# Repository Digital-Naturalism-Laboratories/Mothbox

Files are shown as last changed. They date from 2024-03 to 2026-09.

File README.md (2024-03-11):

# Mothbox
Developing an open source,low cost automated system for Moth-Lighting photography 





look at the wiki for up to date information on assembly and usage
https://github.com/Digital-Naturalism-Laboratories/Mothbox/wiki

It's a compact, low cost device you can get running with simple modifications of off-the-shelf parts! And no soldering really needed!


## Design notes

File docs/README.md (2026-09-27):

# Updates: 
The project has grown so much that we are in the process of re-organizing the github. 
Other parts of the repo will be split out into separate repositories such as:
* Post-Processing [Mothbot Process](https://github.com/Digital-Naturalism-Laboratories/Mothbot_Process) and [Classify](https://github.com/Digital-Naturalism-Laboratories/mothbot-classify)
* [Firmware (Rpi Scripts)](https://github.com/Digital-Naturalism-Laboratories/Mothbox_Firmware)
* [Hardware](https://github.com/Digital-Naturalism-Laboratories/Mothbox_Hardware)
* [Electronics Development (PCB)](https://github.com/Digital-Naturalism-Laboratories/Mothbox_Electronics)
* [Data Visualization](https://github.com/Digital-Naturalism-Laboratories/Mothbox_DataVisualization)

This main github repo will continue to host the
* Documentation / Website
* History of the project up to February 2026

To make it easier to access specific files or scripts.

# Mothbox Pro and DIY
The Mothbox is a low-cost, [high-performance insect monitor](https://digital-naturalism-laboratories.github.io/Mothbox/docs/about/specs/). It features a power efficient and lightweight design meant to help field biologists deploy it in the depths of the jungles, and its low-cost nature means you can build one to study the biodiversity at your home!

All the physical designs, electronics schematics, Pi Scripts, and insect-IDing Artificial Intelligence are **provided free and open source**, so you can build, share and improve on these designs yourself!

See the project website for all the details:
[https://digital-naturalism-laboratories.github.io/Mothbox/](https://digital-naturalism-laboratories.github.io/Mothbox/)

See the [full specifications of what it can do here.](https://digital-naturalism-laboratories.github.io/Mothbox/docs/about/specs/)

PXL_20240720_054408351 MP-EDIT



## What it Does

The Mothbox stays in an ultra low-power state until your schedule tells it which nights to wake up. Then it triggers an insect lure (usually a bright UV light) and then takes ultra-high resolution photos of the visitors it attracts. 
PXL_20240607_025924783 NIGHT-EDIT

Next we created some open-source AI scripts that process these insects for you. First, a trained YOLO v8 detects where all the insects are in the images and crops them out. 




Then we use BioCLIP via the [pybioclip](https://github.com/Imageomics/pybioclip) package, with a [FiftyOne](https://github.com/voxel51/fiftyone) user interface, to help you automatically group and ID the insects to different taxonomic levels!


# Build it Yourself!
PXL_20240810_155421647 MP

This Mothbox documentation will provide you with documentation for how to source, build, program, and use your mothbox!

[Get started building your mothbox!](https://digital-naturalism-laboratories.github.io/Mothbox/docs/building)

After following these guides, you should be able to make your own set of mothboxes to conduct your own biodiversity studies!




## Why Study Insects for Conservation?
Insect populations can be used as an ultra high resolution sensor for changes in environments.

### Insects (Especially Moths and Beetles) are Hyperdiverse
Of all life on earth (including bacteria) there are about 2 million species scientists have described and [half of the species are insects!](https://ourworldindata.org/how-many-species-are-there#:~:text=In%20the%20chart%2C%20we%20see,reptiles%2C%20and%20over%206%2C000%20mammals.) What's more, if you look at **just Moths** there are about 144,000 species, meaning **about 1 in every 14 species in the world is a moth!** For reference there are only about 11,000 bird species, and only 6500 species of mammals (and half are bats and rodents). 

Using creatures with a super diverse gene pool allows us to make sophisticated insights into the health of different areas. Combining the activity of thousands of species of insects with other data like climate, acoustic, or soil analysis, can provide deep analysis into how environments can be repaired.

### Offer Highly Localized Insights
Because they tend to have short lives and often limited ranges, insects can provide super localized data. 

For comparison, think about something like a Jaguar, which is a rare find and scientifically valuable to see on a wildlife camera, but they have large ranges and long lives. The presence of a Jaguar does not necessarily tell us much about the health of the environment where it was spotted. It could simply be travelling across disturbed farmland to escape from a destroyed habitat elsewhere. 

Having an insect sensor (like a Mothbox), however, that could compare the activity of thousands of different species of insects can highlight differences in environmental health in areas just a couple kilometers apart.

### They are Easy to Attract
Humans have long ago discovered that many nocturnal insects like Moths seem to be attracted to lights. We now know this is because [bright lights disorient their natural steering mechanism](https://www.nature.com/articles/s41467-024-44785-3). Scientists have used bright artificial lights for over a century now to take censuses of insect populations. The problem with this type of "Mothlighting" is that it can be incredibly time consuming (a scientist has to hang out all night and note which insects are visiting). Instead we have an automated device that does all this work for you!

# Mothbeam
We are also building an open-source, portable low cost light for mothlighting, the Mothbeam! Some early documentation for [making your own Mothbeam is here.](https://digital-naturalism-laboratories.github.io/Mothbox/docs/building/mothbox_diy/attractor/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)


PXL_20240718_190826331 MP

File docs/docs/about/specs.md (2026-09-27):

---
layout: default
title: Specifications
parent: About the Mothbox
has_children: false
nav_order: 1
---

The exact specifications of the mothbox may change depending on factors like which microcontroller or power source you choose.

## Physical Size
* Weight: 2500 grams
* Size: 11"L x 7"W x 4"H (box)
* Target Sizes
  * Standard: 29cm x 20.5cm
  * Dual: 41cm x 29cm
  * Quad XL: 54cm x 41cm

## Cost

* Approximate cost: $375

## Power

* Battery: Talentcell PB120B1 - 12V Lithium ion, Rechargeable 142.08Wh 38400mAh
* [Additional Power Inputs](https://digital-naturalism-laboratories.github.io/Mothbox/docs/building/external_parts/powersources/):
  * Solar (up to 18V 60 watts),
  * Extra Batteries
    * can [daisy chain up to 3 Talentcell PB120B1 batteries](https://digital-naturalism-laboratories.github.io/Mothbox/docs/building/external_parts/powersources/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)
    * or connect other DC batteries (like a car battery)
  * continuous DC power (can plug into a wall if near a power grid)
* Sleep time: 6 months
* Runtime: 18 hours continuous (1 minute photography intervals with 2 internal mothbeams at standard power setting)
  * About 85% of the power goes to the UV attractor connected. Lower power UV lights can last longer, higher power lights will reduce its runtime
  * Our standard schedule has 5 hours of runtime per night, which means a normal Mothbox can run for 4 nights before recharging.

## Imagery
* Camera: Arducam 64mp Owlsight OV64A40
* Image resolution: 9152×6944 (Pi5)  9000x6000 (Pi4)
* Lens Adapter size: 55mm
* Pixels per mm: 15 (based on standard-sized target distance)

## Weatherproofing
* Fully harsh weather resistant. Has been left outside for >1 month in the rainforest.
* Probably not submergable (don't use mothbox underwater, yet)

## Microcontroller  
* Microcontroller: Raspberry Pi5 (2GB or 4GB)

## License
* MIT License
* CERN OHL-W

The Mothbox is an open source hardware and software tool for science. All the aspects of the Mothbox are freely licensed so that you can make it yourself, remix, customize, and build upon. The only things you cannot do are stop others from using this, claiming these designs or ideas as your own, or holding us liable for any aspect of this device. It is a build and use at your own risk tool.

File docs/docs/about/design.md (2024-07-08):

---
layout: default
title: Design Concepts
parent: About the Mothbox
has_children: false
nav_order: 6
---
The Mothbox is a tool for studying insect biodiversity, but the way in which is was created aimed to incorporate several key design concepts.

# Replicable
## Open Source
First and foremost, this is an open-source science project! Like **EVERY** scientific tool, all the information in the hardware and software should be freely available. This is extremely important as the scientific process is broken if the tools used to conduct research are not open and accessible. All the software, hardware designs, and documentation is provided free to use and at your own risk without warantee. 

The Open source nature of this is also important to science since it allows other researchers to remix and redesign this project to fit the purposes of other projects. For instance, another researcher is already remixing a mothbox to take high resolution scans of 96-well plates growing various fungi.

## Off-the-shelf parts

## Low Cost

# Simple Flat Design

The mothbox is designed so that all parts can be cut from flat planar material. It is more difficult to design a complex 3D electronic device using only 2 dimensional pieces, but there are several reasons for choosing this approach.

## Cross-Compatibility with multiple manufacturing techniques
Objects that are designed flat can be used in a wide variety of manufacturing techniques. Objects that are designed to be 3D printed generally can only be reproduced by 3D printers.
Instead these devices can be Laser cut, water-jet cut, CNC milled, 3D printed, cast, or even printed onto paper, traced, and manually cut out of something like 3mm plywood. Fully 3D objects intended to be 3D printed can be dif

## Speed of manufacturing
Flat parts can also be rapidly quickly. An entire mothbox can be laser cut in under 20 minutes, whereas a 3D printed version could take several hours. This is especially important to us as the designers since we are rapidly changing around the design to hone its abilities as a field instrument.

#Iterative Contextual Testing

# Field Repairable

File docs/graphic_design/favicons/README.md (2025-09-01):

# croppedlogonotext_4000px_Transparent_Square_Colored - Favicon Package

This package contains all the favicon files and configuration needed for complete browser and platform support.

## 📁 Files Included

### Standard Favicons
- `favicon.ico` - Traditional favicon (16x16, 32x32, 48x48)
- `favicon-16x16.png` - Small favicon for browsers
- `favicon-32x32.png` - Standard favicon for browsers

### Apple Touch Icons
- `apple-touch-icon-180x180.png` - iPhone 6 Plus, iPhone 6s Plus, iPhone 7 Plus, iPhone 8 Plus, iPhone X, iPhone XS, iPhone XS Max, iPhone 11 Pro Max
- `apple-touch-icon-152x152.png` - iPad, iPad mini
- `apple-touch-icon-120x120.png` - iPhone 6, iPhone 6s, iPhone 7, iPhone 8, iPhone SE
- `apple-touch-icon-76x76.png` - iPad (iOS 7+)
- `apple-touch-icon-60x60.png` - iPhone (iOS 7+)

### Android & PWA Icons
- `android-chrome-192x192.png` - Android homescreen icon
- `android-chrome-512x512.png` - Android splash screen icon
- `site.webmanifest` - PWA manifest file

### Microsoft Tiles
- `mstile-150x150.png` - Windows 8+ tiles
- `browserconfig.xml` - Microsoft browser configuration

### Additional Files
- `favicon-meta-tags.html` - Complete HTML meta tags
- `README.md` - This file

## 🚀 Installation

1. **Upload all files** to your website's root directory
2. **Copy the HTML meta tags** from `favicon-meta-tags.html` into your website's `<head>` section
3. **Test your favicons** using online favicon checkers

## 💡 Usage Tips

- Place all files in your website's root directory (e.g., `https://yoursite.com/favicon.ico`)
- The HTML meta tags should be placed in the `<head>` section of every page
- Test on different devices and browsers to ensure proper display
- Consider using a CDN for better performance

## 🔧 Advanced Configuration

### PWA (Progressive Web App)
Your `site.webmanifest` file enables PWA features:
- Add to homescreen functionality
- Splash screen customization
- App-like experience on mobile

### Microsoft Integration
The `browserconfig.xml` file configures:
- Windows 8+ tile colors
- Tile icon selection
- Browser-specific settings

## 🌟 Features

- ✅ Complete browser support (Chrome, Firefox, Safari, Edge, IE)
- ✅ All device support (Desktop, Mobile, Tablet)
- ✅ Platform integration (iOS, Android, Windows)
- ✅ PWA ready with manifest.json
- ✅ Optimized file sizes

## 📱 Supported Platforms

- **Web Browsers**: Chrome, Firefox, Safari, Edge, Opera
- **Mobile**: iOS Safari, Android Chrome, Samsung Internet
- **Desktop**: Windows, macOS, Linux
- **Tablets**: iPad, Android tablets
- **PWA**: Progressive Web App support

## 🛠️ Generated with

This favicon package was generated using [Favicon AI](https://favicon-ai.com) - the free favicon generator with AI-powered optimization.

---

Need help? Visit [Favicon AI](https://favicon-ai.com) for more favicon tools and resources.

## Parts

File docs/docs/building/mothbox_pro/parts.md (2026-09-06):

---
layout: default
title: Parts
parent: Mothbox Pro
#has_children: true
nav_order: 0
---
# Parts

To build a Mothbox Pro, you will need these parts (prices are estimates and fluctuate):
- [Download 3D Printed parts](https://github.com/Digital-Naturalism-Laboratories/Mothbox_Hardware/tree/main/Mothbox_Pro/)
- [Download Laser cut parts](https://github.com/Digital-Naturalism-Laboratories/Mothbox_Hardware/tree/main/Mothbox_Pro/Laser%20Cutting)

MB pro all parts 20260209_160744

## Electronics
This newest version of the Mothbox has easy to assemble electronics! You only need



* [Mothbox Mainboard](https://digital-naturalism-laboratories.github.io/Mothbox/docs/building/mothbox_pro/manufacture/) - a Printed Circuit Board (PCB) with most electronics already connected up for you! - $50
* [Mothbeam Boards](https://digital-naturalism-laboratories.github.io/Mothbox/docs/building/mothbox_pro/manufacture/) - Little, super bright, metal LEDs that plug in to your Mainboard (up to 3) - $5 each
* [Raspberry Pi 5 4GB](https://www.sparkfun.com/raspberry-pi-5-4gb.html) (or higher) - $75  (Our latest firmware LOOKS like it works with a [Pi 5 2GB](https://www.sparkfun.com/raspberry-pi-5-2gb.html), but we have not thoroughly tested)
* [SD Card](https://www.amazon.com/dp/B0CQX2B25W?ref=ppx_yo2ov_dt_b_fed_asin_title) - 32GB or bigger, Class A1 or faster (A2 is nice) - $15
* [USB Storage](https://www.amazon.com/dp/B0BN3Q1M96?ref=ppx_yo2ov_dt_b_fed_asin_title) - 32 GB or bigger
* [Pi 5 RTC Battery](https://www.sparkfun.com/raspberry-pi-rtc-battery.html) - $8
* [Talentcell PB120B1](https://www.walmart.com/ip/Millertech-PB120B1-12V-Lithium-ion-Talentcell-Battery-Pack/5119418367) - You can actually use any battery between 9-36 V to power the mothbox (it's more efficient around 12V), but for these tutorials we will use the main battery we use for all our devices, this one by Talentcell - $80
* [9-36V to 12V voltage Regulator](https://www.amazon.com/dp/B0B6VK8BPN?ref=ppx_yo2ov_dt_b_fed_asin_title) - $15
* [Arducam 64 MP Owlsight camera](https://www.amazon.com/dp/B0CQJPKFVF?ref=ppx_yo2ov_dt_b_fed_asin_title) - $55 (Don't get the "Hawkeye" older version of this camera if you can avoid it!)
* [Barrel Jack Sockets and Plugs](https://www.amazon.com/dp/B0D9B7WR23?ref=ppx_yo2ov_dt_b_fed_asin_title) (x2) - $2
* [Lever Nut](https://www.amazon.com/dp/B0CBP7WWML?ref_=ppx_hzsearch_conn_dt_b_fed_asin_title_1&th=1) - 2 wire connector - $0.40
* (Optional, but VERY USEFUL) [Epaper Display (Waveshare 2.13in E-ink hat)](https://www.amazon.com/dp/B0D22JJ18B?ref=ppx_yo2ov_dt_b_fed_asin_title) - $15



## Attractors

* [Mothbeams](https://github.com/Digital-Naturalism-Laboratories/Mothbox_Electronics/tree/main/Mothbeam_PCBs/AndyMothbeam_forMBv5.0.1) can plug right in to the PCB
* External - You can also connect any 12V attractor you want via the "External attractor" port

## Zip Ties
  * [7 really thin ones](https://www.amazon.com/dp/B07W98YW6J?ref=ppx_yo2ov_dt_b_fed_asin_title)
  * 8 typical width
  * 2 really big

## 3D printed parts
[Download 3D Printed parts](https://github.com/Digital-Naturalism-Laboratories/Mothbox_Hardware/tree/main/Mothbox_Pro/)
We used [PETG-Carbon Fiber](https://www.amazon.com/dp/B0FC6H71B1?ref=ppx_yo2ov_dt_b_fed_asin_title) (regular [PETG](https://www.amazon.com/dp/B0FC6H7FBL?ref=ppx_yo2ov_dt_b_fed_asin_title) will also be fine) and [TPU Filaments](https://www.amazon.com/dp/B0B6FMVJ2H?ref=ppx_yo2ov_dt_b_fed_asin_title&th=1)


  
  * Inner Chassis
  * Outer Shell
  * Camera Glare Blocker
  * Front Lid
  * Back Lid

For really wet places
  * TPU Gasket - Front
  * TPU Gasket - Back

## Laser Cut Parts
[Download Laser cut parts](https://github.com/Digital-Naturalism-Laboratories/Mothbox_Hardware/tree/main/Mothbox_Pro/Laser%20Cutting)

  * Front Acrylic Window
  * Arms
  * Target
  * (Includes alternative files for if you want to laser cut your front and bask gaskets with [laser cutting rubber](https://www.amazon.com/dp/B08Q7CTSJL?ref_=ppx_hzsearch_conn_dt_b_fed_asin_title_12) instead of printing in TPU)

## Connectors
To hold the lid on and the legs on you have 3 options:
* Re-usable zip ties
* Rubbery Silicone Ties
* 3D printable TPU ties

## Screws
* #6 x 3/8" screws (or 6g x 9mm)

# Tools
Here's some tools you need:

* Screwdriver
* Wire Strippers
* Hot Glue Gun

Bonus tools could also be useful:
* Flat Snips (Scissors could maybe work too)

**Total Estimate: $350**

# Bonus Parts
You can also add:
* [Cheap Epaper display](https://www.waveshare.com/2.13inch-e-Paper-HAT.htm) - ($15USD) to know what your Mothbox is up to!
* External temperature sensor - Connects to a port on the PCB
* Cheap GPS - gives super accurate timestamps and can automatically locate your mothbox - plugs in to ports on PCB - [5 pin](https://www.amazon.com/dp/B0B31NRSD2?ref_=ppx_hzsearch_conn_dt_b_fed_asin_title_1) or [4 pin](https://www.amazon.com/dp/B0CWL774NR?ref_=ppx_hzsearch_conn_dt_b_fed_asin_title_1)

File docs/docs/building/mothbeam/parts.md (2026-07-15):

---
layout: default
title: Parts
parent: Mothbeam (Insect Attractor)
#has_children: true
nav_order: 1
---

# Parts

For this tutorial, we will show you how to make a very simple mid-range housing we call the "Basic Circular Housing"



# Parts for Basic Circular Housing
* [PCBs](https://github.com/Digital-Naturalism-Laboratories/Mothbox_Electronics/tree/main/Mothbeam_PCBs/AndyMothbeam_forMBv5.0.3) (ideally 2 or 4)
* 18awg solid core wire (red and black)
* 20x20 aluminum profile (15cm long)
* Circular Plexiglass tube, 6.5cm diameter (make sure transparent to UV) (10cm long)
* Laser cut acrylic [Top and Bottom lid](https://github.com/Digital-Naturalism-Laboratories/Mothbox/tree/main/Hardware/Mothbeam_Housing/Mothbeam_CircularHousing)
* Cable Ties (Basic nylon high heat resistant) (Preferably very thin)
* (optional) Silicone heat transmitting pads
* (optional) DC barrel jack (socket and plug)
* (optional) Electronic Snap connectors

# Tools Needed
* Hot Glue Gun (Or epoxy)
* Wire Strippers
* Saw (if needing to cut housing tube or metal)



# Core Component Overview
A mothbeam is easy to put together and has 3 main parts:

* PCB
  * The electronic LED board that shines really bright (generally UV or Visible Options)
  * generally made on alumnimum backing to help shed heat. (Copper could work too, but it's expensive!) 
* Heatsink
  * usually a piece of metal to help dissipate the heat to give the LEDs a longer life
* Housing
  * Something to protect the electronics from travel or the elements

## PCB

The PCB's are a [certified open source hardware design originally by Moritz](https://certification.oshwa.org/de000156.html). We have [remixed them to easily connect to our Mothbox PCB](https://github.com/Digital-Naturalism-Laboratories/Mothbox_Electronics/tree/main/Mothbeam_PCBs/AndyMothbeam_forMBv5.0.3).

To get one, you can:
* order a Mothbeam directly from Moritz in Germany emailing him (moritz@lablab.eu)
* use the [open source files](https://github.com/Digital-Naturalism-Laboratories/Mothbox_Electronics/tree/main/Mothbeam_PCBs/AndyMothbeam_forMBv5.0.3) to create your own PCBs yourself (or via something like JLCPCB) (remember they need to be aluminum PCBs)
* [order them from something like circuithub](https://circuithub.com/projects/Moritz/Mothbeam/revisions/57895/parts) (the most expensive way)

## Heatsink
The heatsink just needs to be something big and metal we can connect the PCB to.

## Housing
The flexibility of this low cost device means you can put together different types of housings however you need.

You can go super low-cost and just put it in a recycled sports-drink bottle



or you can [laser cut a fancier flat-pack design](https://github.com/Digital-Naturalism-Laboratories/Mothbox_Hardware/tree/main/Mothbeam_Case/Mothbeam_Flatcontainer)



you can even use the basic concepts in this tutorial and make a "Mega Mothbeam" by just using more PCBs and longer heatsink.



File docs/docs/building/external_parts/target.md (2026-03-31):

---
layout: default
title: Create Target
parent: External Parts
#has_children: true
nav_order: 4
---

There's many ways point your Mothbox at something! Here are the [laser cutting design files for your target!](https://github.com/Digital-Naturalism-Laboratories/Mothbox_Hardware/tree/main/Targets)

The Mothbox's default software will automatically calibrate its focus and exposure to whatever kind of target is positioned in front of it. The main thing is that it should probably be 
* white
* flat
* easy for insects to perch on

PXL_20240808_232453558 MP

We have found that acrylic felt works quite well for insects to walk around on, to stay clean and not mold, and as a bright, light-diffusing backdrop.

# Target Options
We have four main options for your target. We have done most of our testing with the Standard Target, so the other options are still a bit more experimental.

The [Standard Target](https://digital-naturalism-laboratories.github.io/Mothbox/docs/building/external_parts/target/#standard-target) is the most compact surface for the Mothbox. It also can be lit up quite easily from lights inside the mothbox.

The [Minimalist Target] was inspired by the Lepisense crew who have been using just a peice of rough-surfaced acrylic. You can just purchase "textured" acrylic sheets in some places, but if that's not available, we have used a rough-grit sander to just roughen one side of a piece of acrylic. Follow the same instructions as the "Standard sheet" but don't worry about the felt part. Just sand it to rough it up after.

The [Dual Target](https://digital-naturalism-laboratories.github.io/Mothbox/docs/building/external_parts/target/#dual-target) doesn't require any additional materials other than cutting an extra target shape. It can also fold in half so it doesn't take up much more room than the Standard Target! So you can pretty much double your target area with minimal changes.

The [Quad Target](https://digital-naturalism-laboratories.github.io/Mothbox/docs/building/external_parts/target/#quad-target) is 4X bigger than the standard target. Because of its size, it is not as easy to travel with. This large target also needs to be positioned further away from the Mothbox, which means the amount of pixels per insect will be reduced. It can work great for areas where you are looking for larger and abundant moths.

The ["Just Point it at Something"](https://digital-naturalism-laboratories.github.io/Mothbox/docs/building/external_parts/target/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) option works if you have some other surface you are using as a moth target. You can use the arms to measure a distance if you want, but you can just point the Mothbox at a wall or sheet. 

# Standard Target
Building the targets is straightforward. You just glue the target material to the target. Using a spray adhesive tends to work well.



1. Spray one side of your target material with glue.
2. Make sure the protective plastic is peeled off the acrylic target
3. Lay the target material on top of the side of the target with the inverted logo. You will be covering up the logo.
4. Lay some clean, heavy, flat things on top of the target (to help make it extra flat)
5. Let dry for a couple hours




# Dual Target
The process is similar to the Standard Target, but you need to cut out two target surfaces. Put their smooth, long edges together.
PXL_20240808_200847224 MP

Spray the double-wide target material felt with the adhesive spray.

Carefully align it with the two target backings.
PXL_20240808_201107616 MP

Place something clean, flat, and heavy on top of them.

PXL_20240808_201146040 MP

Now the Double Wide target material functions as a sort of hinge you can use to close the target and protect it when in transit. You probably need to tape the back when deployed to keep it rigidly open. This probably could use a design tweak.

## Prepare Arms for Dual Target

The dual target can fit at the end of the arms in their standard configuration, but they will fill up the camera image entirely. If you want to have a safe margin around the edges of the dual target, you can adjust the arms one notch outward, which moves them about 7 cm outward.

# Quad Target
PXL_20240808_233028726 MP

The quad target design is the size of 4 of the standard targets. If you are desperate, you could literally just set 3 standard targets next to each other in a square and tape them all together.
But the stability might be weird.

Instead, we included a design to cut out a single large target. We used coroplast (corrugated plastic polypropylene). It's lightweight, sturdy, an cuts easily. You can also make it foldable by making a slit up one side of the corrugation,but you will need to figure out a way to make it sturdy. Some tape will work.

Cut out your large target.
PXL_20240808_161011251 MP

Cut out its felt material.

PXL_20240808_162242291 MP

Spray the felt material with spray adhesive.

PXL_20240808_200351402 MP

PXL_20240808_200439729 MP

Lay a clean, flat, heavy thing on top.

PXL_20240808_200658541 MP

PXL_20240808_200753893 MP

Let dry for a couple hours.

## Prepare Arms for Quad Target
Stagger your arms with some extra bolts.

PXL_20240808_190821702 MP

With the extra large target, it might make sense to use the [External Attractor](https://github.com/Digital-Naturalism-Laboratories/Mothbox/blob/main/docs/docs/building/attractor.md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) option since it is a bit further from the Mothbox.

PXL_20240808_234505819 MP

# Just Point it at Something
Depending on your setup, you might not actually need a dedicated target! We have used the Mothbox by just pointing it at a **white wall** with a bright light that insects were attracted to. Many people want to just point their mothbox at a sheet that they have hung up for traditional Mothlighting. This can totally work, BUT some things to keep in mind:
* The mothbox will autocalibrate its focus and exposure, but it only does this about every 6 minutes. Thus if it is pointing at a surface that sways or moves back and forth (possibly like a sheet in a light breeze), many of these images will not be in focus.
* The Mothbox is trying to image a full surface, which is different than when you try to take pics individually of specific insects on a moth sheet. Its visual field should be of a surface that is **as flat as possible,** or else parts of the image may be occluded by wrinkles.
* The lighting near the edges of a surface may not be as well illuminated as those near the middle.

PXL_20240905_120604101 MP

# Cleaning Target
Moths can be a bit grosser than you might think. They can poop a LOT. Look at this target I came back to one night. It got real gross.


## Bleach

You can use a 20% solution of bleach to scrub out most stains. Try not to rub too hard or the felt can get too fluffy, but in general it's quite easy to clean.
PXL_20240828_212120926 MP

## Have Backups Ready

Felt is cheap and lightweight, and you should probably have extra target material cut and on hand in case your current target accidentally gets messy.

We even upcycled our old felt together with old acrylic by just melting them all together with acetone.
PXL_20240822_162510025 MP

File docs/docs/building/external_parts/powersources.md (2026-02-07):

---
layout: default
title: Solar and Extra Batteries
parent: External Parts
#has_children: true
nav_order: 9
---

The Mothbox has an internal battery that can sample for about 4 nights on its own (22 hours of runtime). BUT maybe you want a SUPER POWERED Mothbox that can last even longer?!

Well, it's very easy to add solar panels or extra batteries to the Mothbox!

# Add a Solar Panel

This is pretty easy to do! Simply plug a DC barrel jack cable from your panel to the charging port.
PXL_20240810_225301762 MP

That's it!

PXL_20240810_225422782 MP

We talked to the Talentcell people who make the batteries. They said lots of solar panels will work, especially 18V panels up to 60Watts.**

{: .important }
> Panels should be max 18V and 60 watts

# Add Extra Batteries

This is also quite an easy addition. You can just plug a DC barrel jack cable from the output of one Talentcell battery to the input port of another! Easy as that! You just need to make sure that both batteries are fully charged.

{: .important }
> All batteries need to be fully charged if you connect them.

## Build a waterproof battery pack
You can make an extra power case to connect to your Mothbox in the field very easily. You just need an additional waterproof case.
You can drill a port exactly the same as when you create the input port for your Mothbox.
PXL_20240805_151231476 MP

Add a DC barrel socket to it. Connect a barrel jack plug with a lever nut. 
PXL_20240805_152446615 MP

Plug it into the OUT port of an extra Talentcell battery.
PXL_20240805_152622741 MP

Seal up the box and plug it into the input port of your fully charged Mothbox.
PXL_20240805_152712736 MP

## Double Battery Pack?
You bet! Again just make sure all the batteries are charged up fully.
Use a DC cable jack splitter (one usually comes with your Talentcell battery!)

PXL_20240805_152841330 MP

Plug it into BOTH OUTPUTs of the batteries in your pack.



And you are ready to have a Mothbox that can run for 66 hours! Or 12 nights!
PXL_20240805_153000284 MP

# Differentiating between 12V and 24V batteries

The easiest way to tell the difference is by looking at the back of the battery and see what voltage is listed under the input. The 24V one will say 29.4V and the 12V will say 12.6V.

12vMBbattexample 

*Example of a 12V battery*

24VMBbattexample

*Example of a 24V battery*

Another easy trick is that you'll notice the 12V batteries don't list the voltage on their sides, whereas the 24V one does. The 24V battery also has a little "groove" that sticks out further than the 12V one

Screenshot 2025-02-27 at 1 16 54 pm

Screenshot 2025-02-27 at 1 17 04 pm

A reminder that all 12V batteries are charged by a *black* charger, and all 24V batteries are charged by a *white* charger!

# More information on daisy chaining batteries

Do not charge batteries that are in parallel! It's ok to keep two batteries daisy chained together in parallel when charging *another* battery (i.e, the one in your Mothbox), but directly charging (i.e, from a wall plug) batteries in parallel can damage them. Make sure that when you are daisy chaining two or more batteries, the batteries all begin at the same charge level.

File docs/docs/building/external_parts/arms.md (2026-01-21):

---
layout: default
title: Arms
parent: External Parts
#has_children: true
nav_order: 3
---

# Arms 
Simply laser cut the dxf files out of clear acrylic (this helps give more surface area to your target). If needed you could use an opaque material.

{: .note }
> Each arm of the mothbox is made from 2 arms. This is for strength as well as redundancy. If one arm breaks in the field, you already have a backup!

# Peel the Plastic
Pull the protective plastic off the arms.


# Attaching Arms

## Off-the-shelf Case
Use 1/4in bolts to connect the arms to the box

## 3D Printed Case
With the 3D printed case you have multiple options for connecting the arms!

You can use 1/4 in bolts like before.


You can use re-usable cable ties.


Or, my favorite, is to use rubbery re-usuable ties.




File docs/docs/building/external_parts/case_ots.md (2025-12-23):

---
layout: default
title: Case (Off-the-Shelf)
parent: External Parts
#has_children: true
nav_order: 1
---

If your 3D printing capactity is limited, you can modify an off-the-shelf case that will protect your electronics
This is the Plano 1460-00 box. Others have also modified waterproof junction boxes with clear lids in a similar way.

The Mothbox has 2 main *external parts* that connect to the case
* Lens Connector
* Arms

# Modify the Box

## Drilling Arm Holes
You should start with 4 laser cut arms. 

{: .note }
> Each arm of the mothbox is made from 2 arms. This is for strength as well as redundancy. If one arm breaks in the field, you already have a backup!

Lay an arm against the outside of the large plastic flanges.


Use a marker to mark exactly where the holes are.
Using a 1/4in drill bit (6.5mm), cut two holes for the arm.

{: .note }
> I actually use a drill bit that is slightly larger than 1/4in, like 5/16in because my measuring and aligning abilities aren't always that great, and this gives you a little wiggle room.

Slide two 1/4in bolts through the holes and secure the arms.


Now you should be able to attach the target to the arms easily!


## Drill Front Lens Hole
These boxes are manufactured with a little dot directly in the center of the back of the box. 
You can use this as a reference point to drill a small pilot hole. When drilling this side of the box for the lens, make sure to always use a light pressure, as you don't want to press too hard and crack the box. 


After you have drilled the pilot hole, you can get out your 53 mm hole cutter bit. Align this bit with the pilot hole and drill out your hole.



Sometimes the edge of this hole can be a little rough and have extra plastic sticking up that can get in the way. You can use a deburring tool, or a razor, and go along the edge of this cut to clean it up.




## Epoxy the lens adapter into place

Mix together some 2-part epoxy on a piece of cardboard with a popsicle stick. 




Put a little bit of epoxy onto the rim of the hole you just cut. Add the lens adapter. Use a thin stick to slide around the edge and make sure the epoxy seeps into the seam between the lens connector and box. Look for air bubbles coming from the seam.


Then you can use a larger popsicle stick to smooth out the border of the epoxy and have a nice, thick seam connecting them.


Use a towel to clean up any epoxy that may have spilled on the inside of the lens adapter.


Once it is in place, and the epoxy is smooth and thick, let it sit aside for several hours to cure.





After the epoxy has dried, sometimes you may notice some white smudges inside your mothbox. It's not a big problem. These are from the fumes of some glues attaching to oils left from your fingers. This is actually how people do fingerprinting sometimes! You can just wipe it off with a clean, damp cloth.



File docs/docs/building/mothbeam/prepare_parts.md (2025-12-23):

---
layout: default
title: Prepare Parts
parent: Mothbeam (Insect Attractor)
#has_children: true
nav_order: 3
---



# Prepare Heatsink

You will either need to find a 15cm length of aluminum, or cut a piece yourself.


If you need to cut it, wear safety goggles and use a hacksaw or jigsaw with metal blade.





After it has been cut, make sure to let it cool, the fresh part can be quite hot!

Debur any metal bits on the edge. Remove any protective plastic.


# Prepare Acrylic Tube

You need a 10cm acrylic tube with a 6.5cm diameter (none of these measurements need to be too exact).


Generally you will find acrylic tubes in longer lengths you need to cut.

Use a plastic blade on a saw and cut off your tube.



# Laser cut end caps
You can use the designs to laser cut end caps for your acrylic tube. If you are using a different metal rod, you can always change the cutout to the profile of whatever rod you use!



If you want to be really fancy, after you etch the text, you can spray paint your acrylic (if it still has the protective plastic on it).




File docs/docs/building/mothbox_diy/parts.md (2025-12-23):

---
layout: default
title: Parts List
parent: Mothbox DIY
#has_children: true
nav_order: 1
---

The Mothbox uses a Raspberry Pi 5 (or Pi4 and Pijuice), a Talentcell Battery, and a 3 channel relay as its core.
The entire materials cost is **about $375** per mothbox. (This depends on the options you choose and the prices where you live). Note that many other similar tools for insect monitoring can cost between $7-$15K!

Below we try to include an up-to-date list for building an arbitrary number of Mothboxes.

Here's a [link to a list of most of the parts collected for you.](https://www.amazon.com/hz/wishlist/ls/3J2HLUOYNFFZG?ref_=wl_share)

# Electronics

## Core Electronics ($233)

### Raspberry Pi and Scheduling Devices
* [Raspberry Pi 5 (4GB and up)](https://www.sparkfun.com/products/23550) ($60)
  * you also need an SD card for the Pi. You should find one with speeds rated "A2" or higher. 64gb and up is nice.
* **plus** a [rechargeable RTC battery](https://www.sparkfun.com/products/23590) ($5)
* [USB A to C power cables (SHORT)](https://www.amazon.com/gp/product/B0C4NJYPTX/ref=ppx_yo_dt_b_search_asin_title?ie=UTF8&th=1)

OR
* [Raspberry Pi 4 (4GB and up)](https://www.sparkfun.com/products/15447) ($55)
* **plus** a [Pijuice](https://www.sparkfun.com/products/14803) ($100)
   * [Info Software](https://github.com/PiSupply/PiJuice)

### Camera

* [Arducam 64MP Autofocus Camera (Updated "Owlsight" "Native Libcamera" version)](https://www.amazon.com/Arducam-Raspberry-Resolution-Support-Libcamera/dp/B0CQJPKFVF?ref_=ast_sto_dp) ($60)
  * Make sure to get the above version called "Owlsight" (It's much easier to work with than the older "Hawkeye" version of Arducam's camera)  

### Power
* Battery : [Talentcell 12V Lithium ion Battery PB120B1](https://www.amazon.com/gp/aw/d/B07H8F5HYJ?psc=1&ref=ppx_pop_mob_b_asin_title) ($80) - This is the easier battery to work with, all 12V in and out.
* OR [Talentcell PB240b1](https://www.amazon.com/gp/product/B07SWBS55F/ref=ppx_yo_dt_b_asin_title_o00_s00?ie=UTF8&psc=1)  The PB120B1 started going out of stock sometimes, but this updated model should do fine (and has more battery capacity!). The downside is it can be a little trickier to wire up, because it has a 12V and 24V output, so you need to be careful!

* Relay Expansion Pi Hat (Waveshare 3x relay) ($18)
    * [Buy](https://www.amazon.com/RPi-Relay-Board-Raspberry-3-CH/dp/B085QJFWBC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)
    * [Info](https://www.waveshare.com/wiki/RPi_Relay_Board)
    * Remember you can also wire individual relays, but not solid state relays (they can't switch low DC voltage).
* 12V regulator / Step-Up Voltage Booster
   * [Buy](https://www.amazon.com/Stabilizer-DROK-Waterproof-Transformer-Television/dp/B081RG8XP5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)
   * This extends your battery life by keeping power to the 12V lights even if your battery voltage starts dipping low.
* [5.5 x 2.1 DC barrel jack cables](https://www.amazon.com/gp/aw/d/B0BZYGRYSQ?psc=1&ref=ppx_pop_mob_b_asin_image)
    * 2x socket ports (You actually only need 1 socket if you are keeping your UV light internal)
    * 2x plug ports
* (Optional) Power sensor for monitoring battery levels
   *[Buy](https://www.amazon.com/gp/product/B07S8QYDF8/ref=ppx_yo_dt_b_search_asin_title?ie=UTF8&psc=1)    

### Display (Optional) (18$)
* The latest versions of the Mothbox firmware support inexpensive e-ink displays! This is not needed for operation, but can be very useful for debugging or organizing mothboxes!
* [Waveshare 2.13in Eink Hat](https://www.amazon.com/waveshare-2-13inch-HAT-Compatible-Resolution/dp/B071S8HT76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) 

### Lighting ($60)
* Photography Lights (2x)
  * 2x [12V 144 LED ringlight](https://www.amazon.com/Vision-Scientific-VMLIFR-09B-Adjustable-Microscope/dp/B07VR2LJJL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) ($23)
  * The 144 LED ringlights seem to be about the brightest diffuse 12V LEDs you can find for the price. They are also quite ubiquitous and a standard(ish) form factor.
  * Purchase 2 of them.
  * 2.55" (65mm) inside and 3.75" (95mm) overall outside diameters.
* UV lights
    * 12V
        * Any UV light that accepts a 12V input will work easily, such as 
               [Cheap 12V Waterproof UV flood](https://www.amazon.com/dp/B07KHVZ7TG?psc=1&ref=ppx_yo2ov_dt_b_product_details) ($13)
        *  We are also using our custom "Mothbeams," which are like powerful, open source, bespoke, low cost lepileds. It currently costs about $80 to order them from Moritz at LabLab in Berlin [moritz at lablab.eu]
          *  Or you can order them from [Circuithub](https://circuithub.com/projects/Moritz/Mothbeam/revisions/57895/parts), but there they cost about $200-$400.  
    * 5V (Not Officially Integrated)
        * To reduce costs and additional parts, we do not design around an extra 5V output, though you can install one yourself pretty easily.
        * You can hack the system to use UV lights that take a 5V input pretty easily with just an inexpensive [high power 12V to 5V adapter](https://www.amazon.com/gp/product/B076ZLHLD3/ref=ppx_yo_dt_b_search_asin_title?ie=UTF8&psc=1).
        * These light bars are the absolute cheapest ones we can find that attract moths ($5) (395nm) [https://www.amazon.com/Black-Light-Bar-Glow-Party/dp/B09BCND2J9/](https://www.amazon.com/Black-Light-Bar-Glow-Party/dp/B09BCND2J9/).
        * Lepileds can also be connected.

* DIY Heatsink (For internal UV Lights)
  * Perforated Metal
    * [1-1.5mm Aluminum works well](https://www.amazon.com/dp/B0CN4RMFYQ/ref=dp_iou_view_item?ie=UTF8&th=1)
  * Metal Shears are handy
    * [Example 'Avaiation' Shears](https://www.amazon.com/Hurricane-02-024-Aviation-Straight-Vanadium/dp/B07GDDF5JB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)
  * [Thermal Silicone Strips](https://www.amazon.com/gp/product/B094PWW9TM/ref=ppx_yo_dt_b_search_asin_title?ie=UTF8&th=1)
  
# The Box ($25)

* [Plano 1460-00](https://www.amazon.com/gp/product/B003FYMVXM/ref=ppx_yo_dt_b_search_asin_title?ie=UTF8&th=1) ($25)
   * To be as compact as possible, we designed around the Plano 1460-00 case. It's cheap, waterproof, CLEAR, [quite available internationally](https://www.amazon.co.uk/Plano-Waterproof-Polycarbonate-Storage-Yellow/dp/B003FYMVXM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), and as compact as possible.
   * (sometimes called plano 3600) 11"L x 7"W x 4"H </span>

## Chassis, Arms, and Target Materials
* Plastic for laser cutting (the design is currently set for 3mm acrylic)
   * One 50x60cm piece of acrylic can fit all the parts, but you could cut from many scraps too.
* [White Felt Acrylic sheets](https://www.amazon.com/9x12-Acrylic-Material-Fabric-Supplies-Halloween-Costumes-6PC/dp/B0848X2RFN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)
   * minimum 205x305mm (8x12in)

## Camera Lens Gear ($20)
_We are turning the box into a kind of 55mm lens camera so accessories that work for a 55mm lens should work_

* UV Lens Protector and Mount 
    * Lens rings [https://www.amazon.com/dp/B005IMNI4K?psc=1&ref=ppx_yo2ov_dt_b_product_details](https://www.amazon.com/dp/B005IMNI4K?psc=1&ref=ppx_yo2ov_dt_b_product_details) ($3)
    * UV filter [Amazon.com : Tiffen 55UVP 55mm UV Protection Filter : Camera Lens Sky And Uv Filters : Electronics](https://www.amazon.com/dp/B00004ZCJH?psc=1&ref=ppx_yo2ov_dt_b_product_details) ($8)
   * Lens Hood - not strictly necessary, but helps keep extra rain off lens when deployed.
     * [buy (includes lens cap)](https://www.amazon.com/gp/product/B082HRGFP7/ref=ppx_yo_dt_b_search_asin_title?ie=UTF8&th=1) ($9)

## Field Additions
* Strap (Optional-To attach to tree)
  * [e.g.] (https://www.amazon.com/gp/product/B08BYHZGC4/ref=ppx_yo_dt_b_search_asin_title?ie=UTF8&psc=1)
* Lock (optional - to attach to tree if theft is a concern)
  * [e.g.](https://www.amazon.com/gp/product/B000XTPNZK/ref=ppx_yo_dt_b_search_asin_title?ie=UTF8&psc=1) 

# Data
* Micro SD Card (Recommended 64 GB and higher)
  * e.g. [128gb Microsd cards](https://www.amazon.com/gp/product/B0BYJH4ZJL/ref=ppx_yo_dt_b_search_asin_title?ie=UTF8&psc=1)
* USB storage (reccomended 64GB and higher)
    * e.g. [usb thumb drive](https://www.amazon.com/gp/aw/d/B09LLWTMXQ?psc=1&ref=ppx_pop_mob_b_asin_title)
* [Short USB extension](https://www.amazon.com/gp/aw/d/B00CJG2ZYM?psc=1&ref=ppx_pop_mob_b_asin_title) (can make taking usb drive in and out easier)

# Tools for Construction
Here's a list of the tools you need to actually create a Mothbox. If you are building **multiple** mothboxes, you likely only need one of these tools no matter how many you make.

## Hand Tools
* Small Screwdriver Set with Interchangeable Heads
  * [Ifixit has a great one](https://www.amazon.com/iFixit-Minnow-Driver-Kit-Smartphones/dp/B08NWJH6TD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)
* Wire Strippers
* Flush Cutters
  * Great for trimming zip ties
  * [e.g.](https://www.amazon.com/Creativity-Cutter-Diagonal-Cutting-Nippers/dp/B087BL2KGM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)

## Cutting Tools
* 53mm hole saw bit [https://www.amazon.com/dp/B07R5RZNQK?psc=1&ref=ppx_yo2ov_dt_b_product_d53etails](https://www.amazon.com/dp/B07R5RZNQK?psc=1&ref=ppx_yo2ov_dt_b_product_details)
* Drill Bits for Plastic
  * Most of the holes drilled are 3/8 in (just over 1/4in) in size, but using something like a [tapered drill bit](https://www.amazon.com/Driak-16-30-5-Titanium-Umbrella-Chamfering/dp/B07RX7GRHG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) can be the easiest, as it goes through plastic well and allows you to adjust the sizes of your holes very finely.    

## Connecting Tools
* Zip ties
  * Extra thin, long zip ties work well!
* 1/4 in bolts and nuts
    * bolts
    * hex nuts
* M2 M2.5 and M3 Screws, Nuts, and Electronics Spacers
   * e.g [Nylon standoffs and nuts for Raspberry Pi](https://www.amazon.com/HVAZI-240pcs-Standoffs-Assortment-Male-Female/dp/B07JYSFMRY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)
   * [Set of m2 m2.5 m3 bolts and nuts](https://www.amazon.com/HVAZI-240pcs-Standoffs-Assortment-Male-Female/dp/B07JYSFMRY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)

* Glues
  * [Clear plastic epoxy works great](https://www.amazon.com/Gorilla-Epoxy-Minute-ounce-Syringe/dp/B001Z3C3AG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)
  * You can use hot glue if you cannot find epoxy.

## Electronics Tools
* Spools of Solid-Core Wire
  * [22 Gauge Solid Core works well](https://www.amazon.com/gp/product/B07JNB712X/ref=ppx_yo_dt_b_search_asin_title?ie=UTF8&th=1)
  * Spool of Red
  * Spool of Black
* Lever Nut Connectors 
   * [https://www.amazon.com/LEVER-NUTS-Compact-Splicing-Connector-Assortment/dp/B0957T1S9C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](https://www.amazon.com/LEVER-NUTS-Compact-Splicing-Connector-Assortment/dp/B0957T1S9C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)
   * [(or cheaper knock offs should work fine with low voltage like this)](https://www.amazon.com/Connectors-Delgada-Conductor-Connector-Electrical/dp/B09TS9YKV1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)

* [Dielectric grease (optional for additional waterproofing)](https://www.amazon.com/Mission-Automotive-Dielectric-Silicone-Waterproof/dp/B016E5E59G/)

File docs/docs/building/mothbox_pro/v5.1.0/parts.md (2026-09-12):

---
layout: default
title: Parts
parent: v5.1.0
grand_parent: Mothbox Pro
#has_children: true
nav_order: 0
---

{: .warning }
> # ⚠️ 5.1.0 documentation coming soon!
> These pages are copied from the **v5.0.3** instructions and have not yet been updated for the v5.1.0 hardware. Some parts and steps may differ. For a complete, tested guide, use the [v5.0.3 instructions](https://digital-naturalism-laboratories.github.io/Mothbox/docs/building/mothbox_pro/v5.0.3).

# Parts

To build a Mothbox Pro, you will need these parts (prices are estimates and fluctuate):
- [Download 3D Printed parts](https://github.com/Digital-Naturalism-Laboratories/Mothbox_Hardware/tree/main/Mothbox_Pro/)
- [Download Laser cut parts](https://github.com/Digital-Naturalism-Laboratories/Mothbox_Hardware/tree/main/Mothbox_Pro/Laser%20Cutting)

MB pro all parts 20260209_160744

## Electronics
This newest version of the Mothbox has easy to assemble electronics! You only need



* [Mothbox Mainboard](https://digital-naturalism-laboratories.github.io/Mothbox/docs/building/mothbox_pro/v5.1.0/manufacture/) - a Printed Circuit Board (PCB) with most electronics already connected up for you! - $50
* [Mothbeam Boards](https://digital-naturalism-laboratories.github.io/Mothbox/docs/building/mothbox_pro/v5.1.0/manufacture/) - Little, super bright, metal LEDs that plug in to your Mainboard (up to 3) - $5 each
* [Raspberry Pi 5 4GB](https://www.sparkfun.com/raspberry-pi-5-4gb.html) (or higher) - $75  (Our latest firmware LOOKS like it works with a [Pi 5 2GB](https://www.sparkfun.com/raspberry-pi-5-2gb.html), but we have not thoroughly tested)
* [SD Card](https://www.amazon.com/dp/B0CQX2B25W?ref=ppx_yo2ov_dt_b_fed_asin_title) - 32GB or bigger, Class A1 or faster (A2 is nice) - $15
* [USB Storage](https://www.amazon.com/dp/B0BN3Q1M96?ref=ppx_yo2ov_dt_b_fed_asin_title) - 32 GB or bigger
* [Pi 5 RTC Battery](https://www.sparkfun.com/raspberry-pi-rtc-battery.html) - $8
* [Talentcell PB120B1](https://www.walmart.com/ip/Millertech-PB120B1-12V-Lithium-ion-Talentcell-Battery-Pack/5119418367) - You can actually use any battery between 9-36 V to power the mothbox (it's more efficient around 12V), but for these tutorials we will use the main battery we use for all our devices, this one by Talentcell - $80
* [9-36V to 12V voltage Regulator](https://www.amazon.com/dp/B0B6VK8BPN?ref=ppx_yo2ov_dt_b_fed_asin_title) - $15
* [Arducam 64 MP Owlsight camera](https://www.amazon.com/dp/B0CQJPKFVF?ref=ppx_yo2ov_dt_b_fed_asin_title) - $55 (Don't get the "Hawkeye" older version of this camera if you can avoid it!)
* [Barrel Jack Sockets and Plugs](https://www.amazon.com/dp/B0D9B7WR23?ref=ppx_yo2ov_dt_b_fed_asin_title) (x2) - $2
* [Lever Nut](https://www.amazon.com/dp/B0CBP7WWML?ref_=ppx_hzsearch_conn_dt_b_fed_asin_title_1&th=1) - 2 wire connector - $0.40
* (Optional, but VERY USEFUL) [Epaper Display (Waveshare 2.13in E-ink hat)](https://www.amazon.com/dp/B0D22JJ18B?ref=ppx_yo2ov_dt_b_fed_asin_title) - $15



## Attractors

* [Mothbeams](https://github.com/Digital-Naturalism-Laboratories/Mothbox_Electronics/tree/main/Mothbeam_PCBs/AndyMothbeam_forMBv5.0.1) can plug right in to the PCB
* External - You can also connect any 12V attractor you want via the "External attractor" port

## Zip Ties
  * [7 really thin ones](https://www.amazon.com/dp/B07W98YW6J?ref=ppx_yo2ov_dt_b_fed_asin_title)
  * 8 typical width
  * 2 really big

## 3D printed parts
[Download 3D Printed parts](https://github.com/Digital-Naturalism-Laboratories/Mothbox_Hardware/tree/main/Mothbox_Pro/)
We used [PETG-Carbon Fiber](https://www.amazon.com/dp/B0FC6H71B1?ref=ppx_yo2ov_dt_b_fed_asin_title) (regular [PETG](https://www.amazon.com/dp/B0FC6H7FBL?ref=ppx_yo2ov_dt_b_fed_asin_title) will also be fine) and [TPU Filaments](https://www.amazon.com/dp/B0B6FMVJ2H?ref=ppx_yo2ov_dt_b_fed_asin_title&th=1)


  
  * Inner Chassis
  * Outer Shell
  * Camera Glare Blocker
  * Front Lid
  * Back Lid

For really wet places
  * TPU Gasket - Front
  * TPU Gasket - Back

## Laser Cut Parts
[Download Laser cut parts](https://github.com/Digital-Naturalism-Laboratories/Mothbox_Hardware/tree/main/Mothbox_Pro/Laser%20Cutting)

  * Front Acrylic Window
  * Arms
  * Target
  * (Includes alternative files for if you want to laser cut your front and bask gaskets with [laser cutting rubber](https://www.amazon.com/dp/B08Q7CTSJL?ref_=ppx_hzsearch_conn_dt_b_fed_asin_title_12) instead of printing in TPU)

## Connectors
To hold the lid on and the legs on you have 3 options:
* Re-usable zip ties
* Rubbery Silicone Ties
* 3D printable TPU ties

## Screws
* #6 x 3/8" screws (or 6g x 9mm)

# Tools
Here's some tools you need:

* Screwdriver
* Wire Strippers
* Hot Glue Gun

Bonus tools could also be useful:
* Flat Snips (Scissors could maybe work too)

**Total Estimate: $350**

# Bonus Parts
You can also add:
* [Cheap Epaper display](https://www.waveshare.com/2.13inch-e-Paper-HAT.htm) - ($15USD) to know what your Mothbox is up to!
* External temperature sensor - Connects to a port on the PCB
* Cheap GPS - gives super accurate timestamps and can automatically locate your mothbox - plugs in to ports on PCB - [5 pin](https://www.amazon.com/dp/B0B31NRSD2?ref_=ppx_hzsearch_conn_dt_b_fed_asin_title_1) or [4 pin](https://www.amazon.com/dp/B0CWL774NR?ref_=ppx_hzsearch_conn_dt_b_fed_asin_title_1)

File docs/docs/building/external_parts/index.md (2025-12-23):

---
layout: default
title: External Parts
nav_order: 2
has_children: true
parent: Building
permalink: /docs/building/external_parts
---

# External Parts
Your Mothbox needs to be safe from the environment and travelling while keeping the internal electronics happy and taking crisp photos. This section will tell you how you can build your own external parts (or source them!)

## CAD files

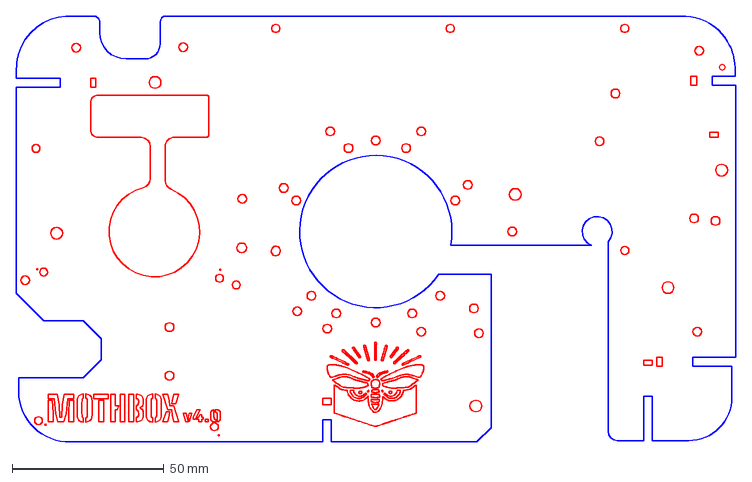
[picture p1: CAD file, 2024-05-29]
Hardware/Laser Cutting Layouts/v4/Inside Harness - MothboxMainboard.dxf
237.0 x 140.4 mm

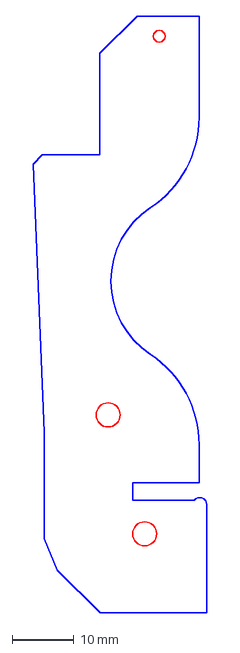
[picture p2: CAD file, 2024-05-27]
Hardware/Laser Cutting Layouts/v4/Inside Harness - VerticalClips x4.dxf
28.2 x 96.8 mm

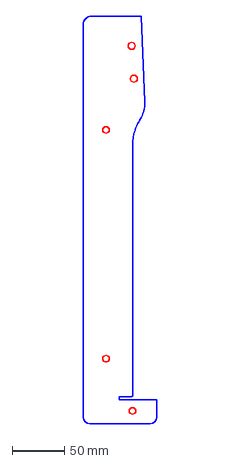
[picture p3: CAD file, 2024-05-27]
Hardware/Laser Cutting Layouts/v4/Arms - Arm Direct Attach.dxf
70.1 x 388.4 mm

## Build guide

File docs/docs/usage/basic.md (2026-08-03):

---
layout: default
title: Usage Guide (DIY)
parent: Using Mothbox
has_children: true
nav_order: 3
---

{: .warning }
> Test your tools BEFORE taking them to the field! Learn how to use, configure, and test your devices BEFORE you travel somewhere more remote! Especially for first time users, there are certain ways of customizing and setting up your device that you may not have much experience in. Test at home!

# Quick Use Checklist

**Preparation**

- [ ] Charge MOTHBOX 
  - Make sure it is plugged in with the battery on 
  - Make sure you are charging with the official charger 
  - Make sure the charger's light has turned from red to green  (this is the only real way that you know the battery is fully charged) 

- [ ] Check that you have a USB drive connected to the Raspberry pi. 
- [ ] Check you have all parts ready for deployment
  - 1 Mothbox
  - 4 Bolts and Nuts
  - Strap
  - 4 Legs
  - 1 Target

---------------------------------------
**In the Field**

- [ ] Arm the moth box, Check STANDBY Mode 
  - make sure inhibition cables are disconnected 
  - turn the battery on
  - if the moth box is correctly in "STANDBY" mode, The attractor lights will blink twice quickly.  And the screen will display "STANDBY" when it refreshes about 10 seconds later

- [ ] Close Mothbox 

- [ ] Attach legs to bottom 

- [ ] Hang mothbox with strap

- [ ] Remove lens cap

- [ ] Visual Inspection
  - lens area in front of camera for dirt 
  - Inspect area in front of target that no leaves will block target view

- [ ] Finally, connect target to arms

- [ ] Log all metadata on field sheet 

---------------------------------------
**Data collection**

- [ ] Collect mothbox from the field 

- [ ] Unplug USB drive from raspberry pi

- [ ] Copy contents of USB to computer and backup data in at least 2 spots

- [ ] Clear data from USB 

- [ ] Connect usb back to mothbox

- [ ] Charge mothbox for next deployment 

# Charge the Battery before 1st use!
{: .warning }
>When you purchase the batteries, they are often not fully charged! This can be a problem because several people have connected their pi's to a barely charged battery and the low-power causes them to "brown out" and have eeprom errors (where you then have to use the raspberry pi imager to reset the bootloader to get your pi working!)

Save yourself a headache, and charge your battery before you connect it the first time!

# Metadata Sheet
Your data isn't useful unless you know where it came from! Always log your metadata with a field sheet.

You can [fill out a form online](https://docs.google.com/forms/d/e/1FAIpQLSdtyvTUa9q-wIMjUjjW5S2-CFNQKzcaZLGq95XJG2XJVAWLLg/viewform?usp=header) or print a [sheet to take to the field](https://drive.google.com/file/d/1Qup4S7lnafGi4H0VY2vz-h7c9UYbge10/view?usp=drive_link).

You can even use a [pre-filled form for use in Panama](https://docs.google.com/forms/d/e/1FAIpQLSdtyvTUa9q-wIMjUjjW5S2-CFNQKzcaZLGq95XJG2XJVAWLLg/viewform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)

# Inventory of Mothboxes
If you are running a project with many Mothboxes (more than about 4), you probably want to start keeping an inventory. Field equipment can get lost, forgotten, or busted up, so it's handy to know what you have available if a new opportunity strikes!
Here's an [example of how we organize our inventory of mothboxes](https://docs.google.com/spreadsheets/d/1W60RJSNnirpbALVyalLmYodYBUhqQkD_vb8ZOFOarns/edit?usp=sharing). (If you have suggestions for better organizational schema, please let us know!)

## Mothbox Name
The Mothboxes all have a unique, persistant name (based on the Pi's serial number). The names are in the format of (descriptiveword+animal) and are made from the thousand most common descriptive words and animals in both English and Spanish.

This is why you will have names like "CoolJirafa" or "PrizeCrab."
The name should be written on a sticker on the Mothbox. Like "FondoGorila."
PXL_20240909_045245636 MP
Updated mothboxes will also show the name prominently on the epaper display!

# Portable Field Guide

The steps below show you what to do to make sure your Mothbox will run in the field. This is also available as a small print-out that fits inside the Mothbox. We print and laminate them and include them with each Mothbox to make sure everyone knows how to use it. This field guide is available in English and Spanish (and hopefully even more languages soon!).

* [English Field Guide (Printable)](https://github.com/Digital-Naturalism-Laboratories/Mothbox/tree/main/docs/Quick%20Reference%20Guide)
* [Guia de Campo en Español (para imprimir)](https://github.com/Digital-Naturalism-Laboratories/Mothbox/tree/main/docs/Quick%20Reference%20Guide)

Mothbox_Quick_ReferenceGuide_v3BigText_ESP



# Preparation
Before you go to the field, here's a checklist to make sure it is ready for deployment!

- [ ] The battery should always be ON. The switch to the battery should ALWAYS BE IN THE ON POSITION. Open the Mothbox make sure the battery switch is ON (if it's not already on). 



- [ ] Charge your Mothbox. This usually takes several hours. Plug it in. Only use the Mothbox charger to charge. You may have other chargers that look similar for other devices, but they are not interchangeable and will not charge the Mothbox correctly. 


Mothbox_Quick_ReferenceGuide_v3BigText_English

If the plug's indicator is red, the Mothbox is charging. When charger light turns green, the Mothbox is fully charged!


Mothbox_Quick_ReferenceGuide_v3BigText_ESP

- [ ] USB Storage. Make sure there is external storage with free space plugged in to the Pi's USB to record your photos.


      
- [ ]  Arm Mothbox. The Mothbox has two jumper wires that keep it from turning itself on until it is deployed. Arm your Mothbox by disconnecting the wires from each other, putting them in the "armed" position.

PXL_20240909_044023484 MP

- [ ] Check Lights. The RED STANDYBY LEDs should always be on. The Mothbox is set to run automatically according to a schedule, so it probably won't be running when you are setting it up. However, you can visually check that things are ok, because there should be a RED LED light on the Pi (the Pi's off light), and the battery's GREEN lights should always be on. Older models with a Pijuice may also have a BLUE light on as well in standby mode.



- [ ] Add Silica. Add packet of silica drying gel inside box.



PXL_20240902_191451479 MP

- [ ] Close Box. Make sure box is fully closed with all three clips and no wires are caught in the door.

PXL_20240901_112119774 NIGHT

- [X] Item Checklist. Make sure to have all these parts with you **BEFORE you go into the field.**
  - [ ] Mothbox
  - [ ] USB Storage
  - [ ] 4 Arms
  - [ ] 4 Bolts
  - [ ] 4 Nuts
  - [ ] Target
  - [ ] Strap
  - [ ] Security chain and lock (if deploying in places where theft may be an issue)

# Deploy

- [ ] Attach arms to bottom of case with 1/4" screws and nuts. Place target on the end of arms. Ideally, the screws go from the middle of the box out toward the outside edge of the box so that they don't block anything.

PXL_20240902_193651155 MP

- [ ] Hang Mothbox. Using the handle, strap Mothbox to a tree or tripod. Make sure there are no obstacles (like leaves or tall grasses) that may blow between the box and the target and obstruct photos. In general, the Mothbox should be at least 0.5 meters above the ground.

PXL_20240902_191549638 MP

Adding a little wrap of the strap around the handle (The Margaret Technique) adds stability to the Mothbox.

PXL_20240902_155747765 MP

- [ ] Inspect Lens. Check lens for dirt and clean with a lens wipe if necessary. **Make sure lens cap is off.**
  


- [ ] Connect Target. Attaching the target should be one of the last things you do, because you want to protect it from getting dirty. If you have it connected earlier, it could easily bump into wet or dirty plants and get muddy.

PXL_20240902_194008047 MP

PXL_20240902_191925903 MP

- [ ] Log Data. Write down all the metadata about this deployment on your [field sheet](https://docs.google.com/forms/d/e/1FAIpQLSeVtBKB8oCWIPIFcEjxCgvnIAEBkRQts0hqxMX58y2VXKmb4A/viewform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).



{: .warning }
> warning: Don't look directly at UV light. UV light is very bright but invisible to your eye. Eye pain or headaches can occur with long exposure. Use eye protection if working with Mothbox for extended periods while it's on.

{: .note }
> Default schedule: Mothbox will take photos from 19:00-20:00, 22:00-23:00, 1:00-2:00, and 4:00-5:00. If you want it to take photos at different times, change the settings.

# Collect
- [ ] Collect the Mothbox. Make note of any damage, such as water inside case, dirt on target, or physical injury.
- [ ] Disarm the Mothbox with disarming wires (jump wires).
- [ ] Disconnect external storage from the USB port and check out all your cool photos!
- [ ] Backup and organize all the photos from the external storage, and then clean this storage device, deleting all the old folders so it is ready for the next deployment.
- [ ] Charge for the next deployment.

# Manually Turning the Mothbox On and Off
The Mothbox has an internal schedule that lets it stay in a low-power state until it is ready to turn itself on. Sometimes you may wish to **manually trigger** the Mothbox to start running a photo session. Or you may wish to manually turn off a mothbox that has started running.

## Turn It On
You can turn the Mothbox ON by just pressing the "On" button located next to the LED on the Raspberry Pi. Just tap it once, and it will start up.



## Turn It Off
You can turn the Mothbox OFF by pressing **and holding** the "On" button for 10 seconds. Just press the button and hold it until the mothbox has shut off.



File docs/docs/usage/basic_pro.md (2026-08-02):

---
layout: default
title: Usage Guide (Pro) 
parent: Using Mothbox
has_children: true
nav_order: 2
---

{: .warning }
> Test your tools BEFORE taking them to the field! Learn how to use, configure, and test your devices BEFORE you travel somewhere more remote! Especially for first time users, there are certain ways of customizing and setting up your device that you may not have much experience in. Test at home!

# Quick Use Checklist
-----------------------------------------------------
**Preparation**

- [ ] Charge MOTHBOX 
  - Make sure it is plugged in
  - Make sure **battery switch is ON** 
  - Charge only with **the official charger** 
  - When light on charger has turned from red to **green**, the battery is fully charged. (this is the only real way that you know the battery is fully charged) 
- [ ] Check that you have a USB drive plugged in to the Raspberry Pi.
- [X] Item Checklist. Make sure to have all these parts with you **BEFORE you go into the field.**
  - [ ] Mothbox
  - [ ] Target
  - [ ] 4 Arms
  - [ ] 4 leg connectors (Zips or Bolts+Nuts)
  - [ ] Strap
  - [ ] Security chain and lock (if deploying in places where theft may be an issue)

---------------------------------------
**In the Field**

- [ ] Activate Mothbox / Check STANDBY Mode 
  - Make sure **"ACTIVE"** switch is **ON**
  - turn the battery on
  - If the Mothbox is ready for deploment, the attractor lights will blink twice rapidly, and the display will show "STANDBY" mode.
  - In STANDBY mode, the Mothbox will activate itself during its next scheduled session (no further action is required by you to turn itself on).

- [ ] Close Mothbox 

- [ ] Attach legs to bottom 

- [ ] Hang Mothbox with strap

- [ ] Remove Front Lid

- [ ] Visual Inspection
  - Check area in front of camera for dirt 
  - Inspect area in front of target so that no leaves will block camera's view of target

- [ ] Finally, connect target to arms

- [ ] Log all **metadata** on [field sheet](https://digital-naturalism-laboratories.github.io/Mothbox/docs/usage/basic_pro/#metadata-sheet) 

---------------------------------------
**Data collection**

- [ ] Collect Mothbox from the field 

- [ ] Unplug USB drive from Raspberry Pi

- [ ] Copy contents of USB to computer and backup data in at least 2 spots

- [ ] Clear data from USB 

- [ ] Connect USB back to Mothbox

- [ ] Charge Mothbox for next deployment 

------------------------------------------------------------------------

# Detailed Instructions

## Charge the Battery before 1st use!

{: .warning }
> warning:  When you purchase the batteries, they are often not fully charged! This can be a problem because several people have connected their pi's to a barely charged battery and the low-power causes them to "brown out" and have eeprom errors (where you then have to use the raspberry pi imager to reset the bootloader to get your pi working!)

Save yourself a headache, and charge your battery before you connect it the first time!

## Preparation
Here's what you need to do to make sure your Mothbox is ready for deployment!

- Make sure the **battery is ON**. The switch to the battery should ALWAYS BE IN THE ON POSITION. Open the Mothbox make sure the battery switch is ON (if it's not already on). 



- Charge your Mothbox. This usually takes several hours. Plug it in. Only use the Mothbox charger to charge. You may have other chargers that look similar for other devices, but they are not interchangeable and will not charge the Mothbox correctly. 



If the plug's indicator is red, the Mothbox is charging. When charger light turns green, the Mothbox is fully charged!



- [ ]  (Optional) De-Activate Mothbox. Sometimes if you are charging the devices overnight (or during times they are scheduled to take photos), it can be useful to disable the Mothbox from running. There is a switch labeled "Active" which can keep the Mothbox in an OFF mode if it is switched off. You can switch this to the OFF position while it is charging.



- [ ] USB Storage. Make sure there is external storage with free space plugged in to the Pi's USB to record your photos.



- [X] Item Checklist. Make sure to have all these parts with you **BEFORE you go into the field.**
  - [ ] Mothbox
  - [ ] Target
  - [ ] 4 Arms
  - [ ] 4 leg connectors (Zips or Bolts+Nuts)
  - [ ] Strap
  - [ ] Security chain and lock (if deploying in places where theft may be an issue)



- [ ] Pack Mothbox for travel to the field. 
  - [ ] (Optional) If you are travelling far, you can turn the battery switch OFF.


  - [ ] Connect Lids. Attach the front and back lids to protect it during travel.




## Video Deployment Tutorial

<iframe width="560" height="315" src="https://www.youtube.com/embed/4CIvh947Z08?si=dJNL0WZCyLDUA3Sx" title="YouTube video player" frameborder="0" allow="accelerometer; autoplay; clipboard-write; encrypted-media; gyroscope; picture-in-picture; web-share" referrerpolicy="strict-origin-when-cross-origin" allowfullscreen></iframe>

## Deployment in the Field



- [ ] Check device is ready to Activate.
  - [ ]  Make sure the "Active" switch is in the ON position.



  - [ ]  You can turn the battery power off and then on again, and the mothbox should boot up
  - If the Mothbox is ready for deploment, the attractor lights will blink twice rapidly, and the display will show "STANDBY" mode.

 

  - In STANDBY mode, the Mothbox will activate itself during its next scheduled session (no further action is required by you to turn itself on).

- [ ] Close Box. Make sure box is fully closed at all four corners.



- [ ] Attach arms. You can connect arms to the bottom of the case using several options
  - [ ] 1/4" bolts and nuts
  - [ ] re-usable zip ties
  - [ ] or Rubber ties
  


- [ ] Hang Mothbox. Using the handle, strap Mothbox to a tree or tripod.



  - [ ] Make sure there are no obstacles (like leaves or tall grasses) that may blow between the box and the target and obstruct photos.


  
  - [ ] In general, the Mothbox should be at least 0.5 meters above the ground.

- [ ] Remove Front Lid.



- [ ] Inspect Camera area. Check lens for dirt and clean with a lens wipe if necessary.



- [ ] Connect Target. Attaching the target should be one of the last things you do, because you want to protect it from getting dirty. If you have it connected earlier, it could easily bump into wet or dirty plants and get muddy.



- [ ] Log Data. Write down all the metadata about this deployment on your [field sheet](https://docs.google.com/forms/d/e/1FAIpQLSeVtBKB8oCWIPIFcEjxCgvnIAEBkRQts0hqxMX58y2VXKmb4A/viewform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).



{: .warning }
> warning: Don't look directly at UV light. UV light is very bright but invisible to your eye. Eye pain or headaches can occur with long exposure. Use eye protection if working with Mothbox for extended periods while it's on.

{: .note }
> Default schedule: Mothbox will take photos from 19:00-20:00, 22:00-23:00, 1:00-2:00, and 4:00-5:00. If you want it to take photos at different times, change the settings.

# Collecting the Mothbox and Data
- [ ] Collect the Mothbox. Make note of any damage, such as water inside case, dirt on target, or physical injury.
- [ ] Disarm the Mothbox with disarming wires (jump wires).
- [ ] Disconnect external storage from the USB port and check out all your cool photos!
- [ ] Backup and organize all the photos from the external storage, and then clean this storage device, deleting all the old folders so it is ready for the next deployment.
- [ ] Charge for the next deployment.

## Process Data
You might want to process the data you collected from your Mothbox. Go to the next section, [Refining Data](https://digital-naturalism-laboratories.github.io/Mothbox/docs/processing) to turn all your photos into organized data.

# Additional Information

## Metadata Sheet
Your data isn't useful unless you know where it came from! Always log your metadata with a field sheet.

You can [fill out a form online](https://docs.google.com/forms/d/e/1FAIpQLSdtyvTUa9q-wIMjUjjW5S2-CFNQKzcaZLGq95XJG2XJVAWLLg/viewform?usp=header) or print a [sheet to take to the field](https://drive.google.com/file/d/1Qup4S7lnafGi4H0VY2vz-h7c9UYbge10/view?usp=drive_link).

You can even use a [pre-filled form for use in Panama](https://docs.google.com/forms/d/e/1FAIpQLSdtyvTUa9q-wIMjUjjW5S2-CFNQKzcaZLGq95XJG2XJVAWLLg/viewform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)

## Inventory of Mothboxes
If you are running a project with many Mothboxes (more than about 4), you probably want to start keeping an inventory. Field equipment can get lost, forgotten, or busted up, so it's handy to know what you have available if a new opportunity strikes!
Here's an [example of how we organize our inventory of mothboxes](https://docs.google.com/spreadsheets/d/1W60RJSNnirpbALVyalLmYodYBUhqQkD_vb8ZOFOarns/edit?usp=sharing). (If you have suggestions for better organizational schema, please let us know!)

## Manually Turning the Mothbox On and Off
There are a couple different power states that the Mothbox can be in:

- Battery Off: When the battery is off, everything is off
- Battery On / Raspberry Pi Off: When the raspberry pi has a RED light on it, it means it is in low-power mode and not on
- Battery on / Raspberry Pi On: When the pi has a GREEN light, it means it is on (and either probably in Debug mode or Active mode)

The Mothbox has an internal schedule that lets it stay in a low-power state until it is ready to turn itself on. Sometimes you may wish to **manually trigger** the Mothbox to wake up, you can do this just by clicking the little white button next to the SD card on the Raspberry Pi. Just tap it once, and it will start up.



If you want to gently turn it back off with your finger, you can do this by pressing **and holding** the white button for 10 seconds. Just press the button and hold it until the mothbox has shut off and the light on the Raspberry pi has gone from GREEN to RED.



## Mothbox Name
The Mothboxes all have a unique, persistent name (based on the Pi's serial number). The names are in the format of (descriptiveword+animal) and are made from the thousand most common descriptive words and animals in both English and Spanish.

This is why you will have names like "DotingBruja" or "PrizeCrab." This unique name will be applied to all the photos it takes to give them a unqiue stamp.

Updated mothboxes will also show the name prominently on the epaper display!



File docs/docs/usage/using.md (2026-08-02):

---
layout: default
title: Using Mothbox
nav_order: 3
has_children: true
permalink: /docs/usage
---

# Using the Mothbox

This will contain pages detailing how to use the mothbox.

{: .warning }
> Test your tools BEFORE taking them to the field! Learn how to use, configure, and test your devices BEFORE you travel somewhere more remote! Especially for first time users, there are certain ways of customizing and setting up your device that you may not have much experience in. Please, test at home!

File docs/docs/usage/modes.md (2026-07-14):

---
layout: default
title: Modes
parent: Using Mothbox
has_children: true
nav_order: 4
---

# Mothbox Modes

There are several possible modes that a Mothbox can be in:

## MOTHBOX PRO MODES

For the **Mothbox Pro,** you can set the Modes just by flipping the Switches!


(Hourly and Daily SwitchesO - For setting the schedule in "Switches" mode

This is organized into a clear, professional markdown table format that uses appropriate headings and formatting for easy reading.

***

### Device Controls & Modes Reference

| Button ID | Primary Function | Description |
| :--- | :--- | :--- |
| **U1** | **Switch Mode Toggle** | When enabled, the scheduling system overrides the internal schedule defined in `mothbox_settings.csv` and uses the sequence determined by the physical switches. |
| **C1** | **Diagnostic / Party Mode** | Toggles a special diagnostic or "Party" mode. |
| **A1, A2, A3, EXT** | **Free Switches** | Customizable outputs. These are independent toggles in the firmware not currently connected to any fixed function and can be assigned custom actions via programming. |
| **HI** | **Hi Power Mode Placeholder** | Reserved for the upcoming "Hi Power Mode" when the Mothbox is equipped with constant power and stable data connectivity. |
| **DEBUG** | **Debug Mode Activator** | Activates an extended "Debug" state, specifically keeping the Wi-Fi connection active and disabling all normal automated routines to allow for manual troubleshooting. |

***

## Description of Modes
* Active: it is currently running a session. It turns on the attractor lights and takes photos at the designated interval. (Pro - switch "Active" is on)
* Standby: the mothbox's pi is shut down, but during the next scheduled wake session it will become active. The device will flash its lights twice before going into a low power shutdown mode. (Pro - switch "Active" is on, but the schedule says its not time to run yet)
* Off: The Mothbox will never turn on (Useful for charging or storage) (Pro - switch "Active" - Off)
* Debug: When the mothbox has power, it will wake up and not shut down until manually turned off. Automatic Cron routines will not run. Lights are default off. Wifi stays on. (Pro - switch "Active" AND "Debug" are on)

The Following Modes are only available right now for the Mothbox Pro
* Party: Like debug mode, but it runs a routine to just cycle all the lights (Pro - switch "C1" and "ACTIVE" are on)
* HI Power*: like ACTIVE but Assumption is connected not to battery, but unlimited power supply. Wifi stays on, attempts to upload photos to internet servers automatically. (Pro - switch "Hi" ) *Not implemented yet in the firmware

## MOTHBOX DIY MODES
For the **Mothbox DIY**, your options are a bit more limited, but you can set what Mode your device is in by using Jumper wires on some select pins:

Basically connect one wire to GND.

**OFF**
Then if you connect the pin labelled **P27 to the GND wire**, your mothbox will stay off!

**DEBUG**
or if you want to do some deeper hacking on your mothbox, you can set it in Debug mode by connecting **P26 to GND**

**Active and Standby**
Just don't connect any wires to GND!



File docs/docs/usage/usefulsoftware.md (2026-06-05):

---
layout: default
title: Useful Software
parent: Using Mothbox
has_children: true
nav_order: 8
---
This is a list of useful software to download for working with the Mothbox.

# Programming the Pi

* [Raspberry Pi Imager](https://www.raspberrypi.com/software/)

* [Win32 Disk Imager](https://win32diskimager.org/)

* [SD Card Formatter](https://www.sdcard.org/downloads/formatter/sd-memory-card-formatter-for-windows-download/)

# Access files on a Linux Formatted SD card (Like on your raspberry pi)

The raspberry pi's sd card has 2 partitions. 1 kinda normal partition you can read on a Mac or PC that you can adjust settings on, but there is also one extra SECRET partition that you need special software to see on a mac or PC. This is where the backup images are stored!

[For PC](https://www.paragon-software.com/home/linuxfs-windows/) (just use the free version)

[For Mac](https://github.com/fenio/anylinuxfs-gui)

# Pi Debugging Software

You may have noticed that even though the Raspberry Pi is a computer, it doesn't have a mouse or screen. But that's ok! There's special ways you can see what's going on with your Raspberry Pi by using special software called a "VNC" software.
Download this, and we will be able to look at what's going on inside your computer in a virtual way!

* [Tiger VNC ](https://sourceforge.net/projects/tigervnc/files/stable/1.15.0/)
* [RVNC Android App](https://play.google.com/store/apps/details?id=com.realvnc.viewer.android&hl=en&pli=1)
* [RVNC Apple App](https://apps.apple.com/us/app/realvnc-viewer-remote-desktop/id352019548)

# Default Keys

user: pi
pazz: luna

self-hosted wifi
SSID: mothboxwifi
pazz: lunaluna

external wifi: 
SSID: DINALAB
pazz: iloveyardpigs

# Latest Mothbox Software Images
* [Mothbox Pi Images](https://drive.google.com/drive/u/0/folders/1o3aGB1MZUrNxRoGycFVw_ofUQehrjuqF)

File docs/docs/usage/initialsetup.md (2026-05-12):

---
layout: default
title: Configure Settings
parent: Using Mothbox
has_children: true
nav_order: 0
---

You already have a mothbox built, but now you need to give it life! There is special software that lives on the computer inside your mothbox to make it run. It controls things like the timezone, photo taking schedule, and power usage. This software is called "Firmware."

This used to be a complicated task and we had an [entire webpage dedicated to explaining how to get special software to log in to your mothbox, and change the configuration](https://digital-naturalism-laboratories.github.io/Mothbox4.5/docs/usage/configure/), but now since firmware DIY_4.16.5 and Pro_5.1.0, we were able to make the process MUCH EASIER!

You will just need to 

* Flash the Firmware onto an SD Card
* Customize some files on the SD Card

# Flash Firmware

## Flash the Raspberry Pi Image onto an SD Card

### Get the Image
Download the [latest Mothbox Image](https://drive.google.com/drive/folders/1o3aGB1MZUrNxRoGycFVw_ofUQehrjuqF?usp=drive_link) to your computer. You may need an [unzipping software like 7zip](https://7-zip.org/download.html) to unzip the image after you download it.

Make sure to choose firmware from either the Pro or DIY version based on what type of mothbox you have!


### Get the Imager
Download Image Flashing Software. You can use the traditional 
* [Raspberry Pi Imager](https://www.raspberrypi.com/software/),
* or I often use [Win32DiskImager](https://win32diskimager.org/).

Get an SD card (at least 16GB). Connect it to your computer.

## Start the Imaging software. 


If you are using Raspberry Pi Imager, click "Choose OS." Then scroll all the way down to choose "Use Custom."
Click "Choose Storage" and choose the SD card you have connected.
Click "Next."

If it asks you to apply customization options, just click no. 

Now it will start flashing your SD card. This should take about 5-10 mins.

PXL_20240909_004008143 MP

Hooray! You have an SD card with the brains of a Mothbox on it! Next we will configure it!

# Flashing a Special Bootloader SD Card

{: .important-title }
> Reset Your Pi's Bootloader
>
> A common problem with a new Mothbox is that it won't start with a fresh SD card. Some Raspberry Pi's have a strange bootloader installed at the factory. You can reset it easily and fix most problems by flashing a bootloader on your SD card!

Recently when we have been ordering Raspberry Pi's about half the ones we have received from the factories seemed to have arrived without their bootloaders installed (a bootloader is special tiny software on the raspberry pi that tells the device it is in a fact a Raspberry Pi 5). This may create problems when you first use the Pi like it won't turn on with a new SD card, and instead will flash a series of repeating patterns on its LED.

The solution to this problem is simple! You just need to install the proper bootloader on your Raspberry Pi. Instead of choosing "custom img" in your Pi Imager, you just choose "Misc Utility Images > Bootloader > SD card boot" and flash that to an SD card.







Put that SD card into your Pi. Wait 20 seconds until the LED on your Pi starts flashing green quickly. Turn your pi off. Insert the Mothbox SD card, and voila, your device should run great!

{: .important-title }
> Remember to Switch to ACTIVE mode!
>
> Rememeber to switch your Mothbox to ACTIVE mode if you want to see it blink at you and check it is working properly (or else it will turn itself on, and turn off quickly)

# Configure Mothbox

Unless you are using your Mothbox in Panama, you probably need to configure a couple things before you use it! 

The main thing you want to do is make sure the timezone and time is correct!

## Put (Or Keep) the SD Card in Your Computer
The way we configure the Mothbox settings is now by modifying files on the Raspberry Pi SD Card. Put it in your computer and make sure it shows up as "bootfs".



Go into "bootfs" and then into the folder called "mothbox_custom"



You will find 3 files there that can let you customize everything!

## Mothbox Settings
Open the file **"mothbox_settings.csv"** with a text editor


This settings file is a "CSV" or "comma separated value" file, meaning that data is organized in different lines, and each line is structured like

> SETTING,VALUE,DETAILS

so the 
* first value before a comma shows what type of setting you are changing (e.g. timezone)
* second value is the value of that setting (e.g. America/Bogota)
* third value is simply a description of this setting (e.g. "put a linux timezone here")

### Change the Timezone
The first thing you will want to do is set the timezone. You need to copy and paste a timezone from the official list of Linux timezones. 



The file of all the possible timezones is included, so you can browse for what timezone works for you!
Just paste the timezone you need into the VALUE section



### Set the Time
{: .important-title }
> Using Internet Time
>
> If your mothbox is connected to the internet, and you already changed the timezone, it SHOULD automatically set the correct time for you!
> You can use a phone set up for WIFI tethering with
> SSID: DINALAB
> wifipass: iloveyardpigs

There are two ways to set the time for your mothbox:

* Manual Time: change it once in settings
* Automatic (internet) time: Connect it to the internet
 
Using automatic time from the internet is recommended and easy.

#### Set Time Manually
**If you have no access to the internet**, you can also change the time manually! It's also quite easy!



you need to change the "autoSystemTime" setting to "False," and then set the time you want for your mothbox after the "manualTime" setting.

Your mothbox will read this time, and set that as the system time. 

{: .important }
> Connecting to the Internet (Coming Soon!)
>
> You might notice in the "mothbox_settings.csv" that there are settings for a wifi SSID and password! They currently don't do anything! They are just placeholders for us implementing a way to easily connect to whatever wifi you want. Meanwhile, if the mothbox cannot find an internet it knows, it will create a [hotspot](https://www.raspberryconnect.com/projects/65-raspberrypi-hotspot-accesspoints/203-automated-switching-accesspoint-wifi-network) called "mothboxwifi" with the password:"lunaluna"

#### Set Internet time

First, **make sure your device is in DEBUG MODE.** If it is in an Active or Standby mode, it will turn off its wifi to save power! 

Create a hotspot with your phone with the following username
> SSID: DINALAB
> wifipass: iloveyardpigs

(the password is a name for our beloved agoutis outside)
The mothbox will hop on this wifi automatically when it starts up and set the time automatically for you!

### Set Custom Mothbox Name (Optional)
This is a very optional thing to do. The mothbox, by default will create a random unqiue name for your device.



If, for some reason, you really want your mothbox to have a specific name (that might run the risk of having a similar name as another one). You can just set the autoName to "False"
and then it will change your mothbox's name to whatever you include after the "name" setting.

## Change Camera Settings (Optional)
Most people will never change these settings.

By default, the cameras in the mothbox are set to:
* Automatically calibrate focus every 10 minutes
* Automatically calibrate exposure every 10 minutes
* Optimize the image for the largest resolution and fastest "shutter speed" (to reduce moving insect blur)

Maybe you want your mothbox camera to do something else? I have just the file you can mess around with!

Most people will never ever touch this file, but if you want to change stuff, **open the file called "camera_settings.csv"**



There you can change some settings about how the mothbox takes photos.
Some of the main ones folks might want to mess with are:

AutoCalibration - can make it fully manual (not really reccomended, things like focus can drop off with slight shifts)
AutoCalibrationPeriod - can change how long the camera waits before recalibrating all its settings. Default is 10 minutes, but you can make it more or less.
VerticalFlip - This is important if you are building your mothbox a little differently and need to install the camera upside down.

# Insert SD Card into Pi
When you have completed your configuration, it's time to put it in the Pi!
Find the SD card into the bottom of your Pi and push it all the way in.
PXL_20240909_000146089 MP

# Set the Configuration for a LOT of mothboxes
Maybe you have 20 or 50 mothboxes you want to configure to be the same timezone. Well that's easy to do, just follow this guide 50 times with each mothbox. (lol)

An even easier approach though is that you can CLONE the SD card of your current mothbox once you have. 

* After you have made all the changes you want, shut down the Mothbox.
* Pull out its SD card
* Follow [this guide to clone this SD card to other SD cards and put them in the other Mothboxes](https://quitmeyer.github.io/Mothboxv4.0/docs/programming/clone/)

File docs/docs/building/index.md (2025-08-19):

---
layout: default
title: Building Mothbox
nav_order: 2
has_children: true
permalink: /docs/building
---

# Assembly
This guide will show you how to construct a mothbox from scratch!

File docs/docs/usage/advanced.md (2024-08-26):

---
layout: default
title: Advanced Use
parent: Using Mothbox
nav_order: 6
---

# Changing Settings (via USB)
The Mothbox is made to be user friendly, and allow people without advanced programming skills quickly change settings like the **schedule** and **photography**  by just changing simple text files on a USB stick.

## Changing the Schedule

## Changing Photography Settings (HDR mode, Exposure Time)

# Connecting to a Mothbox remotely
The Mothbox is set up so that you can log-in and control it using any other computer. It has a script running that will let the Mothbox create its own wifi network called "Mothbox" if it doesn't detect any known wireless networks. You can connect to this network and then use VNC software to log in and view/control everything the Mothbox does!

TODO: show basic remote login instructions

## Debug Mode
TODO: show how to run DEBUG

# Troubleshooting

## One of the lights is not working
Chances are a wire has come loose somewhere. Refer to the wiring instructions, and try to undo and reconnect the wires.

# Tips for Working with Completely Fresh Raspberry Pi Images (starting from Scratch)
## Editing a Mothbox with another Raspberry Pi

Here's how to load a completely fresh version of raspberry pi OS onto a device

# Flashing the SD card
Open Raspberry Pi Imager

Choose: Raspberry Pi OS 32 Bit

choose your SD card

Then press the little settings icon and make the following settings

hostname: mothboxstation
username: pi
password: gimmemoths  (or whatever you want)

make sure to click "Enable SSH"

under CONFIGURE WIRELESS LAN
for SSID put the exact name of your wifi
and enter the password next

hit save

next hit WRITE


and the image will start loading onto your pi

# logging into your pi via wifi

load the SD card into your pi
wait about a minute for it to boot up

now go to a windows computer and hit the windows button

type
CMD  hit enter

you will see a command prompt

type:
ssh pi@mothbox.local


after just a second or two, it should find your pi
it will ask you if you want to continue, type "yes" and hit enter

and then it will ask for the password

enter the password, hit enter

## Raspi Config
now type

`sudo raspi-config`

hit enter
you will see the raspi-config menu come up


go to interface options
go to "VNC"
enable VNC


go to FINISH

# VNC "Headless" connection

Starting with raspberry pi operating systems since oct 2023, you have to use something like https://tigervnc.org/
Download https://tigervnc.org/

open the program

enter 
`mothboxstation.local` and hit connect
to continue hit yes
type your username and password
e.g. pi gimmemoths

your headless basestation for programming pis is now set!


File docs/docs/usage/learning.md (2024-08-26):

---
layout: default
title: Detailed Use
parent: Using Mothbox
nav_order: 3
---

# Basics

The Mothbox is a tool to study nocturnal insects. It is like a "camera trap" or "wildlife" camera built for seeing the diversity of insects in a specific area.

It works by turning on a bright, attractive light, and then taking photos of what insects come to visit the target. It has a programmable schedule to let it automatically do its jobs.

## Arm the Mothbox
The mothbox has two main states:
* "Standby" Mode
* "On" Mode

When the Mothbox is not in use we put it in a "Standby" mode so that it doesn't use all its battery when we don't want.

In "Standby" mode, there will be a wire that connects the pins in the top row that are 3 and 4 spaces from the right.


In "Armed" mode, the Mothbox will be ready to run its schedule. To put the Mothbox into "Armed" mode you just need to unplug at least one side of the wire.


_**Note: It is important that there is not a wire connecting those two pins before you deploy the mothbox, or it will not run!**_



`"Armed" mode - pin 4 only plug plugged in, or any other configuration than off mode`

`"Standby" mode - pins 3 and 4 plugged in`

## Physically Setup the Mothbox

If your Mothbox is Armed, you need to make sure it is correctly set up.
The main body of the mothbox should be set up already, but you might need to connect the arms and the target.

### Connect Arms
Each of the arms slides onto each side. You can then slide a bolt though to hold them in place.

### Connect Target
Next, you can slide the target onto the slots in the arms. 

### Connect UV Light
Finally connect the plugs from the UV light to the plugs coming from the Mothbox.

### Protect the Plugs from Rain

You probably want to put something around the plugs to stop rain from corroding them, especailly if the plugs are near the ground.

## Mark Data in your Deployment Sheet

The Deployment sheets are available for printing here:

[Mothbox Sheet Espanol](https://docs.google.com/document/d/1Sn3jC4s0dVqrYpLBVp6kmPejFT-jOzHI9VTb_M6Oyu4/edit)

[Mothbox Sheet - English](https://docs.google.com/document/d/1SwtdI_GMpgppiXMCZXmaISu_eI6gJFzdm-aJBgO5GPM/edit?usp=sharing)



or you can fill out the forms directly online here:
[Mothbox Sheet - Online Form](https://docs.google.com/forms/d/e/1FAIpQLSdgCwPrF7kEagmb3gvLT0CNaEj_S5SUKgE84Er7Go7YfueTxg/viewform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)

You should write down as many details as you can on your sheet right when your FIRST SET UP the Mothbox.
Then AFTER YOU COLLECT your mothbox you should add any additional notes

## Collecting Photos

### Getting the Photos out of the Mothbox
The mothbox will save its photos to the USB Disk that is plugged into it. 
To get the photos, open the mothbox. It is often helpful to first tilt the Mothbox forward so it is facing down (so the inside parts don't fall out)


then gently unplug the USB stick.


### Uploading the Photos to Our Online Space
Now we need to upload these photos to our online drive in order to process them.

We are currently keeping our Mothbox Data here:

[Mothbox Data Storage](https://drive.google.com/drive/folders/1M2GyCb7MS8cQ9kXmzxh7TNzs30UyYw63?usp=sharing)

1. Create a folder for your specific mothbox (if one doesn't already exist)


2. Open the folder and create another folder for the date of the night that the pictures were taken


3.  Copy all your photos from that night into this folder

After you have ensured that all these files are successfully uploaded, then you can erase this USB disk and put it back in the Mothbox

## Charging the Mothbox

The Mothboxes have an external power cable. You can connect these to a charger.



The batteries for the Mothboxes are a bit special. They have a light that is ON THE CHARGER that lets you know if it is charging.

* The light on the charger will turn RED when it is charging
* The light on the charger will turn GREEN when it is finished charging

The mothboxes also have set of 4 green lights on them. These lights are NOT reliable. When they have 4 green bars, the lights could be 50% charged or 100% charged. **The only way to make sure they are 100% charged is by plugging it into the charger.**

Each Mothbox battery takes about 6 hours to charge fully.

# Inspecting the Mothbox

## Inspecting a Mothbox BEFORE deploying
Deploying a Mothbox

    Disconnect from charger (if connected)
    Make sure USB stick is plugged in to blue USB ports on the Raspberry Pi
    Visually inspect the pi juice battery is in place
    Make sure the "OFF" wires are disconnected so that the Mothbox is armed.
    Close the box, and latch the lid closed
    Make sure the camera chassis is not tilted too far
    Make sure UV light switches are on and plugged in/ connected

Before the Mothbox automatically starts, It will likely be in standby mode. It will probably be flashing green and blue or showing blue from one single LED. If the LED is red, that means there is probably a problem with the pi juice battery.

Set the Mothbox up in an area in the configuration that works for you:

    Tied to a tree
    Mounted on a tripod
    Mounted on a table
    Suspended on ropes

Make sure that the Mothbox is not in a precarious situation where it might face danger from:

    High winds
    Human or animal traffic
    Potential of theft

And do your best to mitigate these dangers.

## Inpsecting a Mothbox AFTER it has run

When you recover the mothbox during the day first you can do a visual inspection:

    Is there any moisture inside
    Any physical damage
    Anything obscuring the camera lens

If the box smells burned or there's water inside, or the lens is steamed up or obstructed, note that

Then When you bring it to a place with a laptop You can do a software inspection:
Usb files

Look at USB stick files. Are there photos from the previous night? Are there photos from 7:30-8:30, 10:30-11:30, 1:30-2:30, 4:30-5:30? Are any of those intervals missing?

Copy photo files to Google drive, delete them from the stick, and put the USB stick back in the moth box
Changing mothbox settings

## Setting up for a Night 

_The sun is setting, the agouties are starting to head home, and the moths are preparing to come out…_

### Deploying a Mothbox 

* Disconnect from charger (if connected)
* Make sure USB stick is plugged in to blue USB ports on the Raspberry Pi
* Visually inspect the pi juice battery is in place
* Make sure the "OFF" wires are disconnected so that the Mothbox is armed.
* Close the box, and latch the lid closed
* Make sure the camera chassis is not tilted too far
* Make sure UV light switches are on and plugged in/ connected

Before the Mothbox automatically starts, It will likely be in standby mode. It will probably be flashing green and blue or showing blue from one single LED. If the LED is red, that means there is probably a problem with the pi juice battery.

Set the Mothbox up in an area in the configuration that works for you:

* Tied to a tree
* Mounted on a tripod
* Mounted on a table
* Suspended on ropes

Make sure that the Mothbox is not in a precarious situation where it might face danger from:

* High winds
* Human or animal traffic
* Potential of theft

And do your best to mitigate these dangers.

### Inspection while it's running 

The default schedule for the Mothbox is:

Every night, four hours: 7:30-8:30, 10:30-11:30, 1:30-2:30, 4:30-5:30

When it's running it should automatically turn itself on and will likely light up a bright UV light. About every minute it should take some photos with a flashing white ring light.

At the end of its scheduled running time, It should turn itself and it's bright UV light back off.

## Post-processing Mothbox 

### Inspecting that the deployment went well

When you recover the mothbox during the day first you can do a visual inspection:

* Is there any moisture inside
* Any physical damage
* Anything obscuring the camera lens

If the box smells burned or there's water inside, or the lens is steamed up or obstructed, note that

Then When you bring it to a place with a laptop You can do a software inspection:

#### Usb files

Look at USB stick files. Are there photos from the previous night? Are there photos from 7:30-8:30, 10:30-11:30, 1:30-2:30, 4:30-5:30? Are any of those intervals missing?

Copy photo files to Google drive, delete them from the stick, and put the USB stick back in the moth box

#### Changing mothbox settings 

can change the times it photographs with the schedule setting file on the USB stick. Edit using the notepad program.

If not making any changes, file name should read "no_schedule_settings". If making a change to the schedule, change file name to "schedule_settings"

### Preparing for future deployment

Plug battery in

Charger block red when charging

Make sure power strip is on

Takes 6 hours to charge

## Other notes:

There's a set of pins sticking out the top of the mothbox's electronics. From the right side (The side where the USB stick plugs in), If you look at the top row and count from the right side, I have marked pins three and four on this image below with red dots (note pin 3 from the right would be labeled p27 and pin 4 is labeled GND):



can change the times it photographs with the schedule setting file on the USB stick. Edit using the notepad program.

If not making any changes, file name should read "no_schedule_settings". If making a change to the schedule, change file name to "schedule_settings"

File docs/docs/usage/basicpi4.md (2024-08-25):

---
layout: default
title: (Pi4 Version) Basic Use
parent: Using Mothbox
has_children: true
nav_order: 8
---

# Turning the Mothbox on and Off
Because the Pijuice is connected, you cannot simply turn the Pi of the mothbox on and off by just removing power.  Instead, near the charging light on the pijuice, there is a small button. 


- Press it once to turn ON
- Hold it for more than 20 seconds to turn OFF

# Basics
The current basic mothbox image loads up a Raspberry pi instance. If you are logged into it (via our standard user and pass)
`User: pi`
`Pass: luna`

You can VNC into the device by going to RealVNC or TigerVNC, and being connected to the same WIFI and logging into
`mothbox.local`
or oftentimes just
`mothbox`
works

and inputting the user and password when asked

you will see a normal pi operating system desktop with a cool moth background. There is one folder on the desktop called "Mothbox" with everything you need inside it. There are scripts and picture storage and logs that get recorded when the mothbox automatically runs the scripts.


## Changing the hostname
The hostname is the name of the device you are logging into your mothbox remotely with (via ssh or vnc)

for instance it's the part called "mothbox06" when you are logging in via a command like 
```
ssh pi@mothbox06.local
```
If you are trying to work with multiple devices at the same time though, it can be useful to give them all a unique name
type
`sudo raspi-config`
then go to "System Options" -> "Hostname"
and you can change it to something else (e.g. mothbox08)

it will ask you to restart, and when it restarts it will have a new name you need to connect to it with.

## Changing the wifi connection
This is simple to do on the desktop at the upper right corner you can just click the wifi icon and log in to a new wifi


or if you are not using the desktop, and are using the command line, you can  go to

`sudo raspi-config`
then go to "System Options" -> "Wireless LAN"





# Modifying the Schedule
I created a simple way to change the schedule of the mothbox by just using a CSV file
You just open the "schedule_settings.csv" file

and you can tweak these numbers. Note that pijuice has a glitch where you cannot specify multiple days per month, you can only do multiple "weekday" entries divided by a semicolon

## UTC time offset
You can also add a UTC time offset that will automatically convert the values for you for the Pijuice. For instance panama is UTC -5, so you can put -5 as its offset and then just put the hours of the day that you want in the CSV

## Specify runtime
You can also specify a "runtime" this is how long the mothbox will run for, attracting insects and photographing them every 2 minutes (eventually we can tweak this parameter too)

This script is called by cron
`@reboot /usr/bin/python3 /home/pi/Desktop/Mothbox/Scheduler.py`

# Modifying Schedule and Wakeup Times (Old Manual Way)
Note: If you cloned and image, and you load it into the pi, it will not start auto-matically waking up because the PiJuice has not yet been initialized. For instance here is what the "Pijuice settings" look like from a freshly cloned image put into a new mothbox. See how the Wakeup alarm has not yet been enabled?


For right now one option is to go into the new RPI, go to Pimenu->Preferences-> PiJuice Settings
then go to the "Wakeup Alarm" tag

Set your wakeup alarm to the schedule you want.

For instance if you wanted the Pi to wakeup every day at UTC 18:30 you would need to set up the tag like this:


Make sure to check "Every Day" , mark the hour as 18, and mark the minute as 30.

then click SET ALARM and check WAKEUP ENABLED, and the hit "APPLY"

If there are multiple times you want to make the Mothbox Run, you can just set these times separated by a semi colon

for instance, here's an example with the mothbox set for a basic nightly agenda of turning on at 8pm, 10pm, 12am, and 3am


Note how all those times are shifted by 5 hours because of the difference in Panama and UTC time zones

# Debugging Cron
if you want to stop cron jobs from running you can disable cron via convenient scripts that start or stop the cron. just double click them and run them!



you can also use these commands
```
service cron stop
```
or re-enable via
```
service cron start
```

# Modifying Camera Settings (new CSV editor)
I created a way to simply

# Modifying Camera Settings (old manual code)
You can tweak many of the values of the photos you take like a normal manual camera.

Inside the MOTHBOX folder o the desktop, you will find a script called, "TakePhoto.py"
If you open this script in an editor, and scoll down, you will find the line that actually sets the camera controls.

`picam2.set_controls({"AnalogueGain": 2.0,"AeEnable": False,"AwbEnable": False,"AwbMode": controls.AwbModeEnum.Tungsten, "ExposureTime": 9000,"LensPosition": 7.6})`

Tweak these values to change things like exposure time, gain, and focus (lensposition)


Then you can always run these scripts by pressing the big "Run" button in Thonny to test them out!

# Linux on a Windows Box
https://sigkillit.com/2022/10/13/install-linux-on-windows-with-wsl/

# Shrink a Rpi Image
https://sigkillit.com/2022/10/13/shrink-a-raspberry-pi-or-retropie-img-on-windows-with-pishrink/

# Pins being used
the Pijuice uses GPIO 2 and GPIO 3 for the i2c, and GND and 5v. (but it passes those through)

our relay uses GPIO 
Relay_Ch1 = 26
Relay_Ch2 = 20
Relay_Ch3 = 21

for our ARM switch we will use GPIO pin 6 and GND
and Debug mode as GPIO pin 5 and GND

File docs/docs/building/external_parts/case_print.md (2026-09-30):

---
layout: default
title: Case (3D Print)
parent: External Parts
#has_children: true
nav_order: 0
---

The lastest version of the Mothbox has a [3D printable case](https://github.com/Digital-Naturalism-Laboratories/Mothbox_Hardware/tree/main/Mothbox_Pro)! We have been testing it fiercely in the wettest part of the wet season for months in jungles of Panama, and it's held up wonderfully! Nice and dry, easy to use, minimal manual labor! Plus it's cheaper than buying and hacking your own case!

bafyreigxwn7cq5ghlw5eaawb537jzpo2kwqx2pz3c4gti5zpbkwmoganmy

# Parts

* Main Filament - 850 grams
* TPU Rubber Filament - (Optional for better waterproofing, not really needed in dry places) - 100 grams
* Clear Acrylic - For the front window and arms and target (arms are ideally 3mm, and front window can be 1-3mm (we use 2mm))
* #6x3/8in screws - (not super exacting, near equivalents work too!)
* Cable Ties - Ideally reusable zip ties, or silicone straps, or our [TPU printable ties we made ourselves](https://www.printables.com/model/1530721-reusable-rubber-cable-tie)!
* DC Barrel sockets -  for the external charging port and/or external attractor port

# Printing and Filament Suggestions
## Bed size
Everything should be able to be printed on a medium size 3D printer (256mm minimum bed size)

## Nozzle
Printing: everything can be printed on standard .4mm nozzles BUT we also made it so if you want to speed up your prints you can also **print all the designs with .8mm (.4mm layer height)** nozzles!

## Filament

**Never use PLA for outdoor equipment**, especially in the tropics as it will degrade rapidly.

**PETG or PETG-HF**
Regular PETG prints nicely and is super durable in the field. Also if you have a high flow nozzle and can use the high flow version of PETG it can print extra quick!

**ASA**
We have also tested out ASA filament which is supposed to be the filament of choice for outdoor equipment. It prints super smooth, but needs higher temps and a chamber. Note that ASA shrinks a little bit, our design tolerances SHOULD accommodate this for your setup, but if things are tight, that's why!

**TPU**
For the 3D printed TPU rubber, we have been using Bambu lab 85a

{: .note-title }
> Shrink TPU
>
> For the TPU gaskets it can be useful to print them slightly smaller. I usually shrink X and Y at 99% to make them fit nice and tight (and offset the stretching that tends to happend when you pull it off the build plate).

**PETG-CF**
We have been using inexpensive PETG-Carbon Fiber filament ($~16 USD for 1kg - Eryone brand), drying it for 12 hours, and then printing. It worked totally fine, and in theory should have advanced heat-dissipation abilities and strength, but honestly regular PETG seems just as good but is cheaper and easier

# Print all the Parts
All the parts are located in the [Github Repo](https://github.com/Digital-Naturalism-Laboratories/Mothbox_Hardware/tree/main/Mothbox_Pro). Download them all and print them out. There is even a 3MF file that has all the parts laid out for you to print in a slicer like Orca Slicer.



The list of parts is as follows along with what material to make them in.

* Outer Shell - PETG or ASA
* Inner Chassis - PETG or ASA
* Glare Blocker - PETG or ASA
* Back Lid - PETG or ASA
* Front Lid - PETG or ASA
* Front Gasket - TPU (Optional seal for wet climates)
* Back Gasket - TPU (Optional seal for wet climates)
* Bottom Plugs - TPU (Optional, if you aren't using DC Barrel Sockets to fill all the holes)

These parts are usually laser cut
* Arms (These are usually laser cut for more viewability of the insects)
* Top Shield (Laser cut because cheaper and faster, but could be printed)
* Target (Laser cut because cheaper and faster, but could be printed)

This part MUST be laser cut
* Front Plexi - This needs to be optically clear for the camera to see out of. If needed you could employ the hack from the DIY - off-the-shelf enclosure and 3d print a front plate you cut a hole and glue a glass lens filter in, but in general you want just simple laser cut plexi.

# Box Versions
 in 2025-2026 we primarily used the v5.0.3 version of the hardware. This is a simple to print box with a back lid that can be connected with bolts or ties

 In mid 2026 we made a new version, 5.1.0, that has a couple changes
 * there are more, molle-like, connectors for cable ties
 * the back lid's top connects with a cleat and cable ties
 * There is an optional top shield which can be set on top and held with zip ties for more weatherproofing.
 * There is a THIRD hole for an extra port or button on the bottom



In this tutorial we will show how to assemble the different versions

# Outer Shell Assembly
## Front Acrylic
Peel off any protective plastic from your clear acrylic.


Lay your front rubber gasket on the front section. (If you are not using the rubber gasket, you can just put the acrylic straight onto the box.)



Put the acrylic on top of that. It make take a little pressure to pop in. Make sure the holes line up correctly.


Screw the front plexi to the case. Only screw until the screw is snug. Don't overtighten or you may crack the plexi.


Attach all the screws!


## Bottom Ports
There are 2 holes in the case that let you connect to the outside world. Generally they will get used for 
* a charging port
* a port to attach an external attractor

Label your ports to help you keep track! PET-G is quite easy to label with a permanent marker!


### Prepare your Sockets
Slide the little rubber lid thing onto your socket.


Press the plug into the hole. Depending on your printing tolerances it might slide in, or you might need to even screw it in a bit.



- If you are NOT going to use an external attractor, you can simply pop one of the rubber plugs into the other hole.



- If you are going to use an external attractor, you can just add another socket to this other hole.


### Connect Sockets Inside

Depending on your specific sockets you order, some are longer than others and can be screwed down.

Most types of sockets though are going to be held in place with our friend, Mr. Hot Glue.


Surround the port with a thin layer of hot glue. This should hold everything in place pretty well! You can even go over the rubber plug for extra security if you want!


## Back Lid + Gasket
(Skip this step if you are not using the gasket)


Collect the Back lid and the back gasket. Lay the gasket into the lid to make sure it lines up in the correct orientation.


With a hot glue gun, add TINY drops of glue to the corners of the gasket to help hold it in place. 

Press down firmly to make sure there's no raised areas where you added the glue.


## Front lid
There's not really anything you need to do for the front lid. Just print it out and pop it on! It's just to protect the front plexiglass when transporting!


# Finish Assembly with the Electronics
Head over to the [Mothbox Pro electronics section](https://digital-naturalism-laboratories.github.io/Mothbox/docs/building/mothbox_pro/v5.0.3/assembleincase/) to finish installing the mothbox into your new case!

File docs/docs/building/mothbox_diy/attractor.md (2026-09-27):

---
layout: default
title: Attractor
parent: Mothbox DIY
#has_children: true
nav_order: 8
---

The next step may vary from Mothbox to Mothbox. It's about choosing what type of light (or in the future maybe chemical?) based attractor you want to use. We are still experimenting with the most cost efficient and effective LEDs one can find, but luckily the openness of the Mothbox design lets us be flexible and have many options.

There are three basic options for your attractor.

- TOC
{:toc}

#  Internal Mothbeam
We have been using the awesome Mothbeam made by Moritz at [LabLab](https://lablab.eu/). He designed these PCBs to be super low cost, high power, modular, adapatable insect attractors! We have been using pairs with one PCB with a range of UV, and another PCB with an array of useful visible light.

To get one, you can:
* order them from him by emailing him (moritz@lablab.eu) (the cheapest way), and they are about $90 for a pair.
* [order them from circuithub](https://circuithub.com/projects/Moritz/Mothbeam/revisions/57895/parts) (the most expensive way)
* or because it's open source, you can get the files from circuithub and make the PCBs yourself! The tricky part is that because they are high power LEDs, they are made on a heat-dissipating aluminum substrate. Keep that in mind!

What's nice is you can arrange them in different ways. You can put them together in a container and use it just like a Lepiled or other portable insect attractors. You could then connect these assembled "Mothbeams" as an ["External Attractor"](https://digital-naturalism-laboratories.github.io/Mothbox/docs/building/mothbox_diy/attractor/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)




## Build Mothbeam
{: .no_toc .text-delta }

They need to dissipate heat, and fit flat in the front of the Mothbox. 
* Cut a thin piece of metal that fits at the top of the Mothbox. We use perforated aluminum and some metal shears.
* put a piece of thermal silicone on the back of each Mothbeam PCB. (remove the protective plastic first)
* screw them to the piece of aluminum.
* connect the aluminum to the Mothbox.
* route the wires through the little gap near the top.
* connect the negative wire to all the other negative wires.
* connect the positive wire to the attractor relay on the far left.





PXL_20240806_160534615 MP

# Internal 12V UV Light
You can purchase 12V UV LEDs easily with many commercially available options. Often many will be too large to fit inside the Mothbox, BUT most of the design of these devices is just a large metal case that works as a heatsink. If you take them apart, you will often find the actualy 12V LED is just a thin part.

For instance, these [inexpensive 10W flood lights](https://www.amazon.com/gp/product/B01LT53312/ref=ppx_yo_dt_b_search_asin_title?ie=UTF8&psc=1) 
unscrew very easily and consist of just a simple circuit board connected with thermal glue to the metal case.


You can take these apart, and using thermal silicone double sided tape (and maybe a little extra glue or screws), connect these UV LEDs to a piece of metal mounted inside the Mothbox, like with the method described above, for an Internal Mothbeam.







# External 12V UV Light

Using the [same method for adding an additional charging port](https://digital-naturalism-laboratories.github.io/Mothbox/docs/building/mothbox_diy/wiring/#add-charging-port) we described earlier, you can add an additional OUTPUT port to the bottom of your Mothbox. This new external port should be connected to the same relay as you would hook up any of the attractor options. Then you can simply use a DC cable to connect whatever 12 V light you wish to use outside of the Mothbox.

Here's a step-by-step guide for how to add an External 12V UV Light.

You need
* 12 V UV Lights [inexpensive 10W waterproof flood lights](https://www.amazon.com/gp/product/B01LT53312/ref=ppx_yo_dt_b_search_asin_title?ie=UTF8&psc=1) 
* Waterproof connectors [e.g. [these twist-on connectors are easy](https://www.amazon.com/gp/product/B0CNHW1FBF/ref=ppx_yo_dt_b_search_asin_title?ie=UTF8&psc=1)]
* DC barrel jack cable plug
* Extra DC barrel jack waterproof socket
  
PXL_20240805_164551924 MP

## Prepare the external light
{: .no_toc .text-delta }

We are using these twist-on waterproof connectors because they are about the easiest way to connect wires in a waterproof way. They are full of a silicone goo that keeps water out.

PXL_20240805_164603120 MP

Take your red wire from your light and the red wire from the barrel jack cable and twist them together.



Twist the black wires together as well. Then stick them inside the connectors and keep twisting until they feel connected tightly.



### Test the light
{: .no_toc .text-delta }

Plug it in to a battery to make sure it works!
PXL_20240805_164951918 MP

### Seal it up even more if you are concerned about humidity and moisture.
{: .no_toc .text-delta }

You can heat shrink it.



You can even fill it full of hot glue if you are worried about water (like if you live in the rainforest!). But honestly, the twist nuts full of the silicone goo are probably good enough.





## Add an External Attractor Port
{: .no_toc .text-delta }

Following the instructions for adding the charging port we described earlier, just drill another hole next to that one.


Take another DC socket. To keep myself from confusing the charging port and this new UV OUTPUT PORT, I color it purple with a marker.


Your internal charging port should already be connected to a barrel plug. Add a lever nut to your new attractor port, 
PXL_20240805_171126747 MP

and add a red and black wire to it.
PXL_20240805_171341509 MP

Connect the black wire to the ground (or the extra ground wire of the voltage regulator).
PXL_20240805_171434485 MP

{:.note}
> I colored the attractor port purple with a permanent marker so that I wouldn't confuse it with the charging port.

Connect the red wire to the attractor port of the relay.


Test it all out! It should light up when the Mothbox turns itself on and starts running its routines.
PXL_20240805_171728517 MP

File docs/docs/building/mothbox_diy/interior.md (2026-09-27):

---
layout: default
title: Interior
parent: Mothbox DIY
#has_children: true
nav_order: 7
---

The inside of the mothbox has also been improved in version 4.0

There is only one laser cut mainboard, and it fits more securely inside the box.

There are 11 laser cut pieces you will assemble with electronics parts.


* Main board
* 4 clips attach to main board (2 wide, 2 thin)
* 6 camera glare blocker circles

# Camera Glare Blocker
The function of the camera glare blocker is to set the camera a little bit in front of the super bright lights so that they don't cause a glare that interferes with the image quality.

## Assemble Camera Lens Glare Blocker
Take your six circles and stack them on top of each other.


{: .note }
> There is a small arrow with a dot at the top of each camera glare blocker circle. All the arrows and dots should be lined up on top of each other.



Place two zip ties through the side holes of the small glare blocker circles to connect all 6 circles together. 



Finally, using two M2 screws, you can attach the camera into place. You can use 4 screws if you really want, but 2 is sufficient.


## Attach Camera Glare Blocker to Mainboard
Using the two holes directly to the side of the vertical center holes at the top and bottom. Secure the Camera Glare Blocker to the mainboard.


{: .note }
> The Camera Glare Blocker needs to be lined up correctly with the main board. You can use the small arrow to line it up with the mainboard. The arrow also points to the Mothbox Logo.




# Ringlights
These two circular lights function to evenly illuminate the target area to get high quality images of the moths. We use these ring lights, which are originally sold as inexpensive illuminators for microscopes. They are some of the cheapest and highest density bright LEDs we can find, and they work well for taking photos of our moths.

{: .note }
> **More Built-in Redundancy** Each mothbox ideally uses two ring lights to illuminate the target. If necessary, though, (for instance, if one light breaks in the field, and you have no other options) one ring light can be used and placed directly around the Camera Glare Blocker.

{: .note }
> It's best to use 2 ringlights of the exact same brand, as some can be slightly brighter or differently colored than others, leading to uneveness in image quality.

## Disassemble Ring Lights

We need to disassemble the ring lights before we can add them to our mothbox. This is so we can make them smaller and controllable.

Basically, you want to remove all the plastic to turn your ring light from the product on the left, to the bare ring with two wires sticking out of it pictured on the right.


For most of the ring lights, you just need to figure out how to pop the plastic container off. Usually there are a couple small screws you can use to disconnect the plastic. Some have a hidden screw that can be found underneath a sticker.

Peel back the sticker and then unscrew the screw.



The front cover of the ring light should easily pop off now.


Some ringlights will now have all the electronics free. Some may still have some internal screws left connecting the circuit boards to the plastic. Unscrew them and remove it.


Now use some kind of thin tool (e.g. a spudger) or flat screwdriver to pry off the front plastic cover of the ring light. 





### Identify the Power Source
Some lights have a barrel jack and others have a USB cable. Either way, they will lead to a red and black wire. Snip them off so you still have plenty of wire connected to the LEDs. Remove all the electronics from the plastic.




## Snip Control Knob Electronics Off
From the current version onward, we no longer need to keep the voltage control knob. That's because we are using our own 12V regulator.
This makes wiring _much easier_.

PXL_20240908_222638718 MP

You basically just want to end up with the ring of LEDs with a red and black wire sticking out of them.

{:.note}
> Older versions of the Mothbox kept the control knob on the ring lights. If you see images with those knobs still in tact, don't worry about it - those are just out of date images.

## Connect Ringlight

### First Side
Feed the wires of the ringlight through the hole and position it flat against the mainboard.


Add zipties in these two locations to secure it.


One ring light should be finished and attached like this!



### Second Side
Place the second ring light with the wires towards the big open gap.



You can zip its wires in place to stop them from getting tangled in things and help protect them


Add zipties through these two holes.



After your ringlights have been physically connected in place, just let their wires dangle out the backside. We will connect them in the next step, [wiring](https://digital-naturalism-laboratories.github.io/Mothbox/docs/building/mothbox_diy/wiring/)

# Connect the Raspberry Pi
It sits in the corner of the mainboard. The connection points for the Raspberry Pi all have a tiny extra hole right next to them. This helps you locate the exact holes for the Raspberry Pi.






{: .note }
> We will only connect 3 of the holes of the Raspberry Pi, because one is hidden behind the ringlight. (If you wish to connect the 4th hole, make sure to use a plastic bolt.)

Add three of the spacers on top of the Pi's holes like this.


Screw them in from the other side.


## Connect the RTC battery
Make sure to plug the battery into the Pi5's little battery slot. This battery keeps the clock accurate even if the Pi loses power.


# Trim Your Zip ties
Now is a good time to trim up the ends of the zip ties.




{: .note }
> You want to make sure no zip tie parts are sticking out too far where they will get in the way of the Camera Glare Blocker when the internals are loaded into the box.
 
# Connect the camera cable to the Raspberry Pi
Connect the ribbon cable to the Raspberry Pi. If you are using a Pi5,** make sure to connect to the first slot labeled "Cam0."**



# Attach Relay hat to Pi
You will now connect the sockets on the relay hat to all the shiny metal pins sticking out of the Pi. First move the camera ribbon cable to the side of the bolt sticking out of the Pi.



Place the relay hat on top of the Pi. Line up the GPIO pins and press softly down.


{: .warning }
> Be careful to not pinch the ribbon cable going to the camera.
 







## Tape the RTC battery on top of the relays

This is just to keep it out of the way and to stop it from getting tangled.

Attach a piece of double sided tape to the little battery. Then stick it on top of the relay. Make sure the battery and the wires are not blocking the screw holes or entrance to the battery.



{: .note }
> In this image, it kinda looks like there are too many fingers.



{: .important }
> Don't block the screw holes on top of the relay.
 
# Connect the Battery

Unscrew these three screws from the bottom of your battery.



Save the screws for the next step.

{: .important } 
> Make sure to press down firmly when unscrewing the screws so you do not strip the heads.

Now screw the screws back in, connecting the battery to the mainboard. You don't need to screw it in too tight or you might strip the internals of the battery. Just tighten them so the battery is firmly connected.



# Add the Clips to Mainboard
Now you can attach all the little plastic standoff clips to the edges of the mainboard. These hold the mothbox electronics firmly in place, with the camera and lights in the correct positions inside the plastic box.

{: .note } 
> If your mainboard still has protective plastic, you might need to peel it off from the mainboard before attaching the clips. Sometimes the protective plastic makes the acrylic sheets too thick for the clips.



There are 2 LARGE clips and 2 SMALL clips.

The locations of the LARGE clips have RED arrows. 
BLUE arrows point to SMALL clips.







# Internals Constructed!
Next you just need to [wire all your electronics together!](https://digital-naturalism-laboratories.github.io/Mothbox/docs/building/mothbox_diy/wiring/)

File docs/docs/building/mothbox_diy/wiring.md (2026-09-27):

---
layout: default
title: Electronics Wiring
parent: Mothbox DIY
#has_children: true
nav_order: 7
---

Finally, we will connect all the electronics to make our Mothbox work! There is no soldering required, just lever nut connectors and wire strippers.
We worked hard to keep the electronics as simple as possible so many people will be able to build this. There may be more "elegant" ways of connecting everything together, but we tried to make the wiring style as easy to understand as possible. 

Follow along and fear not!

# Overview
Here's a full circuit diagram of the **Mothbox wiring**. You basically connect the battery to a 12V regulator (which gives consistent brightness over the life of the battery and extends its life). This 12 Volt power goes to the relays which then switch the  Attractor lights and the Flash lights switch on and off.
wiringdiagram_mothbox_withregulator_directRinglight

If you have a older setup, there are some other diagrams available for [wiring without a 12V regulator](https://github.com/user-attachments/assets/aa502498-299c-49f2-9ff4-01c33dac4519), or if you decide to [keep the brightness knobs on your ring lights](https://github.com/user-attachments/assets/fb5ca51b-cd33-489f-a2d8-3ad79a540979).

# Battery Output to Regulator
## Start from the OUTPUT of the battery


Start with a barrel plug wire with two free ends. I actually chopped my barrel plug wire from one that came with a power supply for the LED ring lights!

PXL_20240908_230151540 MP

This is the plug that will go into the OUTPUT of the battery. **Don't plug it into the battery yet!** We want to safely connect everything first and then connect it!



Next we will prepare the 12V regulator.
## (New!) 12V Regulator
The mothbox uses a 12V li-ion battery to power its lights. This is because Li-ion batteries (like the talentcell) tend to be the cheapest and most energy-dense batteries you can find. One problem is that 12V Li-Ion batteries should more properly be called ["11 Volt batteries"](https://www.youtube.com/attribution_link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). This is because as they discharge, most of the battery life is spent **11.9 volts and under.**



A lot of 12V equipment is tolerant of slightly lower voltage, but things can go wrong, such as the light dimming. Thus, if you want your Mothbox to run for longer and have consistently bright lights (which can be important for experiments!), there is a pretty easy fix! You can just add in a 12V regulator booster. This is a $11 device you can add in between the battery's output and the rest of the mothbox connections.

## Prepare the 12V Regulator

The regulator looks like this black box with 4 wires coming out. 1 Red, 2 Black, and 1 Yellow.
PXL_20240908_225805285 MP

Often these devices only have a little bit of wire sticking out, and it's necessary to use wire strippers to trim the ends so we have about 1cm of bare wire to work with.

PXL_20240908_225906321 MP

## Connect Regulator and Barrel Jack Plug
Use an inline wire nut to connect the red and black wires from the barrel jack to the red and black wires on the left side of the regulator.

PXL_20240908_231305779 MP

# Regulator to Relays
On the yellow wire of the 12V relay, connect a lever nut with at least 3 ports.
On the black wire of the 12V relay, connect a lever nut with as many ports as you can (ours has 5). 

PXL_20240908_231730313 MP

{:.note}
>If you end up needing more ground ports, you can always connect another lever nut to this nut with another black wire.



Cut two red wires that are about 10cm long and stick them into the lever nut connecting to the yellow wire.

PXL_20240908_232626850 MP

## Connect the centers of the relays
Now connect these two red wires to the centers of the two relays on the left side of the board as pictured below. Use a screwdriver to tighten the connection.

PXL_20240908_232829553 MP

You are halfway done with the electronics wiring! Congrats!

# Connect the Lights

## Chop the Ring Light Knob (if you haven't already)
If you haven't already, chop the control knob electronics that came with your ring light. In older versions of the Mothbox we used to keep this, as it regulates the power to the ring LEDs. But now that we use a 12V regulator, we don't need this part. Those control knobs were also finicky and often were manufactured with weak wires. They resulted in about 90% of the failures we saw in the field. So good riddance!
PXL_20240908_233422021 MP

Make sure to trim the wires sticking out of the ring lights so you have at least 1 cm of bare wire to work with.

PXL_20240908_233536107 MP-1

## Start with Ring Light Near front of Battery
Now add an inline lever nut connector to the ring light that is in front of the battery. Connect a red and black wire that are each 10cm long to this.

PXL_20240908_233803873 MP

## Ring Light Under Battery
Now add another inline lever nut to connect the ring light that is below the battery. This light should have a red and black wire coming out of it that are both **20cm long.**
PXL_20240908_234115204 MP

## Connect Both Ring Lights to Relay
Take both the RED wires from each ring light and make them go into the left port of the center relay (as shown below).

PXL_20240908_235626674 MP

Both wires can fit in this port together. Just tighten down the screw and make sure to give a tug test to make sure neither of the wires are loose.
PXL_20240908_235632082 MP

## Connect the UV Attractor Light
There's a couple different options for [what kind of UV attractor light you want (Internal, External,etc...)](https://digital-naturalism-laboratories.github.io/Mothbox/docs/building/mothbox_diy/attractor/) No matter which option you go with, your attractor light will have a RED/PURPLE (Postive) and BLACK (negative) wire coming out of them. I used a purple wire for my UV attractor light so I would remember it is for a UV light, and it shows up easier in the documentation photos below to let you understand what I am talking about. You can use a red wire if you want. 

Take the positive (red or purple) wire from the UV attractor light, and connect it to the left most slot in the left most relay. (Shown as the purple wire in the photo below).

PXL_20240909_000014650 MP

# Connect all the NEGATIVE GROUND wires together
Finally, take all the black wires from the 2 ring lights and the UV attractor light and connect them to the black wire coming from the 12V regulator.

PXL_20240908_235821006 MP

# Stick down the Regulator
Finally add a piece of double sided tape, and just stick it onto the battery so it doesn't jiggle around.



Most of the wiring has been completed! Only one part to go!

# Add Charging Port
A nice waterproof charging port makes it much easier to use the Mothbox! It's not too difficult to add either!



You need a plug and a socket DC barrel jack with cables. And you can also use a inline lever nut to connect them.



Mark your spot for the port. You can use a marker to note the spot. Right between the big gap between the flanges is a good spot. You might notice my pen mark is a bit to the left. That works, but actually around where I put the red dot should be easier.



Drill a hole. Our socket is a little over 3/8 in in diameter, so i used a 3/8 in drill bit to make a hole, and then wiggled it around a bit to make it large enough to fit. 



You can use a razor blade to remove any burrs from the edges of the hole you made.



Slide the socket into place. The rubber stopper and gasket should be on the outside, and the metal washer and nut should come on the inside after it. Tighten it well.



If you are concerned about moisture, you can hot glue or silicone around your port to make it extra secure.



## Wiring the Charging Port
Use an inline lever nut to connect the socket to the plug.




Now you can connect the plug to the IN port of your battery.


Try it out! Your battery should charge now when it is connected to the external port.


When you aren't charging it, you can put the rubber cap over the port to protect it from moisture.




Hooray, your charging port should be all set!


# Add Arming/Disarming Wires
The default behavior of the mothbox is to turn on whenever its schedule dictates (or when there is a change in power, or the power button has been pressed), and then start illuminating the attractor and taking photos every minute.

Sometimes you want to temporarily disable the mothbox from running. For instance, if you are travelling overnight somewhere, you might not want 20 mothboxes to start lighting up in the backseat of your car. There is a simple way to add two wires that let you ARM and DISARM the Mothbox.

Get two jumper wires. One wire should be SOCKET-PIN, and the other should be SOCKET-SOCKET.


Plug the SOCKET-SOCKET plug into the pin labelled P27 (Third pin from the left).


Plug the SOCKET-PIN plug into the pin labelled GND (Fourth pin from the left).


So you should have a wire plugged into both P27 and GND now. 

Whenever those two pins are DISCONNECTED from each other, the Mothbox is ARMED and ready to go!
PXL_20240909_044023484 MP

If you CONNECT these two wires together (grounding pin P27), then the Mothbox will be DISARMED and will never turn on (until these pins are eventually disconnected from each other.)



Next you can decide if you want to add a voltage monitor (below), or a [Solar Panel or Extra Battery](https://digital-naturalism-laboratories.github.io/Mothbox/docs/building/external_parts/powersources/), or if you haven't yet made your [UV attractor, it's time to do that!](https://digital-naturalism-laboratories.github.io/Mothbox/docs/building/mothbox_diy/attractor/)

# (Optional) Connect an Eink display
If you purchased a [little E-eink display](https://www.waveshare.com/wiki/2.13inch_e-Paper_HAT_Manual#Working_With_Raspberry_Pi) to get a better idea of what's happening inside your mothbox's brain, then you can easily connected it!

It should come with a set of colored wires attached to a connector. The connector plugs into the display, and then the wires connect to the pins coming out of your raspberry pi like so:

| Epaper Pin | Physical Pin on Pi |
|---|---|
| VCC | 3.3V |
| GND | GND (20) |
| DIN | 19 |
| CLK | 23 |
| CS | 24 |
| DC | 22 |
| RST | 11 |
| BUSY | 18 |

if you have your Relay hat on (which you probably do), the connections will look like this (for reference the white cable is going between RST and pin 11):


Then, i usually put a glob of sticky-tack on the back of the display, and connect it to the battery to keep it in place.




# (Optional) Monitor your voltage!
The mothbox images are programmed to monitor and log their voltages. This doesn't affect their use, but there may be situations for advanced users where you might want to only turn your mothbox on if it has a certain percentage of its battery charged. For instance, if you connect a solar panel to your Mothbox, you might want to wait until your battery is fully charged before arming it to run for an entire night.

If you want to add this optional ability to your Mothbox, here's how to do it!

Purchase a $12 [Adafruit power sensor](https://www.amazon.com/gp/product/B07S8QYDF8/ref=ppx_yo_dt_b_search_asin_title?ie=UTF8&psc=1). Solder its parts together. 

Follow the [wiring guide from Adafruit](https://learn.adafruit.com/adafruit-ina260-current-voltage-power-sensor-breakout/python-circuitpython) for how to connect the 3.3V GND SDA and SCL wires.
sensors_INA260_RPi_cropped

Run the MeasurePower.py script included on the Mothbox Github.

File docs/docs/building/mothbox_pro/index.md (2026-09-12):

---
layout: default
title: Mothbox Pro
nav_order: 0
has_children: true
parent: Building
permalink: /docs/building/mothbox_pro
---

The Mothbox Pro is our Mothbox designed for manufacturing scalability. The key difference is that we designed an Open Source PCB that can be industrially manufactured for cheaper than buying all the parts needed for a Mothbox DIY. The PCB also has some bonus features like physical switches, light sensors, and more!





# Choose your hardware version

There are now multiple versions of the Mothbox Pro mainboard. Pick the instructions that match the board you have:

* [**v5.0.3**](https://digital-naturalism-laboratories.github.io/Mothbox/docs/building/mothbox_pro/v5.0.3) - the previous version of the Mothbox Pro. Complete, tested build instructions.
* [**v5.0.6**](https://digital-naturalism-laboratories.github.io/Mothbox/docs/building/mothbox_pro/v5.0.6) - the upcoming version of the Mothbox Pro. *Documentation coming soon!*

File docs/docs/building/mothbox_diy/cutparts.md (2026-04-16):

---
layout: default
title: Cut Parts
parent: Mothbox DIY
#has_children: true
nav_order: 2
---
The new v4 version of the mothbox has a more efficient design, and all the acrylic parts can be cut from one 50x60cm piece of acrylic.


# Acrylic
In the [Github, there are files for all the parts you need to cut.](https://github.com/Digital-Naturalism-Laboratories/Mothbox_Hardware/tree/main/MothboxDIY/Laser%20Cutting%20Layouts)
You can use the dxf files, or we even made layouts of many of the components in lightburn files for you. There is even a [file of "all acrylic parts"](https://github.com/Digital-Naturalism-Laboratories/Mothbox_Hardware/blob/main/MothboxDIY/Laser%20Cutting%20Layouts/v4/AllAcrylicPartsInOne.lbrn2) that you could cut in one go on many standard laser cutters.

Cut all these parts out of 3mm acrylic.

The cam glare blockers should be cut out of OPAQUE acrylic if possible (or you can spraypaint them black if needed).

The arms should be cut out of CLEAR, UNCOLORED acrylic if possible. 

Otherwise, the colors don't really matter.


# Felt
The only other part to cut out is the felt cover for the target. Find some white acrylic felt and cut out the file that says "Target Material."
Acrylic felt cuts really easily and cleanly in the laser cutter.
PXL_20240808_162242291 MP

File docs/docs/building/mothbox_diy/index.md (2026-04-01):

---
layout: default
title: Mothbox DIY
nav_order: 1
has_children: true
parent: Building
permalink: /docs/building/mothbox_diy
---

# Mothbox DIY
The Mothbox DIY version is for you to build a device with entirely off-the-shelf materials. This guide will show you how to construct this type of mothbox from scratch!



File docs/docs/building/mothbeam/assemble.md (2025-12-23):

---
layout: default
title: Assemble
parent: Mothbeam (Insect Attractor)
#has_children: true
nav_order: 5
---

# Connect PCBs to Metal

If you have the optional thermal transfer silicone pads, you can attach those to the backs of the mothbeams. If you don't have them, don't worry.


Place a mothbeam on each side of the metal rod. (If you are using 4 pcbs, you probably want to arrange them in a star shape if their edges interfere with each other.)


Use a cable tie to go through the tops of the PCBs to hold them snugly against the metal. 

If your ties are too thick to go through the holes, you can just go around the PCB.

You could also drill holes in the metal and connect your mothbeams even better to the metal (this would be the ideal, non-lazy choice, and it will offer and even tighter coupling)

Add more zip ties to bind the bottom area of the PCB to the metal.

Snip ends of ties


# Set PCB power

There are little switches that can determine how much energy your PCBs output. The more power, the brighter the LEDs and maybe the more chances they will attract bugs. Conversely your battery will run out quicker and the device will produce more heat.

You can use the end of a wire to move the tiny switches.

In this image I set the first three switches. This is probably the reccomended HIGH power mode (350mA).  You can flip the final switch, but that is ULTRA MAX power mode (450mA). 2-3 switches is good for attracting lots of bugs. 


The power values selectable are

* 120mW (12v @10mA)
* 960mW (12v @80mA
* 1800mW (12v @150mA) 
* 3600mW (12v @300mA)
* 5400mW (12v @450mA)

# Wire PCBs

Cut 2 10cm red and black wires
Cut 2 20cm red and black wires


Connect the black wire between two of the GND (-) ports of the Mothbeam.

Connect the Red wire between two of the +12V ports of the Mothbeam.



Add the two long wires to the middle of one PCB



(Optional) Hot glue the wires gently into place



You can now test if your wiring is correct by connecting it to power.

# Build Housing
Slide the top lid (the lid with no extra hole), onto the metal rod. Hot glue it to the rod. (If you are working with very high heat LEDs you might want to use epoxy, but normally hot glue is fine)



Now slide the acrylic tube around the PCBs.



Next, slide the bottom lid on and slide the long wires through its hole.





Glue the top lid to the metal shaft.



Glue the wire hole closed.



Finally, glue the acrylic tube to the lids to seal the whole device



# Connect the power wires
Finally you can connect the GND(-) and 12V (+) wires to the way that you will give it power. 
We demonstrate with connecting to a DC Barrel Jack.


# Test it out!
Plug it into a battery, yay it works!



Note that the metal may get HOT in use!

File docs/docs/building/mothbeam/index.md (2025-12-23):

---
layout: default
title: Mothbeam (Insect Attractor)
parent: Building
nav_order: 9
has_children: true
permalink: /docs/building/mothbeam
---

# Standalone Mothbeam Assembly
This guide will show you how to create a low cost insect attractor!


# Origin
Moritz at [LabLab](https://lablab.eu/) originally designed the [Mothbeams](https://certification.oshwa.org/de000156.html). He created them to be open-source, low cost, high power, modular, adapatable insect attractors! Many other lights available can cost $100-$700 USD, and so we wanted a cheaper option. We have been using pairs with one PCB with a range of UV, and another PCB with an array of useful visible light.

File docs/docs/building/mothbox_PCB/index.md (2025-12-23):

---
layout: default
title: Mothbox Kit
nav_order: 2
has_children: true
parent: Building
permalink: /docs/building/mothbox_PCB
---

# Assembly
This newest version of the Mothbox is super fast to assemble! You only need

* Mothbox PCB
* Arducam 64mp camera (owlsight)
* Raspberry Pi 5
* 32 MB A2 SD card (and better)
* Battery

and you are set!

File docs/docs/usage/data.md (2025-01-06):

---
layout: default
title: Data Organization
parent: Using Mothbox
nav_order: 7
---

# Documenting Deployments
Equally as important as the photographic data you collect is the metadata about your deployments.

We have printable forms that field technicians can take to their sites: 

* [English Metadata Field Sheet (Printable)](https://docs.google.com/document/d/138JZj5jImSbsMy4HENhGG927nZ7LnpokHBwIVP40MgM/edit?usp=sharing)
* [Hoja de metadatos de campo en español (imprimible)](https://docs.google.com/document/d/1a0biZUbMgTlj4iQnYNFXaaA3HtSSpRODiZAXmBr1tMo/edit?usp=sharing)

Alternatively, fill out the [online version of the form (bilingüe)](https://docs.google.com/forms/d/e/1FAIpQLSdgCwPrF7kEagmb3gvLT0CNaEj_S5SUKgE84Er7Go7YfueTxg/viewform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).

{:.important}
> Remember to collect this metadata for EVERY SINGLE DEPLOYMENT or else it is not useful in the end!

{:.important}
> All photos from a single deployment should be in a folder named with the convention: "AREA_POINT_MOTHBOXID_YYYY-MM-DD"

#Mothbox ID
The Mothboxes all have a unique, persistant name (based on the Pi's serial number). The names are in the format of (descriptiveword+animal) and are made from the thousand most common descriptive words and animals in both English and Spanish.

This is why you will have names like "CoolJirafa" or "PrizeCrab."
The name should be written on a sticker on the Mothbox. Like "FondoGorila."

PXL_20240909_045245636 MP

# Structuring Data

Semi-Automated Insect Identification is still a relatively new field, so there are not many standards to follow to help us organize our data. Therefore, we are trying to base our metadata formats off existing types of scientific data collection and processing such as camera trap data.

All the data collected is unique to a specific time and place. Each time period when a Mothbox is set into the field and then collected is called a "Deployment." A deployment could last several days or even weeks. 

In physical space, we currently organize deployments into different zones:

Country-> Area -> Point

The Country is the country where the Mothboxes are deployed. The "Area" is the broader region or group it is being deployed with. For instance, it might be "Gamboa" or "Barcelona."

The "Point" is a specific descriptive name for where the Mothbox is actually being used. For instance "GuasimoTreeBackyard" or "VineNearRioFrijoles."

## Photo and MetaData

"Raw photo" data looks like this:



We send those images to an insect detecting AI, which then creates "individual photos" of each creature detected in the raw image. It would look like this:

gradoVerdín_2024_07_25__21_12_05_HDR0_crop_0

For each individual photo of a single insect we collect, we eventually want it tied to the following information as well:

* occurrenceID (file name with unique timestamp of the specific individual photo ("gradoVerdín_2024_07_25__21_12_05_HDR0_crop_0.jpg")
* basisOfRecord (i.e. MACHINE_DETECTED)
* deployment ID
* eventDate (timestamp)
* GPS data
* raw_photo (location of the original "raw photo")
* identifier (Who did the most up to date ID? i.e. "Mothbot" or "Hubert Szczygiel"
* cv_confidence (how confident the AI was in detecting this if machine detected)
* Taxonomic information: class	order	family	genus	species	commonName	scientificName


# Inventory of Mothboxes
If you are running a project with many Mothboxes (more than about 4), you probably want to start keeping an inventory. Field equipment can get lost, forgotten, or busted up, so it's handy to know what you have available if a new opportunity strikes!
Here's an [example of how we organize our inventory of mothboxes](https://docs.google.com/spreadsheets/d/1W60RJSNnirpbALVyalLmYodYBUhqQkD_vb8ZOFOarns/edit?usp=sharing). (If you have suggestions for better organizational schema, please let us know!)

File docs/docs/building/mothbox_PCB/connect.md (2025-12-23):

---
layout: default
title: Connect Electronics
parent: Mothbox Kit
#has_children: true
nav_order: 1
---
# Connect all your electronics

(coming soon)

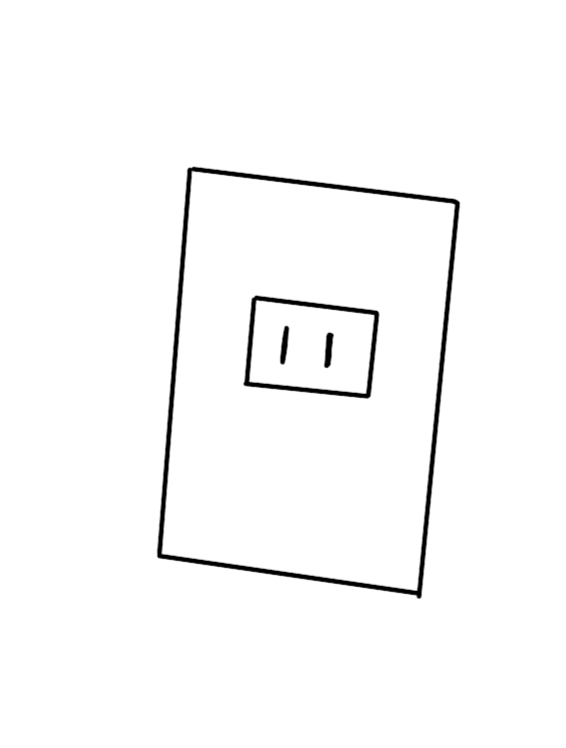
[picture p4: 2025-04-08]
docs/Quick Reference Guide/linkedimgs/3E4E0CEA.png

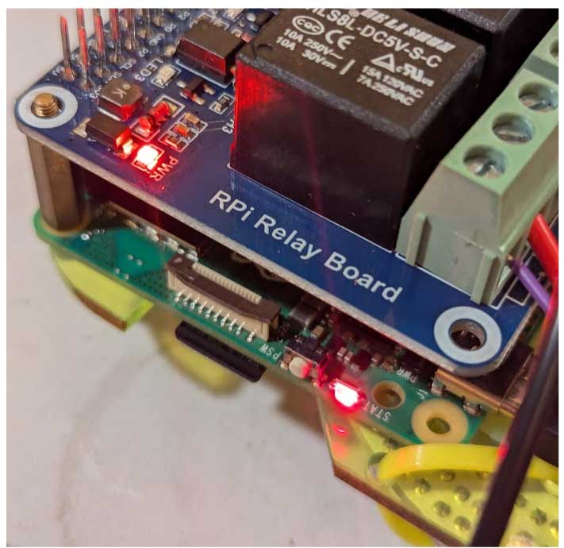
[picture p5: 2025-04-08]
docs/Quick Reference Guide/linkedimgs/147DD46.jpg

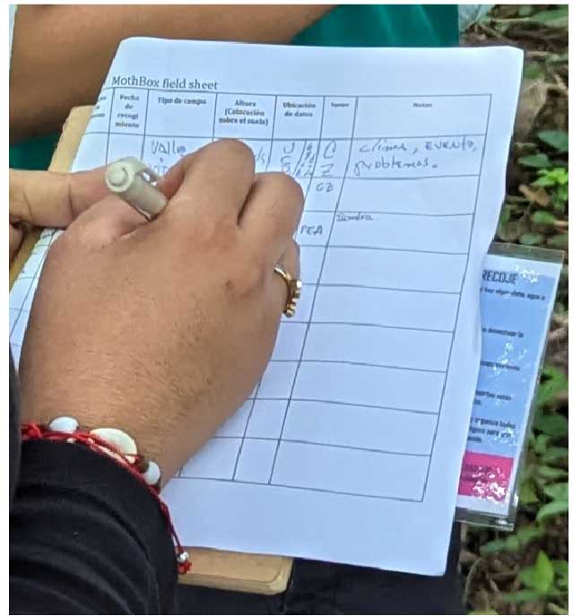
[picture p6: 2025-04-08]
docs/Quick Reference Guide/linkedimgs/3E4E0CE2.jpg

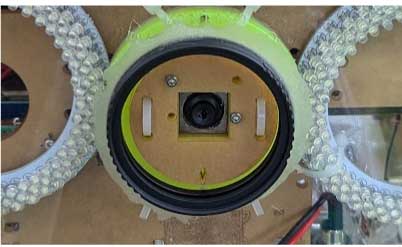
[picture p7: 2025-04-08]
docs/Quick Reference Guide/linkedimgs/1D35AEF4.jpg

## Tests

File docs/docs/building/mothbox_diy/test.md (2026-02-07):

---
layout: default
title: Test
parent: Mothbox DIY
#has_children: true
nav_order: 8
---
If you want, you are now at a stage where you can test if all of your electronics are set up correctly! You need to make sure about a couple of things before you test the Mothbox though.
{: .note }
> Before you test, make sure:
> - Make sure your battery is FULLY CHARGED!
> - Make sure to [flash the firmware onto your SD card](https://digital-naturalism-laboratories.github.io/Mothbox/docs/usage/initialsetup/#flash-firmware)
> - Then proceed!

If your battery is all the way charged, and you have the Pi image flashed to your SD card in your Pi, then you are set to go!

# Connect to Battery

{: .important-title }
> Important: Charge the Battery Before First Use!
>
> When you purchase the batteries, they are often not fully charged! This can be a problem because several people have connected their pi's to a barely charged battery and the low-power causes them to "brown out" and have eeprom errors (where you then have to use the raspberry pi imager to reset the bootloader to get your pi working!)

The Talentcell batteries may work a bit different than you are used to. You need to make sure the battery's power switch is set to "On"
1fa99c2d-2f04-4c1a-99c8-b2f886d633de
and you need to plug in the charging cable. 
89c8d0fb-9d72-4c14-9f52-55b8ca5f633e

The battery is only 100% charged when the LED on the charger goes from red to green.

{: .note }
>Ignore the green lights on the battery. They are not good indicators of if the battery is charged or not. The battery can show 2 green bars but still be 90% dead.

Now is the big moment to see if everything works! You can connect the plug to the OUT port of the battery.



Also plug a USB cable into the Raspberry Pi and connect it to the battery's USB port.


When you flip the battery's switch to "on", everything should turn on!


At first just the little LEDs on the Pi and the Relay will turn on.

# First Boot Up
The first time a Mothbox boots up with a fresh SD card, it will take a lot longer to start up than normal. It has to do all kinds of prep things inside the SD card that take up time on the first launch. It will often shut itself down after it does a first launch. So the first time it gets powered, just wait 10 minutes. If it doesn't turn on after that, restart the power and it should start up soon.

# Second Boot Up
Sometimes the Mothbox will automatically launch the very first time you turn it on, but again, don't worry if not. Just wait 10 minutes and restart it if it hasn't started.

On the second boot, after a minute or so, the operating system will have loaded up, and the whole device should go into "Mothbox Mode," turning on the UV attractor and flashing the ring lights every minute.




If something is not lighting up, check the connections you wired up!

If everything is looking good, it's time to start [USING YOUR MOTHBOX](https://digital-naturalism-laboratories.github.io/Mothbox/docs/usage/basic/).

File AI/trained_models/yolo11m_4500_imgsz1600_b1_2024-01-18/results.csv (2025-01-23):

epoch | time | train/box_loss | train/cls_loss | train/dfl_loss | metrics/precision(B) | metrics/recall(B) | metrics/mAP50(B) | metrics/mAP50-95(B) | val/box_loss | val/cls_loss | val/dfl_loss | lr/pg0 | lr/pg1 | lr/pg2
1 | 1310.57 | 2.05226 | 4.79477 | 2.58511 | 0.61645 | 0.56442 | 0.60251 | 0.28961 | 1.56127 | 1.87538 | 2.01093 | 0.000666363 | 0.000666363 | 0.000666363
2 | 2627.35 | 1.68721 | 1.84446 | 2.10516 | 0.54533 | 0.50549 | 0.54969 | 0.27532 | 1.53917 | 1.76636 | 1.95786 | 0.00131983 | 0.00131983 | 0.00131983
3 | 3997.11 | 1.6017 | 1.59153 | 2.02446 | 0.66643 | 0.68977 | 0.66986 | 0.34313 | 1.43814 | 1.71246 | 1.89494 | 0.0019601 | 0.0019601 | 0.0019601
4 | 5389.34 | 1.58731 | 1.50154 | 1.9958 | 0.74209 | 0.71393 | 0.77383 | 0.40042 | 1.44115 | 1.44051 | 1.83727 | 0.0019406 | 0.0019406 | 0.0019406
5 | 6753.53 | 1.54428 | 1.37906 | 1.95627 | 0.76184 | 0.75575 | 0.77689 | 0.41279 | 1.4566 | 1.47594 | 1.84131 | 0.0019208 | 0.0019208 | 0.0019208
6 | 8124.32 | 1.49339 | 1.29802 | 1.92437 | 0.66789 | 0.57041 | 0.58363 | 0.33661 | 1.41848 | 1.93872 | 1.8279 | 0.001901 | 0.001901 | 0.001901
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

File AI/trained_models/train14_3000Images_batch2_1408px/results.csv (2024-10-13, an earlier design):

epoch | train/box_loss | train/cls_loss | train/dfl_loss | metrics/precision(B) | metrics/recall(B) | metrics/mAP50(B) | metrics/mAP50-95(B) | val/box_loss | val/cls_loss | val/dfl_loss | lr/pg0 | lr/pg1 | lr/pg2
1 | 2.4309 | 7.5482 | 2.8485 | 0.31323 | 0.4293 | 0.34486 | 0.14702 | 1.6306 | 2.3638 | 1.8636 | 0.00066578 | 0.00066578 | 0.00066578
2 | 1.9048 | 2.6162 | 2.1767 | 0.40776 | 0.56361 | 0.45441 | 0.20183 | 1.5151 | 5.1437 | 1.7865 | 0.0013193 | 0.0013193 | 0.0013193
3 | 1.8264 | 2.2361 | 2.0692 | 0.53541 | 0.5631 | 0.53687 | 0.23484 | 1.5156 | 1.8191 | 1.6488 | 0.0019595 | 0.0019595 | 0.0019595
4 | 1.7968 | 2.2124 | 2.0211 | 0.39803 | 0.44501 | 0.34306 | 0.15873 | 1.5658 | 6.7664 | 1.7728 | 0.0019406 | 0.0019406 | 0.0019406
5 | 1.7064 | 1.9639 | 1.9926 | 0.54203 | 0.61127 | 0.55335 | 0.24466 | 1.4537 | 1.9682 | 1.5877 | 0.0019208 | 0.0019208 | 0.0019208
6 | 1.6883 | 1.8999 | 1.96 | 0.58417 | 0.67613 | 0.64696 | 0.3 | 1.4555 | 1.626 | 1.6079 | 0.001901 | 0.001901 | 0.001901
7 | 1.6978 | 1.8477 | 1.9705 | 0.56664 | 0.65433 | 0.60626 | 0.29124 | 1.3843 | 1.6847 | 1.5548 | 0.0018812 | 0.0018812 | 0.0018812
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

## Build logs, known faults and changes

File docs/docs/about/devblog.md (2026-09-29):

---
layout: default
title: Development Blog
parent: About the Mothbox
has_children: false
nav_order: 7
---
# 2026 - Sep - 09
**Unified firmware! New case! New PCB! September \[Mothbox\] Updates!** *(from our [email newsletter](https://us20.campaign-archive.com/home/?u=4c29b4f7a39e89dd012b35960&id=6caba8d984))*

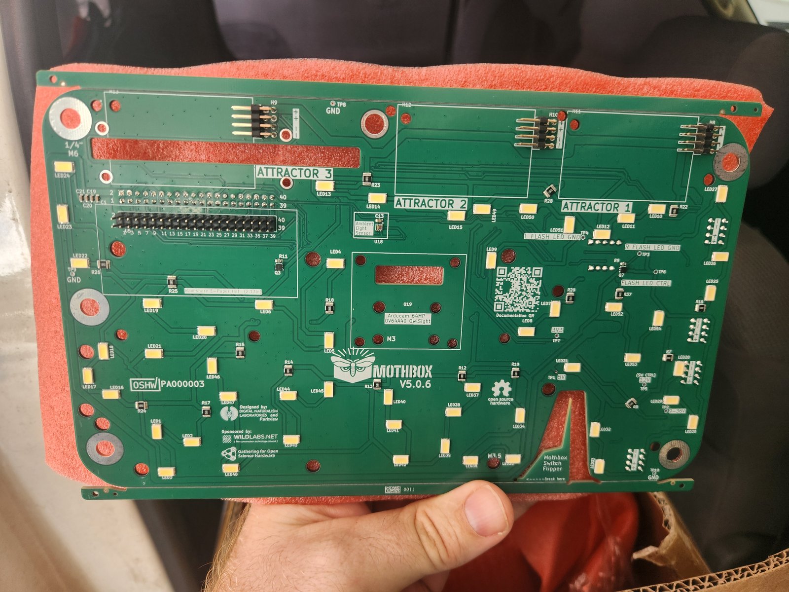
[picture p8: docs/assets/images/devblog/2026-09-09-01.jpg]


The Mothbox world tour has finished (though we are going to Montreal in 2 weeks to do more Mothbox work, so maybe the tour is still happening? ¯\\\_(ツ)\_/¯ )

By the way, ***if you are in Montreal (or maybe just in Canada)*** and want to order a Mothbox kit, let me know ASAP and I can try to bring up parts from Panama!

## Chat with Mothboxers around the Globe

As this project has grown, we have had a growing need for an online space where Mothboxers can help each other out. I have been not very excited about options like Slack or Discord due to their cost/closed nature/other weirdnesses, and so instead we are trying out using Matrix

**Mothbox Chat** [**https://matrix.to/#/#mothbox:matrix.org**](https://matrix.to/#/#mothbox:matrix.org)

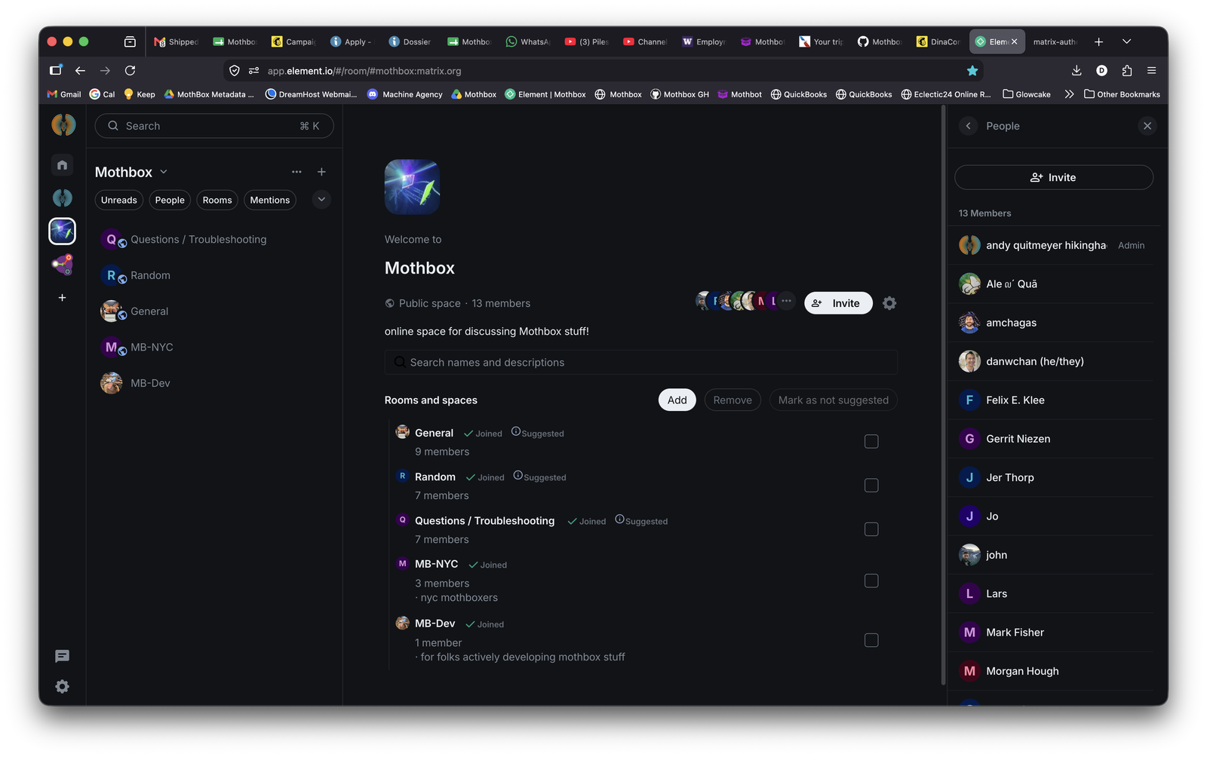
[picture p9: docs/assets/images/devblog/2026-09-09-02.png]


You can use it in a web browser,  or download the app "element X" to use it on a phone. It will ask you to sign up for a free matrix.org account and that's it! No fees, all open, nothing gets deleted!

**Bug Reporting**

If you find errors in the hardware or software, the best place to report these is still the Mothbox Issues:

<https://github.com/Digital-Naturalism-Laboratories/Mothbox/issues>

**Mothbox EMAIL!?**

Took us oddly long to make an email you can shoot mothbox questions to as well: i n f o [[ at ]] mothbox.      org. will take your messages to our whole group!

## New Unified Firmware

**Use one Pi Image to control all your Mothboxes!**

Since we created the newest version of the Mothbox, it became a bit annoying to have to keep track of which software and images we needed to keep each device up to date. But now I went back through our scripts and made it automatically try to detect which device you are using (you can also set it manually with the customizer!)

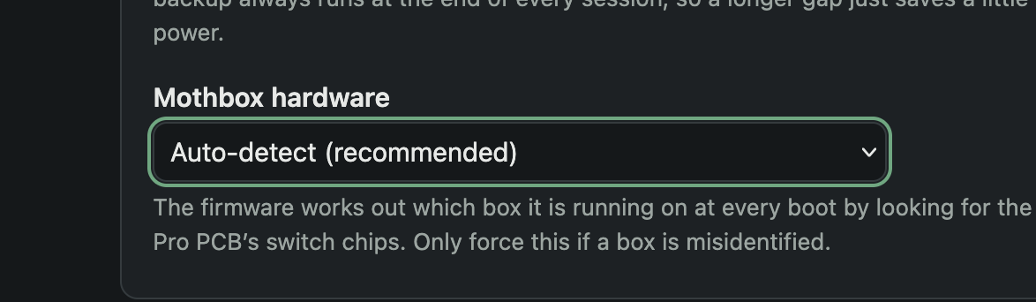
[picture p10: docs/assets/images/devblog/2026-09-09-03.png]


Try out the [latest firmware here.](https://drive.google.com/drive/u/0/folders/1o3aGB1MZUrNxRoGycFVw_ofUQehrjuqF)

**Easy Schedule Customizer**

Setting up a Mothbox to do what you want it to do is even easier now! We made a  super simple html file that lets you edit your mothbox settings csv!

You can [get the file here](https://github.com/Digital-Naturalism-Laboratories/Mothbox_Firmware/blob/main/mothbox_custom_Unified/mothbox_settings_editor.html). (in the latest version of the firmware it also just sits in the “mothbox_custom” folder on your Pi’s SD card).

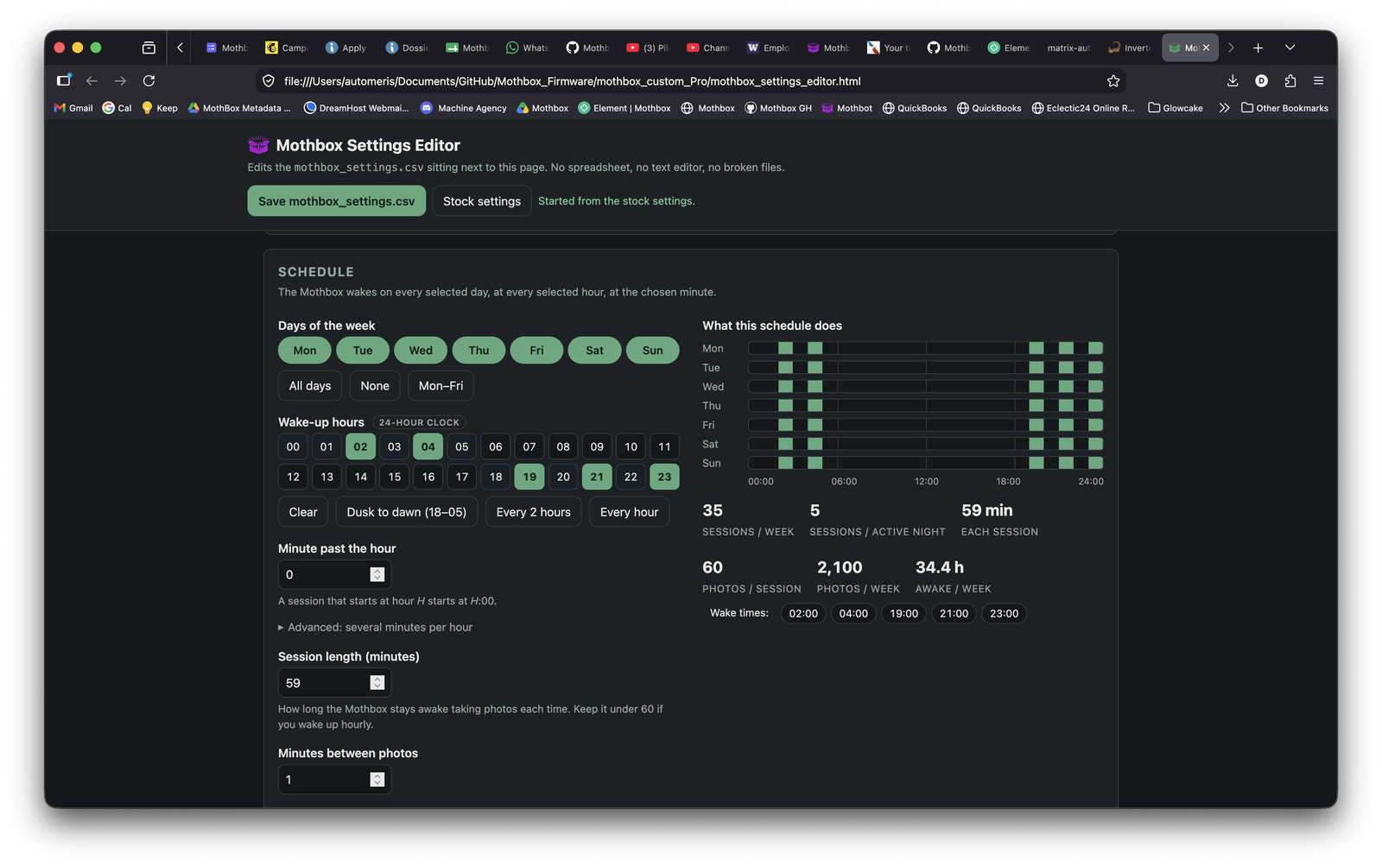
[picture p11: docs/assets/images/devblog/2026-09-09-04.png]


It gives you a friendly interface that will spit out a nice new mothbox_settings.csv file you can replace the current one with on your SD card. It can also help prevent weirdnesses that may happen when you edit the csv with something like excel.

**Faster Photos (hopefully less smeary fast-moths)**

Smeary bugs (caused by rolling shutter inherent to most digital camera sensors we use), can be fun (like this one from logan)! but ideally we want as fast of photos as possible. That's why we have super bright flash leds on the front to reduce exposure time. but that can take us only so far. I found a way to up the bus speed of the camera to have a 30% shorter exposure time, so hopefully that can make less smeary bugs! (can go from 1119 µs to 868 µs shortest possible exposure time)

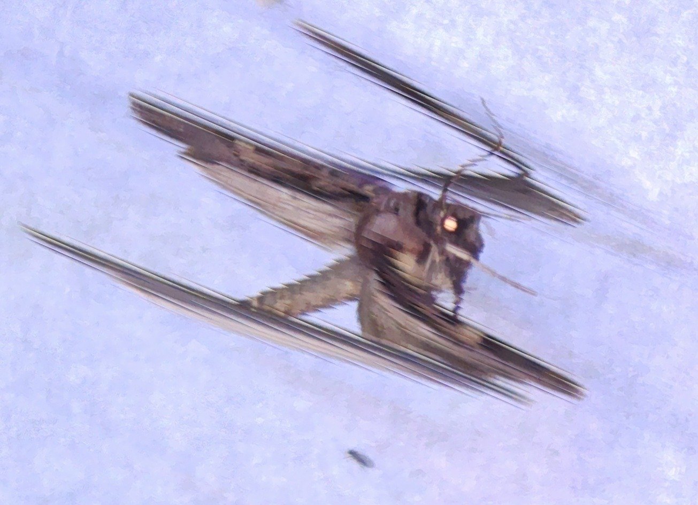
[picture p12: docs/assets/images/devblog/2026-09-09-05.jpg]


the higher speed does come with a caveat from Arducam that the camera can act less stably, but i think this moreso applies to people doing high bandwidth video recording, and we just simply take one little photo a minute, so it should be fine!

**Other firmware updates:**

- Add schedule customizer to boot/firmware
- Display shows schedule in temporal (not numerical) order. e.g (first evening hours then morning)
- Backup: At the end of a session, does an extra check to move any dangling photos to the SD card
- Bugfix: attract off used to turn off flash too. This basically would never come up, but fixed the script just to be meticulous
- Better EXIF: each photo now also includes sensor data if available (and the exif itself is better)!
- Speedier camera: see if we can get higher frame rate with

```
dtoverlay=ov64a40,link-frequency=456000000
```

https://docs.arducam.com/Raspberry-Pi-Camera/Native-camera/64MP-OV64A40/#__tabbed_2_2

## New PCB 5.0.6

I overhauled the PCB based on on dozens of workshops over the past half year of the grand tour!

**Zip Tie Maxxxxin**

Andy has a philosophy that Zip ties (cable ties), seem to be the most ubiquitous and lightweight connector one can find around the world. Also they are harder to lose in the wilderness! Thus we are working to make as much assembly cross-compatible with these ties.

- Added extra holes near attractors to connect with a single zip tie
- Extra zip holes in corner screw hole areas for easy zip attaching to the case

**Integrated Pokey Thing!**

Some people love our very manual switches to control your device without programming! Some people hate how tiny those switches are and suggested including a flipping tool! We built one! The PCBs now come with an integrated switch flipper made from part of the PCB that normally gets tossed!

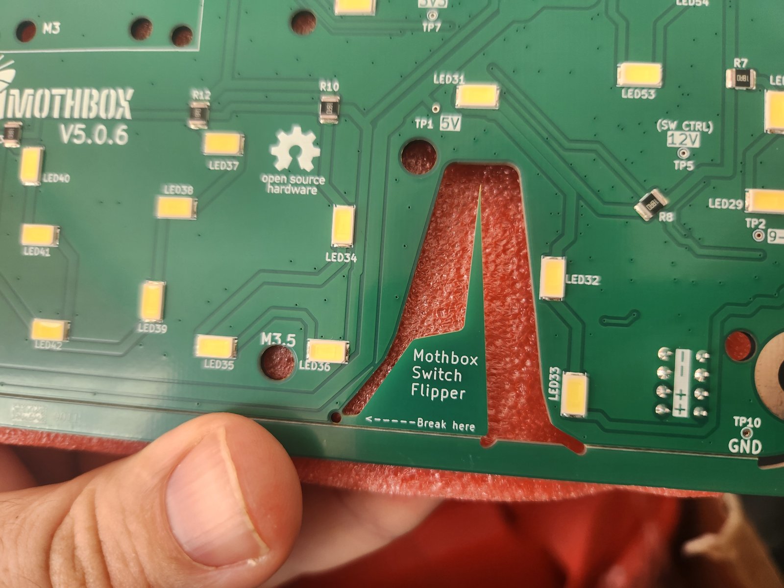
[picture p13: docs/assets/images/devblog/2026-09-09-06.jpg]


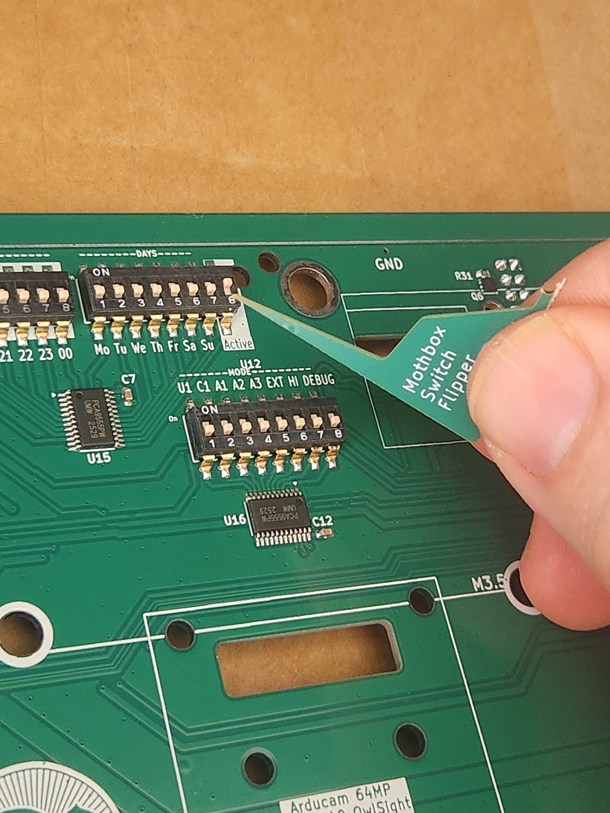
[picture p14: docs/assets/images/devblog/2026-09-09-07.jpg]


**Other Upgrades**

- Pi’s hole has been widened a bit to make it even easier to connect to PCB
- Silkscreen labels and part orientation of switches has been made more explicit to help manufacturers install the switches in the correct orientation
- Temperature Sensor has been scooted to give more clearance for batteries

**Upgrade KiCAD 10 (Had some minor difficulties)**

The latest PCB design files have also been updated to KiCAD 10, which is great for future proofing. (Though i had to deal with the more immediate consequences of this as this upgrade led to 2 minor errors: it dropped 2 capacitors from my BOM for the board, and 2 holes for the latest mothbeams. Both of these have been fixed in the latest github, but not until i got the latest PCBs and noticed!)

**For 5.0.7**

- Add spring terminals for slightly higher gauge wire

## New Case 5.1.0

latest and greatest hardware here: <https://github.com/Digital-Naturalism-Laboratories/Mothbox_Hardware>

I actually upgraded the old case from 5.0.3 to 5.0.4 with some tweaks, but then just went hogwild and made an even bigger overhaul. This also was the result of feedback and thinking over the past 6 months about ways to tweak the case to make it a) easier to use, b) easier to print, c) more weatherproof, and d) give more attachment options.

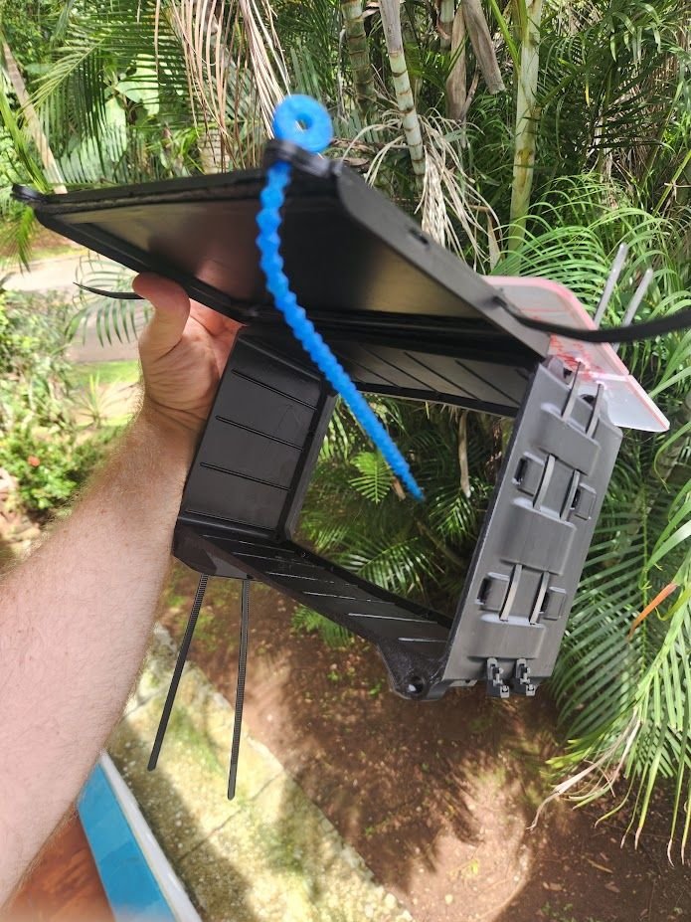
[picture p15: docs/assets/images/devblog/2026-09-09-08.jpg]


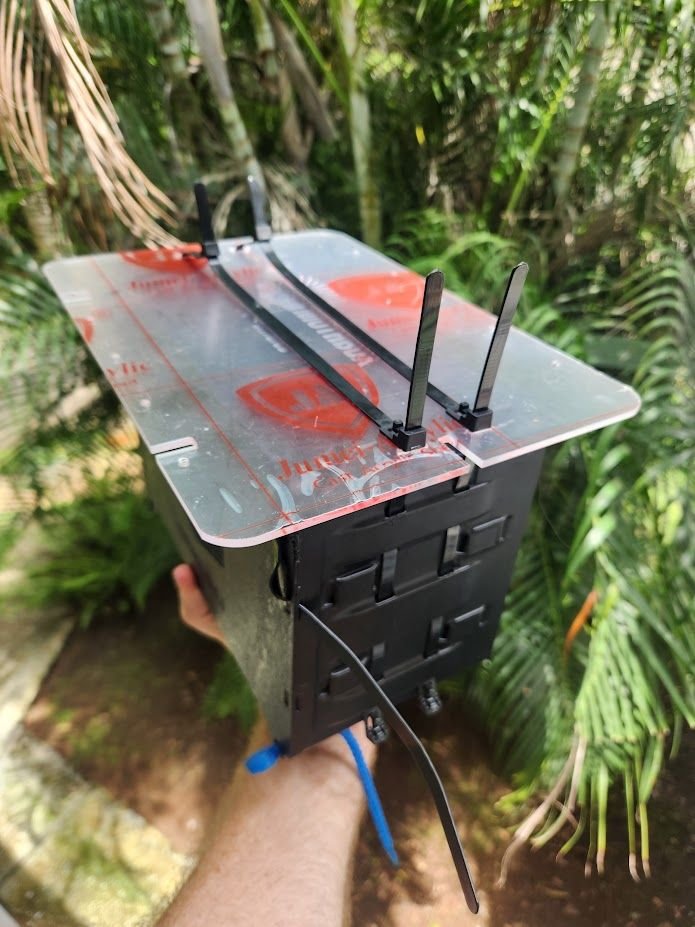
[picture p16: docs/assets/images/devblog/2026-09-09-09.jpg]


- Added strong criss-crossing molle-like attachment points for weaving zip ties through adding lots of of ways of attaching or connecting accessories.
- trimmed ~120 grams lighter shell!
- Zips distribute weight around the box + zips can connect legs straight on too!
- Integrated hinge!: Realized my "zip-tie's are the ubiquitous world-wide connector"-philosophy could be used for hinges! Easier to open and close with fewer hands! and importantly keeps our design unreliant on fancy printer tolerances or exotic materials. Instead cheap vinyl ties do the hard work!
- cleat for lid: There's also a cleat near the top to keep water and debris from flowing in near the top lid even if it is accidentally a bit loose. bigger news though is, you may have noticed the top looks a bit different though, and a bit flat, and there's a reason for that...
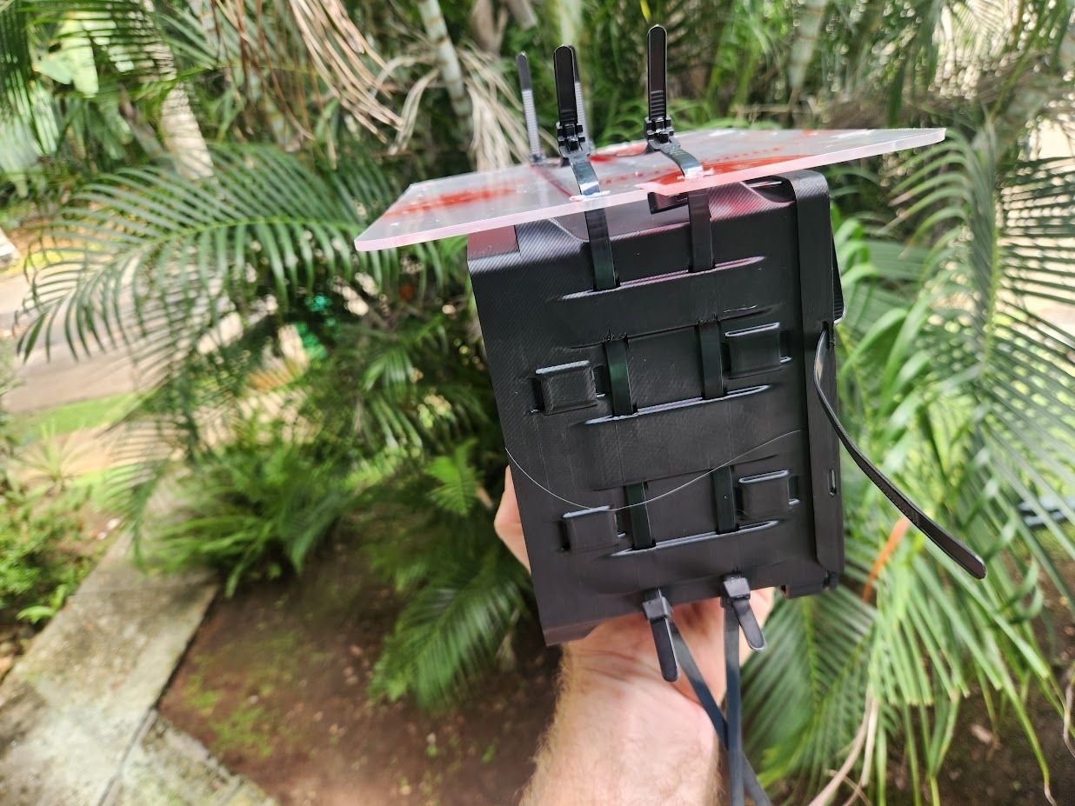
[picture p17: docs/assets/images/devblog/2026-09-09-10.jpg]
- 

  **Extra Waterproofing!**
- Solid, yet breathable Rain deflector! it lets you add a simple solid plastic sheet on top for extra waterproofing if desired! (a slightly modified acrylic target works great! You could even use a solar panel and most could be plugged straight into the box!)

  *Why a big extra roof?*
- Actually Solid: 3D printing can never be fully solid (without extra nasty goo and extra post-processing), but since we are laser cutting the front window anyway, we can cut another totally solid piece of plastic.
- Breathable: I was inspired by the architecture of tropical houses. They keep a gap to let stuff underneath release heat and stay dry!
- It's a bonus! If your target gets lots or breaks in the field, you can have a bonus one that is just the hat! and of course you can still totally use the device without its hat. it is just a bonus option!

**Organization**

- All loaded and organised in Orcaslicer (so you can easily print with any device!)

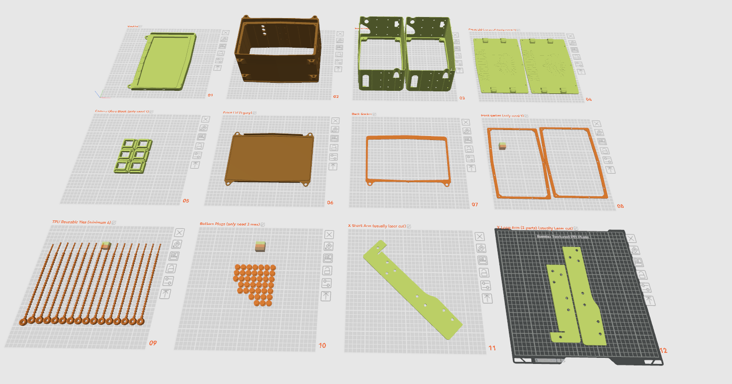
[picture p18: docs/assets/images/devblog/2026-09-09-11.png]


## Mothbox Interest? We got your message!

If you filled out our [Mothbox interest form](https://docs.google.com/forms/d/e/1FAIpQLSfi9uZ_ZCyryR8PCAIEaGi_4bSr2cWwznUFDQ-H5Bb0zSpnWg/viewform?usp=header), we want you to know that we got your message! Andy has been traveling and is out of Mothbox materials, and the open science shop crew in LA has also been low on supplies, so it might take us some time, but when we are prepped to start fulfilling some more orders, we will reach back out to you to confirm!

# 2026 - Aug - 30
**End of \[mothbox\] world tour, Montreal, RIP Jimmy, and other\[dinacon\] updates** *(from our [email newsletter](https://us20.campaign-archive.com/home/?u=4c29b4f7a39e89dd012b35960&id=6caba8d984))*

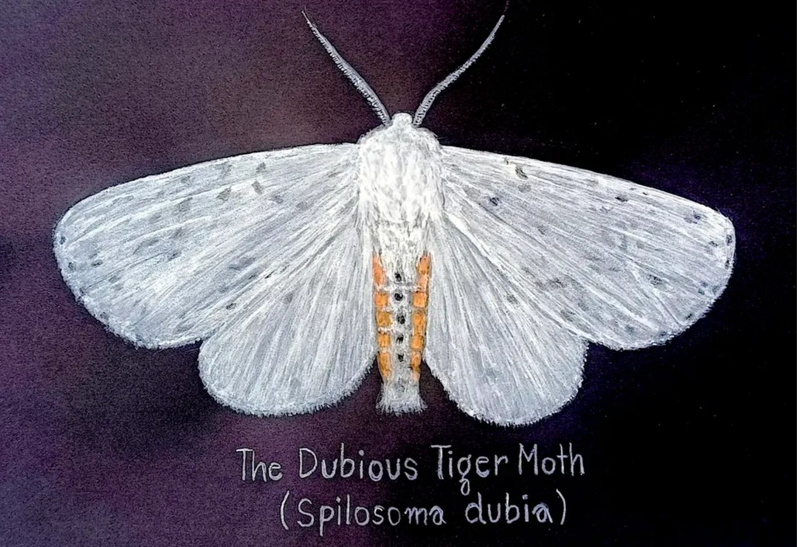
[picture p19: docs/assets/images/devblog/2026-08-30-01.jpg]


*(above: Pom’s Dubious Tiger Moth Illustration)*

Andy and Kit are finally back in Panama after 4.5 months of continuous traveling and mothboxing across the US, Canada, and Europe! Waking up to howler monkey cries and greetings from our Agouti friends is heartwarming.

Though spotted at times with heartbreak and funding despair, it has been an amazing trip getting to connect with hundreds of incredible people. Now we are prepping the latest Mothboxes while working on the next big move. (We have already made several tweaks on Mothbox designs based on feedback from the world tour!

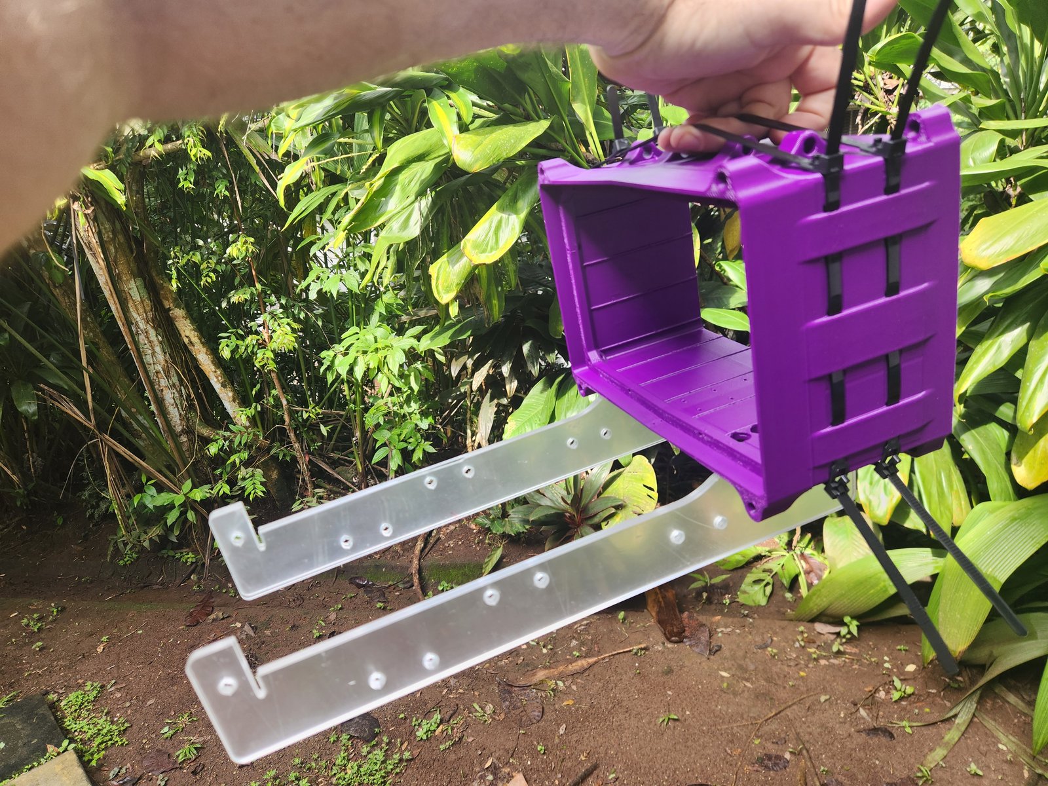
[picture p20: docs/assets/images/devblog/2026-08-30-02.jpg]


## Upcoming Events!

#### Open Source Hardware Association - Livestream! October 10

We Every year, Sid and Lee from OSHWA run a fantastic all day live stream talk show. You can see creators around the world showing their super cool projects ranging across zillions of fields (with plenty of zaniness in between)!

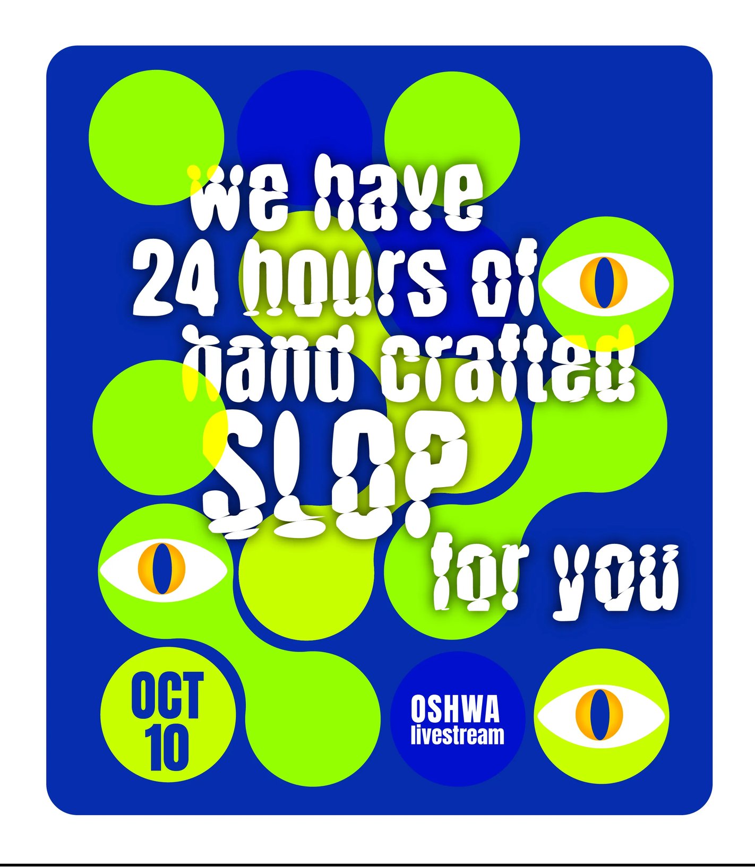
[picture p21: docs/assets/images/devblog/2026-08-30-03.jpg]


Want to show off something cool? [Sign up here!](https://docs.google.com/forms/d/e/1FAIpQLSc1tTqm2WY5aWRQi6wfXTsakWNbRJYoNpkqe5jvRB4ov9PqgQ/viewform)

## Rest in Peace - Our Pal Jimmy

Starting off with some really sad news, our dear pal, James Kionka suddenly died on August 7 in St. Louis. I had headed to St. Louis early after our Mothbox trips in NYC, Boston, and Maine after hearing Jimmy was in the hospital. My plane got delayed 12 hours though, and by the time I arrived at the hospital he had already been rushed to the ICU and I wasn’t able to see him before he passed. It was his funeral today.

Jimmy was one of my oldest buds. He was part of my high school friend crew (dubbed “the Cube”), college roommate, and generally just sweet nice guy. We used to get up to all sorts of shenanigans, and made music videos and documentaries together.

The poor guy suffered from a degenerative genetic disease which caused bone-weakening tumors to spread across his body and left him with chronic pain (incidentally we discovered the early form of this disease together when we rolled him out of an abandoned tractor tire and it broke the poor guy’s arm due to a tiny weakness caused by a nascent tumor).

He was passionate about music, computers, and social justice. Sadly, at times, some folks exploited his unending niceness and helpfulness, and this put him in hard financial positions. He also was facing the terrible current job market after being laid off numerous times in the past couple years. These factors all compounded his alcoholism which eventually took his life.

Despite all these deep problems our bud was dealing with, he was always nice and empathetic to hang around and chat with (and a happy concert buddy!).

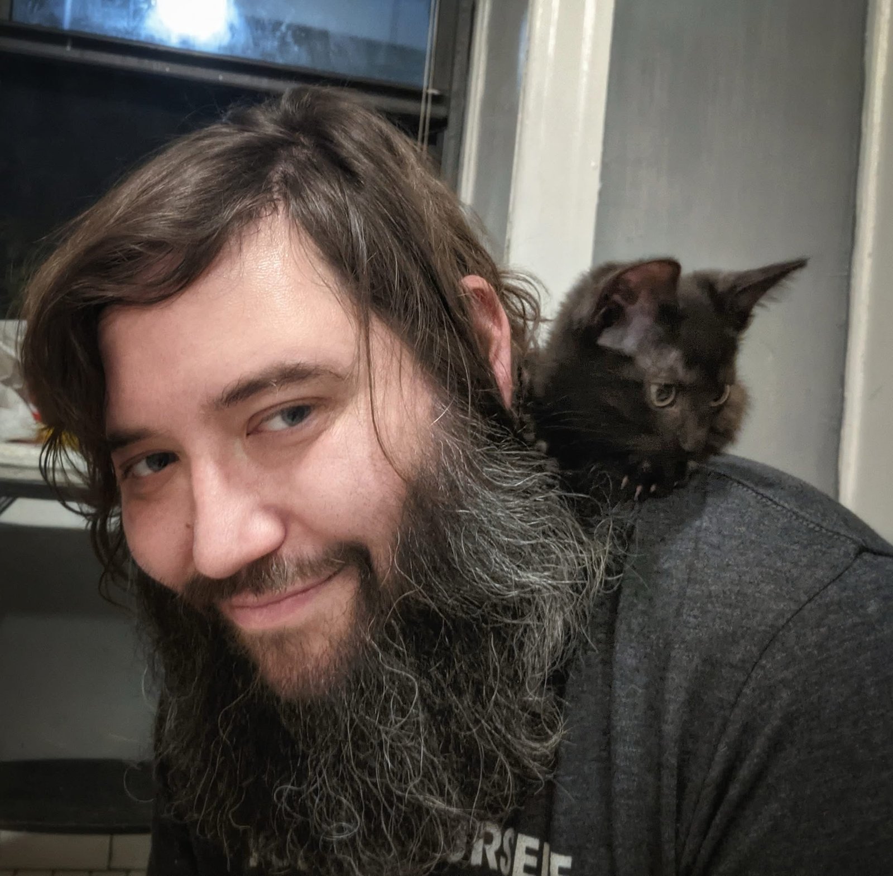
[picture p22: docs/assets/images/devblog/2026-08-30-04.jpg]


I know most folks on this mailing list never met him, but you can get a taste of hanging out with our bud in this segment of our 20-year-[old documentary we made about “Piles.”](https://www.youtube.com/watch?v=MaD9LLCJJcg&list=PLE2551E721632498F&index=2)

Also please remember that the entire world is in an incredibly tumultuous time, and it can be super difficult just to get by. Make sure to **reach out to your buds if you need help,** and **check in on your friends** to help us **get through this stuff together as best as we can.** <3

## Recap: Final Flights of the Mothbox Tour (Part 1)

**Mothapalooza**

July was Jam packed with Moth events! Mothapalooza was an incredible event. Hundreds of folks, both expert Moth-ers and complete novices joined together to celebrate these amazing creatures!

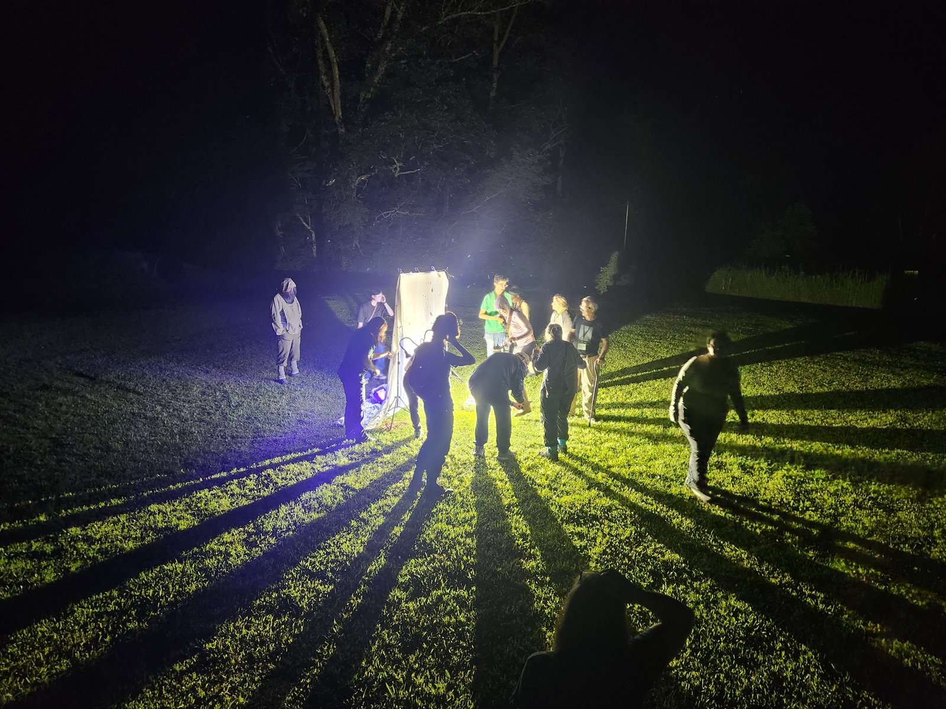
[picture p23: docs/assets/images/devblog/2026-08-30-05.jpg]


Please we finally got to meet the crew from the [Caterpillar Lab](https://www.thecaterpillarlab.org/)! (Who gave the best digitally augmented live demos I’ve ever seen!)

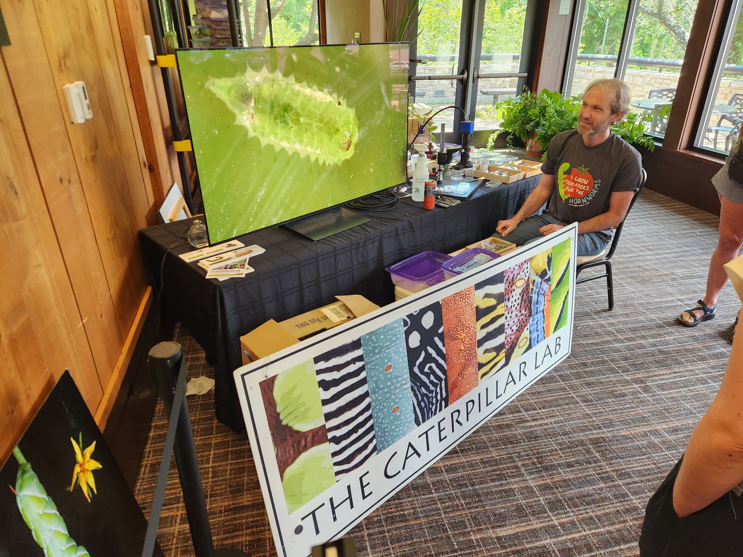
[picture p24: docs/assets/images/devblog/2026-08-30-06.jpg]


We also did a completely improvised workshop showing some folks how to build their mothboxes while upgrading Alissa Doucet (a researcher from the field museum)’s mothboxes.

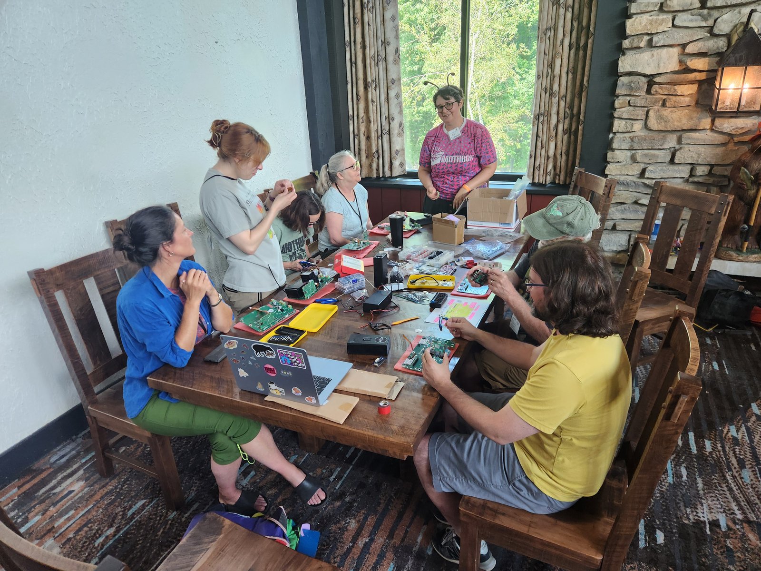
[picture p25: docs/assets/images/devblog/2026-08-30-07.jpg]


**AMNH - NYC**

After our Keynote at Mothapalooza, Bri met up with us and we helped run Mothweek celebrations with Jesse Barber and his lab at the American Museum of Natural History in New York City!

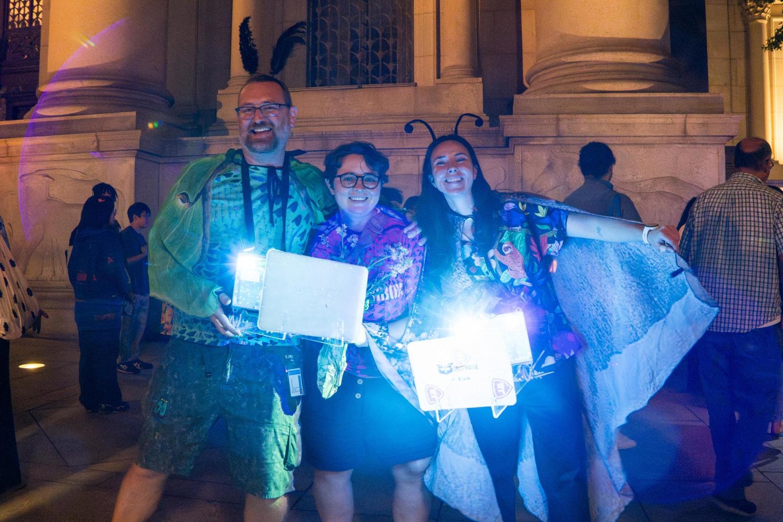
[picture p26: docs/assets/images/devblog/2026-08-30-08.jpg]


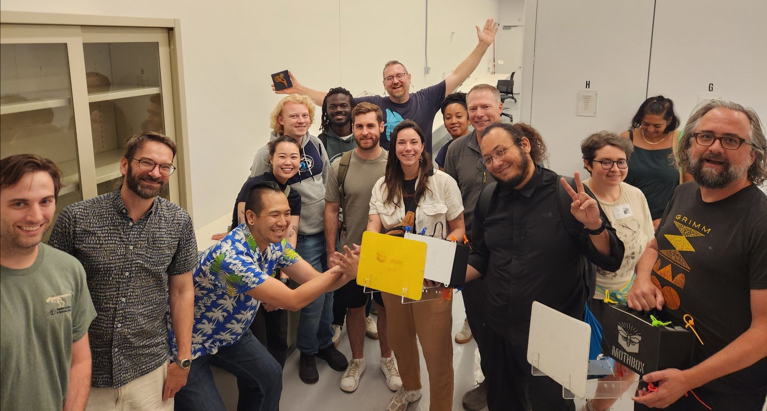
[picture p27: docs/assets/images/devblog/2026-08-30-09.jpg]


There we had several days of workshops, check out amazing behind the scenes tours, do talks, and public demonstrations! Including the dream come true: giving a big panel talk about moths under the giant whale in the hall of biodiversity!

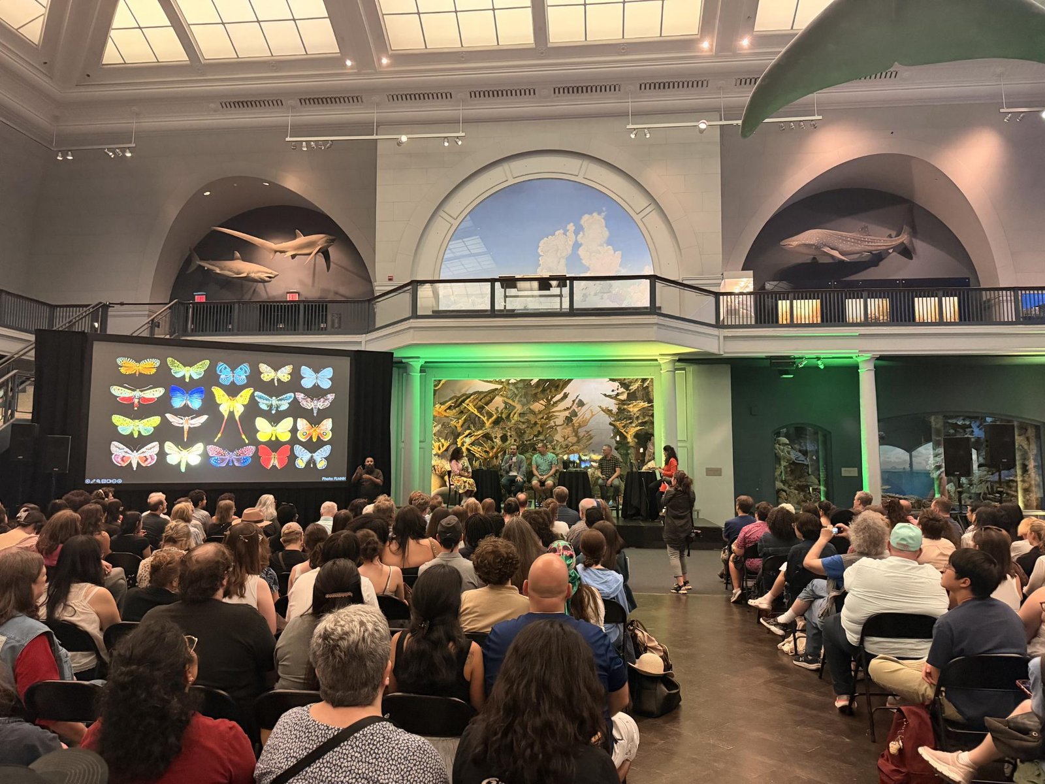
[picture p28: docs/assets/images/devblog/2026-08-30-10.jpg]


We even did an impromptu mothing trip across the street into central park after the museum closed!

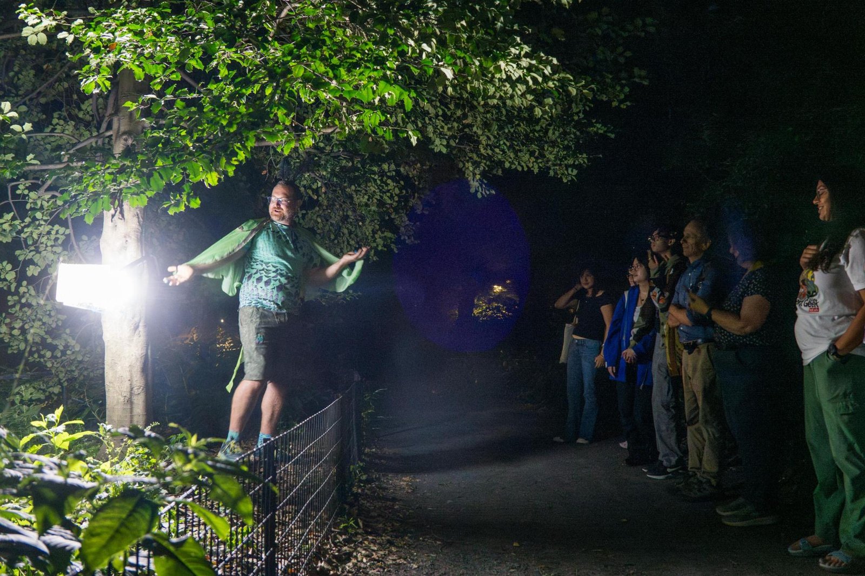
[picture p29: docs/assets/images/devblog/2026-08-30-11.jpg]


We also swung by the biohacker space, Biotech without Borders, and gave a talk to the great community there!

**Boston**

After NYC, I popped up to MIT for the FAB 26 conference (thanks to tickets and support from Nadya and a free couch to sleep on from Jessie Foley!) This hopefully led to some connections that might help with some future Mothboxing development!

Then I met with Sydne Record for a tour of the Harvard Forest and to hopefully get Mothboxes integrated at NEON sites like this in the future. BTW the site has these AMAZING dioramas detailing the stages of historical forest management there!

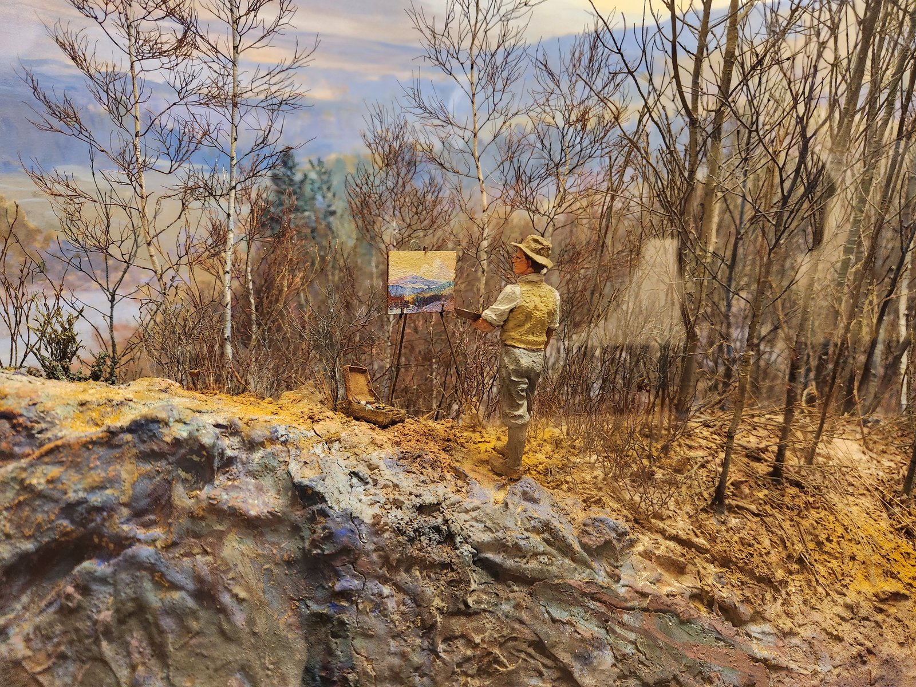
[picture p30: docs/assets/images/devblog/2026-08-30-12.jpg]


**Maine**

Then our incredibly talented friends Lee and Alex were doing a fancy residency at Haystack Mountain School of Crafts in Maine, and were kind enough to invite me to visit.

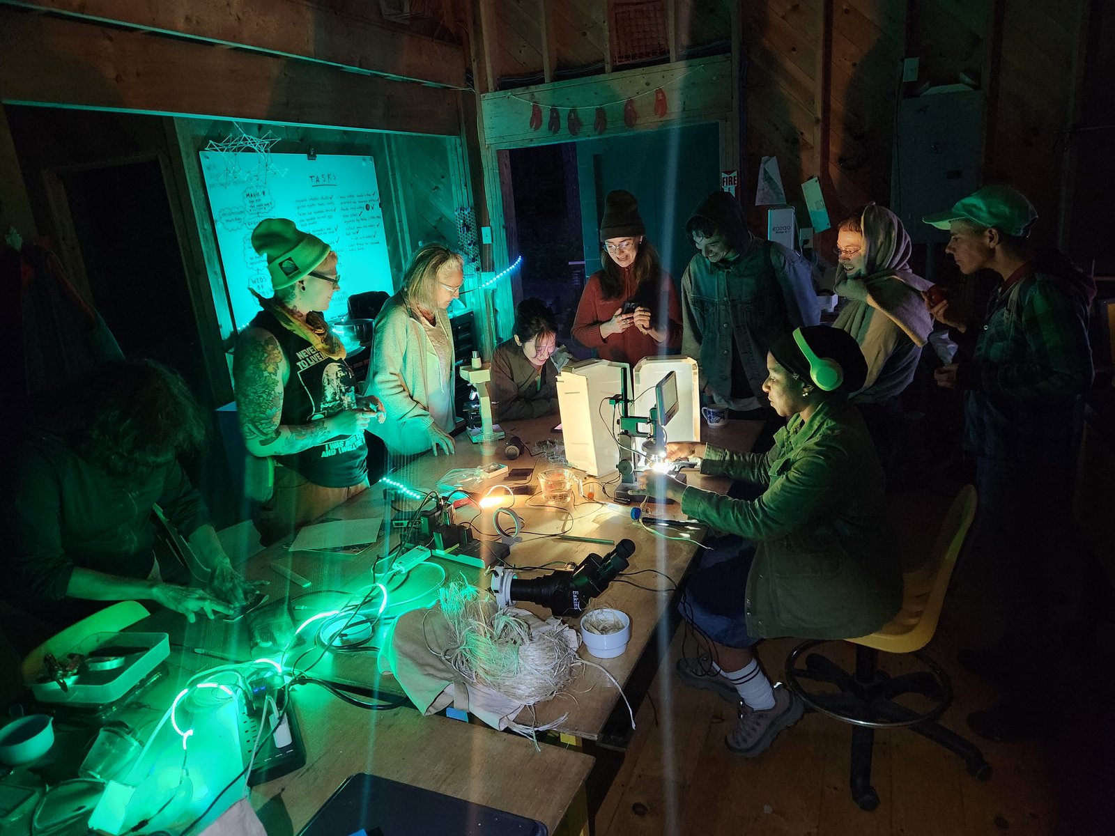
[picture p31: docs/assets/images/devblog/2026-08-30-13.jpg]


Obviously I rented a cheap bike, and rode my Mothbox 100km down there to hang with them (and their Moths).

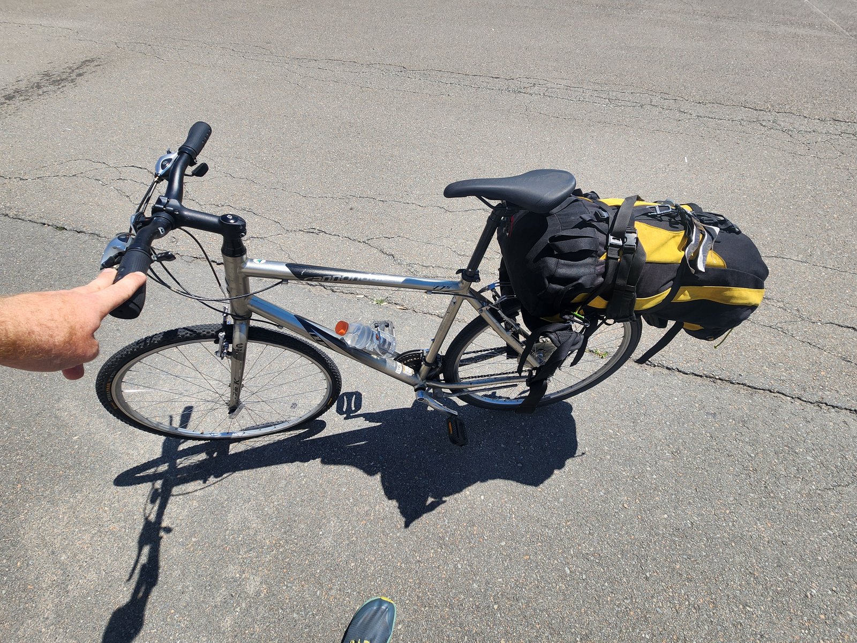
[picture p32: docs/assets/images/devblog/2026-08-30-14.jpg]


By chance the amazing artist, Eli Nixon, author/creature of the book/holiday called [“Bloodtide,”](https://the3rdthing.press/product/bloodtide-2nd-edition/) was the resident next to Lee and Alex, and we got to make them a kind of wearable projector that put them in the center of a horseshoe crab swarm!

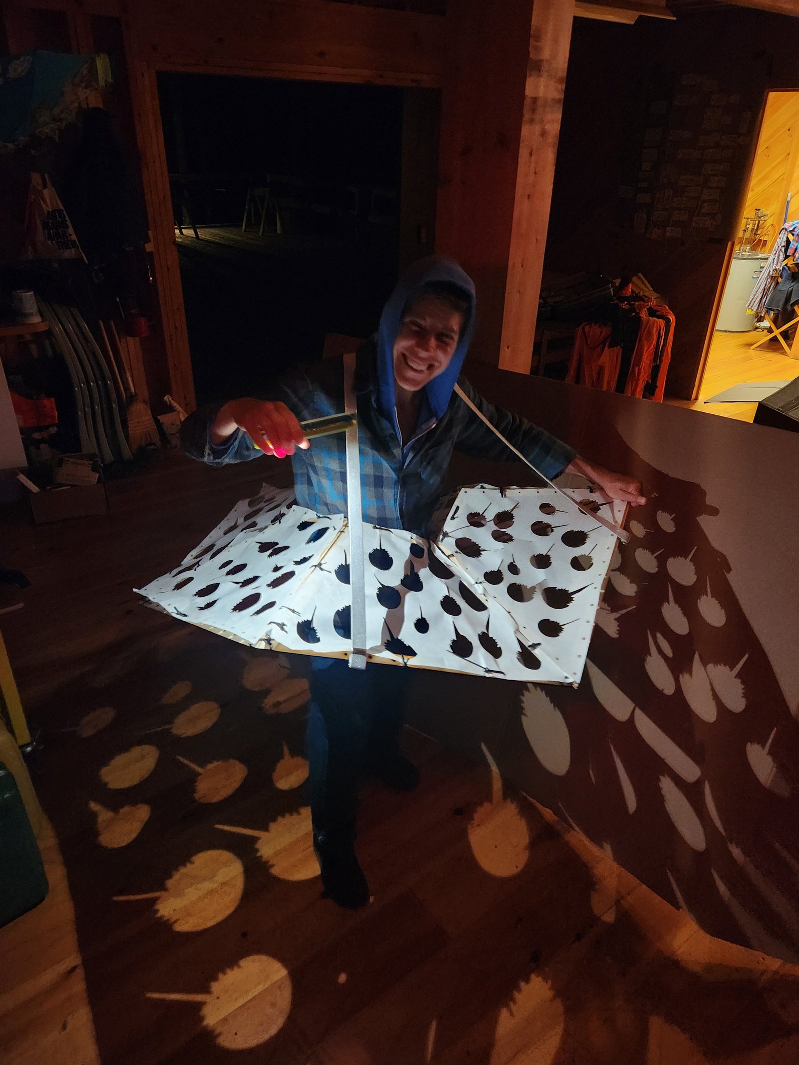
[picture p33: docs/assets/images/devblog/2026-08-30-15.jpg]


After this quick visit I had to bike back across Maine and head to St. Louis and Tucson, but those details can be shared in the **NEXT UPDATE!**

## Dinalab Team will be in Montreal!

Whoa! Did we get a job after this time looking for funding? Nope! But we got helped out by the very kind David Rolnick and the IVADO institute in Montreal who nicely invited me to be a visiting professor from October-December! We will be working with them and the Antennae crew to build an amazing insect processing software combining the powers of our existing open source softwares!

## Chat with Mothboxers!

We set up a slack-like chat room (using Element and Matrix) for people who want to discuss mothbox stuff!  Join now, it’s all super free!

Mothbox Chat <https://matrix.to/#/#mothbox:matrix.org>



## Get your own Mothbox?

Wow these Mothboxes everyone is talking about sure look fun!? If you are interested in ordering a Mothbox PCB or assembled kit, fill out our [interest form and we will do our best to try to start figuring out how to get things to you!](https://docs.google.com/forms/d/e/1FAIpQLSfi9uZ_ZCyryR8PCAIEaGi_4bSr2cWwznUFDQ-H5Bb0zSpnWg/viewform?usp=header)

### Moth Art Challenge - Finished!!

Since January we have been running a challenge for making Moth art every week! Pom and Weng are the only ones I know of who made it through the whole challenge!

And we got to celebrate their art on the big screen at the American Museum of Natural History! Make sure to check out all [Pom’s illustrations she’s been posting on her Instagram!](https://www.instagram.com/ecoartistpom/) and Weng’s on bluesky with the hashtag!

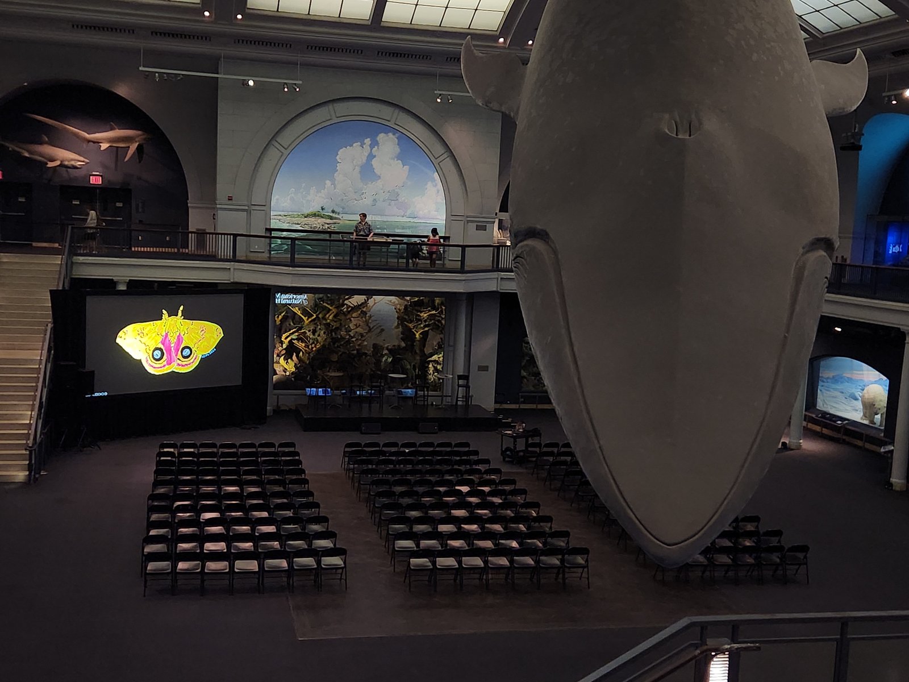
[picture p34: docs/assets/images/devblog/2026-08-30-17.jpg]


Here was the list of challenges and you can find many on social media via hashtag, "#YearOfTheMoth”

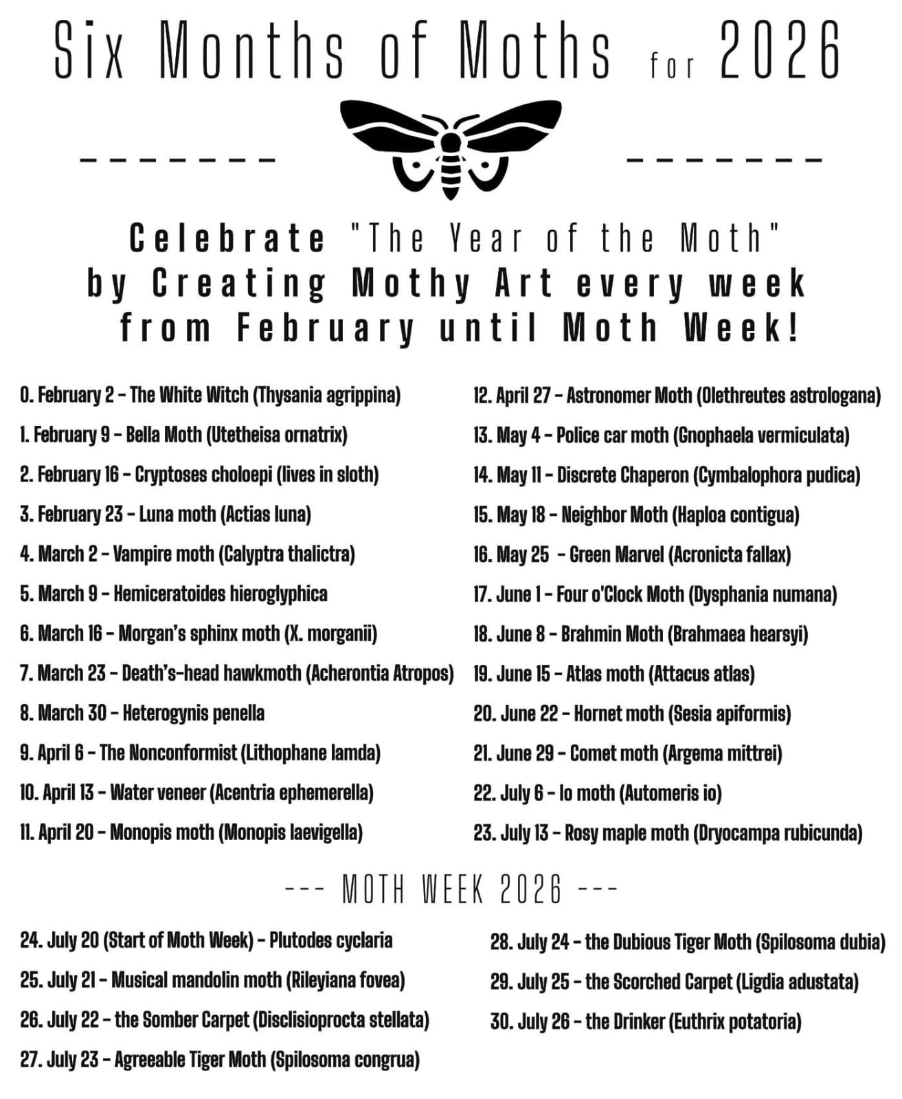
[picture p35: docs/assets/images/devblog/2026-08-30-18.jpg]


## Mothbox World Tour IS OVER!

Where all did we go? Also, wait, aren’t you all still heading to Canada?

**February**

International Conservation Technology Conference - Lima Peru

**March**

Creative Coding Barcelona - Wildhacking

**April**

Ohio - Imageomics

Seattle- Open Automation workshop

**May**

Vancouver - Juli Carillo’s lab at UBC

*Berlin - Open Hardware Summit!*

Aarhus - Mothbox Workshop

**June**

Marburg germany - Bionic Blitz

(Across Germany) Biking Blitz

Krk, Croatia - Krkreate! (Mothbox testing and training at a hacker camp!)

**July**

**Keynote: Mothapalooza - Ohio**

*NYC- Moth Week (Apply to* [*join our free mothbox workshop here*](https://docs.google.com/forms/d/e/1FAIpQLSfBH5M20AiaaFAuG__cUQ88Q6nG7Dp81lnr-w_Ys-1cC75CUg/viewform?usp=header)*)*

Boston - Fab 26 conference (maybe?)

Maine - Bike Across Maine and Visit Haystack!

St Louis

**August**

**Tucson Arizona - Keynote: Insects in Education Conference!**

**September**

Gamboa Panama - Now until September 24!

**Oct-December**

Montreal!

# 2026 - Aug - 11
**Join Mothbox Chat, Loads of Software Improvements, Integrated Visualizations, Customize Settings easier! August \[Mothbox\] Updates!** *(from our [email newsletter](https://us20.campaign-archive.com/home/?u=4c29b4f7a39e89dd012b35960&id=6caba8d984))*

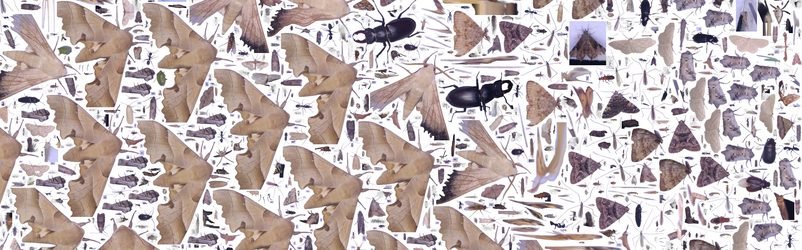
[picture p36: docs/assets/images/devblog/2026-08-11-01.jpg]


We just finished up the Northeast with the Natural History Museum, Boston and Fab 26 conference, and a bonus Mothbox bikepacking ride across Maine. Now there is just one stop left in the Mothbox World Tour! I am now heading to **Tucson to give the Keynote talk** for the [Invertebrates in Education Conference](https://titag.org/iecc-conference/).

## Chat with Mothboxers around the Globe

As this project has grown, we have had a growing need for an online space where Mothboxers can help each other out. I have been not very excited about options like Slack or Discord due to their cost/closed nature/other weirdnesses, and so instead we are trying out using Matrix

Mothbox Chat <https://matrix.to/#/#mothbox:matrix.org>



You can use it in a web browser,  or download the app "element X" to use it on a phone. It will ask you to sign up for a free matrix.org account and that's it! No fees, all open, nothing gets deleted!

## Bug Reporting

If you find errors in the hardware or software, the best place to report these is still the Mothbox Issues:

<https://github.com/Digital-Naturalism-Laboratories/Mothbox/issues>

## New Features: Firmware, Software

**Brand New: Easy Settings Editor!**

On the nice advice of our friend, Lee, I made a super simple html file that lets you edit your mothbox settings csv file a bit easier!

You can [get the file here](https://github.com/Digital-Naturalism-Laboratories/Mothbox_Firmware/blob/main/mothbox_custom_Pro/mothbox_settings_editor.html). (in future versions of the firmware it will just sit in the “mothbox_custom” folder on your Pi’s SD card).



It gives you a friendly interface that will spit out a nice new mothbox_settings.csv file you can replace the current one with on your SD card. It can also help prevent weirdnesses that may happen when you edit the csv with something like excel.

**Mothbox Process**

This is our multi-stage, locally running post processing software to turn all your raw source images from your Mothbox into automatically organized collections of critters.

I have been editing it a bunch to make it faster and more usuable:

- Manual Metadata Entry in the App
- Linux support now (I haven’t tested it yet though, someone can totally try it out)
- better documentation on mothbox.org
- I started a new branch trying to make all our libraries consolidated to the new OpenCV 5 which might hopefully make fewer weird dependencies and speed things up a bit
- Gets past built in yolo limit of 300 bugs per image
- Changes boundary conditions for detections that go off-image. Because we have oriented bounding boxes, there are sometimes insects detected where part of the detection box goes off screen. The default way that opencv handles this to make the cropped image repeats the edge pixels in a kinda weird way. I was worried this could mess with the Identification and visual clustering algorithms, so i tweaked it so that it doesn’t do that anymore! Check the examples below of before and after detections.

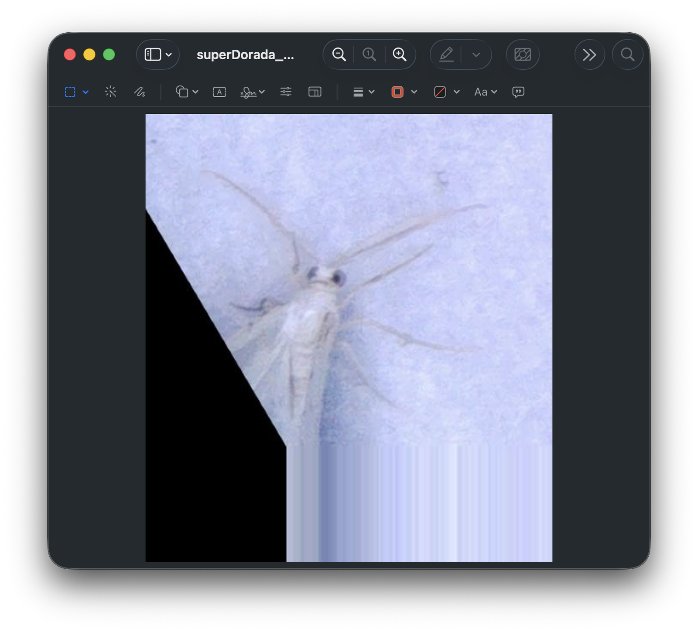
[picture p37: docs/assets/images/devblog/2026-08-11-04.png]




**Mothbox Classify**

Classify is our post-post-processing data validation software. You can use it by just going to <https://classify.mothbox.org/> (only works with Chrome or Edge currently).

- Integrated Visualization software: You can now turn your datasets of bugs into cool radial visualizations or bar charts (like those we made for our latest paper). It is very easy to use and customizable (and much speedier to process thousands of bugs than previously!)
- Improvements are folded back into the main branch on github



**Support for MASSIVE image collections**

The fires a couple weeks ago seemed to scare up a ton of little beetles in Ohio and led to our current record for most insects spotted in a single night (55,000+!). This also succeeded in breaking our Process and Classify Software! So i had to rework it all a bit to make it not crash and fail, and have systems for banking chunks of processed data being processed en masse (this was extra tricky with the clustering algorithm which compares all the images with each other in an image collection). So now both these softwares are more robust and can handle more bugs!

## Mothbox Interest? We got your message!

If you filled out our [Mothbox interest form](https://docs.google.com/forms/d/e/1FAIpQLSfi9uZ_ZCyryR8PCAIEaGi_4bSr2cWwznUFDQ-H5Bb0zSpnWg/viewform?usp=header), we want you to know that we got your message! Andy has been traveling and is out of Mothbox materials, and the open science shop crew in LA has also been low on supplies, so it might take us some time, but when we are prepped to start fulfilling some more orders, we will reach back out to you to confirm!

# 2026 - Jun - 25
**Pixel Mass Estimation, Convert Legacy dataset, Mothbeam Tweak \[Mothbox\]!** *(from our [email newsletter](https://us20.campaign-archive.com/home/?u=4c29b4f7a39e89dd012b35960&id=6caba8d984))*



Bonus updates for you all!

## Pixel Mass Estimations!

I got an itch over the weekend and worked to add a new feature in our post processing software. You can now, optionally, at the end of the processing of your data take your data through a fun process to calculate how much real-world area your insects would cover. This is apparently a heuristic some scientists can use as a proxy for biomass estimations and has been a requested feature during our travels. So I implemented it!

**How it Works**

There is an extra tab in the Mothbot Process software where you can input how many pixels/mm your image target is, and then the program will start removing the backgrounds from each detection image, and then calculate how many “insect pixels” are in this image, which can then be converted to mm2



and a helpful extra feature: pixel/mm estimation tool!

Maybe you don’t know off-hand the pixel to mm conversion of your images, well i made a built in tool to help you with that too!

The tab will auto-load one of the source images from your data, and if you click two points of a known distance (e.g. these two dots re 45mm apart), then it will compute your pix/mm for you!



Try out both tools today!

Classify can show these changes and estimates now too!



Download the latest release of Mothbot [Process](https://github.com/Digital-Naturalism-Laboratories/Mothbot_Process/releases) and [Classify](https://dev-classify.mothbox.org/)

[A](https://github.com/Digital-Naturalism-Laboratories/Mothbot_Process/releases)lso, as with all these features, everything runs on open machine learning models that can be run locally. For the background removal, you can actually choose different models depending on your speed/quality you desire. (the default runs pretty good on my old PC laptop or mac air).

**Other cool features**

I have been grinding on refining the UI and adding other features. For instance, since we changed how files are organized, i added a new feature that will detect if you have a legacy dataset style, and offer to convert it to the new style for you for viewing in mothbot Classify

## Feedback? Questions? Troubleshooting?

There’s probably still some issues that I am sure will come up, so let us know! Use the github: <https://github.com/Digital-Naturalism-Laboratories/Mothbox/issues>

This is the easiest way to get help with anything mothbox related. (And many problems can get solved by looking at questions others had too!)

## Mothbeam Correction, Simple fix, and Update!

I had a hunch and didn’t have time to verify, but the amazing Gerrit validated my hunch: The mothbeams we made since we adapted Moritz’s design seemed to have run a bit hotter and brighter than estimated.

Gerrit actually measured them and found they use more current than estimated. So not much of a problem, but we just logged the real-world current of the mothbeam versions 5.0.1-5.0.2



And then Gerrit, being a superhero, even discovered this discrepancy was because i accidently connected a part of the circuit that should not have been connected, and released a new version, **5.0.3,** which fixes this error.

Overall it’s not the biggest deal, but this fix should help the mothbeams be even more straightforward about their consumption, and potentially run more efficiently!

Gerrit also found out a simple way to convert your old mothbeams, you just need to cut this trace between these two legs of this IC circled in the pic below



Mothbeam connector!

JLC seems to have gone completely out of stock of the connector we use on the mothbeams, and searching for a replacement on their site seems to come up with nothing. But i searched other places, and then was able to find a good replacement that is hiddent on their site!

anyway, looks like this part should work just fine!

https://jlcpcb.com/parts/componentSearch?searchTxt=C46061768

# 2026 - Jun - 20
**Software and firmware overhaul for \[Mothbox\]!** *(from our [email newsletter](https://us20.campaign-archive.com/home/?u=4c29b4f7a39e89dd012b35960&id=6caba8d984))*



## Big Changes in Post Processing!

Lack of funding isn’t holding us back from rapid developments! During our meetings and workshops throughout our world tour, we collected lots of feedback and worked towards expanding compatibility of automated insect monitoring systems! This also gave us a chance to refine a lot of the aspects of our workflow.

**Mothbot Process**

[Mothbot Process](https://github.com/Digital-Naturalism-Laboratories/Mothbot_Process) went through an overhaul to run faster, be more flexible, and give users more feedback!

- BIG CHANGE: Data organization is easier to share processed data over low-bandwidth connections by splitting datasets into two, mirrored halves, a “processed” and “source” side which is also more aligned with AMI style data. Full description of the [new datastructure here](https://mothbox.org/docs/processing/process/OrganizeData/).
- More flexible matching of Metadata sheets
- exif data saves faster
- Live previews of the detection process
- 
- Batch processing of detections for computers with larger amounts of RAM

- Process indicators (showing what stages of processing each image collection has gone through

  
- More flexible image collection detection
- [Support for ISO 8601 timestamps (and several other types of timestamp)](https://github.com/Digital-Naturalism-Laboratories/mothbot-classify)

**Mothbot Classify**

[Classify,](https://github.com/Digital-Naturalism-Laboratories/mothbot-classify) our rapid data validation program, also got revamped. You can build and run it entirely locally with bun, or test out the latest dev version with all our new features at: <https://dev-classify.mothbox.org/>

- Species lists don’t need to be in a special “species” folder anymore
- Old-style datasets and new-style datasets with a separate “processed” folder are accepted
- 
- Can selectively choose which datasets in a dataset folder to set up
- can reset or refresh datasets
- 

## Firmware Updates!

**Firmware release 5.2.3!** (and version 4.18.3 coming soon! for DIY with same features).

We have made the newest firmware more reliable and even easier to use with some nice new features:

- [IS8601 Standardized date formatting on the photos. Thanks to nice suggestions from our workshops in Aarhus, the UTC offset gets baked into each photo making them more universally unique! so if your data gets mixed up, there’s better chances of nailing down where it came from!](https://drive.google.com/drive/folders/1o3aGB1MZUrNxRoGycFVw_ofUQehrjuqF?usp=sharing)
- [Camera detection - a common error some follks have when building their first mothbox is not connecting their camera correctly to the RPI. instead of failing silently, like before, your mothbox will now alert you by flashing on and off 8 times in a row! This is to prevent accidentally installing a faulty device somewhere in the field that might not be taking any photos, and to give you more confidence everything is going well when you do set it out and it gives you the cheerful double flash meaning everything is working fine!](https://academic.oup.com/icb/advance-article/doi/10.1093/icb/icag072/8700641)

**You can download the latest firmware now (for free, of course!)!**

<https://drive.google.com/drive/folders/1o3aGB1MZUrNxRoGycFVw_ofUQehrjuqF?usp=sharing>

## Another New Paper about the Mothbox?

[Yep! Hubert just got us another paper published, this time about our expedition up Cerro Hoya and doing a simultaneous insect monitoring along the cloud forest from ground to summit!](https://besjournals.onlinelibrary.wiley.com/doi/full/10.1111/2041-210x.70327)

<https://academic.oup.com/icb/advance-article/doi/10.1093/icb/icag072/8700641>



[If you are into papers, you should check out our seminal publication too!](https://besjournals.onlinelibrary.wiley.com/doi/full/10.1111/2041-210x.70327)

<https://besjournals.onlinelibrary.wiley.com/doi/full/10.1111/2041-210x.70327>

## Mothbox World Tour Continues!

The mothing has been nonstop! Our workshop in berlin culminated with the MOTHRAVE, and then we brought the devices made there to Aarhus and to use in the Bionic Blitz in Marburg. Then we carried these tools along a bike tour of the Lahn, Rhine, and Main rivers.











Where can you catch us next!? At KRKreate in Croatia headed up by Kalindi Fonda.

**February**

International Conservation Technology Conference - Lima Peru

**March**

Creative Coding Barcelona - Wildhacking

**April**

Ohio - Imageomics

Seattle- Open Automation workshop

**May**

Vancouver - Juli Carillo’s lab at UBC

*Berlin - Open Hardware Summit!*

Aarhus - Mothbox Workshop

**June**

Marburg germany - Mothbox workshop

All over Germany - Biking Blitz

KRK Creates - Croatia   *<- Up next!*

**July**

Keynote: Mothapalooza - Ohio

[NYC- Moth Week](https://github.com/Digital-Naturalism-Laboratories/Mothbox/issues)

Boston area?

**August**

Keynote: Insects in Education Conference!

## Feedback? Questions? Troubleshooting?

Use the github: <https://github.com/Digital-Naturalism-Laboratories/Mothbox/issues>

This is the easiest way to get help with anything mothbox related. (And many problems can get solved by looking at questions others had too!)

## Have you used a mothbox? Send us some data and we will train the new model to work better for you!

**Update: we are finishing ground truthing next week and will start the new model!**

If you have a mothbox, or have collected data, send us some sample files (like under 200Mb)! We are about to start training a new detection model, and the more variety we have the more robust it will be!  [Plop your data here.](https://drive.google.com/drive/folders/18PunhcrYe-diSxWev1TSVUWFHaVvr31u?usp=sharing)

Also we are making a map of where mothboxes are being used, **if you are using one somewhere on earth, please fill out this form for us!**

<https://docs.google.com/forms/d/e/1FAIpQLSd0590sVY52aRvZ-kUyF5qfg7hCWSIqP7DZExhSzD2MWOtfEA/viewform?usp=header>

## Mothboxing in Oceania? Contact Bri!

The rad mothboxin PhD student, Bri Johns, is helping coordinate getting a batch of supplies for making mothboxes to Australia and New Zealand area. If you want to get in on this with her, contact her:   briannaljohns attt  gmail        commmm

## Mothboxing in Europe? Contact Patrice!

Also if you are in europe, we will be there probably with some extra PCBs and batteries in case you need devices ASAP!

Patrice at psl3D is helping organize distribute mothboxes and kits to europe

#### contact @    psl3d  .fr

## Mothboxing Elsewhere? Fill this form!

Fill out our interest form and we will start trying to contact folks individually and help get them to you!

<https://forms.gle/BnBhjBC4csW4BwTE7>

# 2026 - May - 17
**Mothbox's First Paper! 📰🦋 + Updates from the \[mothbox\] World Tour! \[dinacon\]** *(from our [email newsletter](https://us20.campaign-archive.com/home/?u=4c29b4f7a39e89dd012b35960&id=6caba8d984))*



*(above: Kit leading a Mothbox workshop and seminar while visiting Juli Carillo’s lab at the University of British Colombia)*

## Our First Big Mothbox Paper

Hubert led our first academic paper describing the Mothbox and it just got accepted!



We targeted the journal “Methods in Ecology and Evolution” and based our paper’s structure off the seminal “Audiomoth” paper because their journey helping use open technology to open a new field in field biology has been inspirational to our work. So we are delighted that it just got accepted!

It’s open access, so read and share it here:

<https://besjournals.onlinelibrary.wiley.com/doi/full/10.1111/2041-210x.70327>

Congrats to our whole team, and we have more papers coming in the pipeline already, so keep an ear out for more!

## Mothboxing in BC

Andy and Kit made their way up the Pacific Northwest Coast to visit lovely Vancouver for the first time. We got to visit our friend, Juli Carillo’s, lab at UBC and meet all their awesome researchers! We gave a little seminar, and then Kit led a mothbox workshop while Andy helped do some consulting for Yao, a researcher studying bumblebees and helping her figure out how to build higher resolution bee monitoring devices.

The bumblebees make really neat nests reminiscent of the stingless bee colonies we have down in the tropics.



## Express Yourself Online with Moth Stickers!

In celebration of [#YearOfTheMoth](https://bsky.app/hashtag/YearOfTheMoth), the Mothbox team hired an artist in Panama, David Francesco, to create a fun sticker pack so you can more adequately express yourself online via Moths! We have sticker packs available for [Signal](https://signal.art/addstickers/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), [Telegram](https://t.me/addstickers/Mothfun2), and Whatsapp (but whatsapp is weird and we don’t know how to share them outside of the app, so you can ping my whatsapp contact +507 6116 9300, and i will send you the stickers!)



## The Replicators are Recreating Mothbox!

With Nadya Peek’s awesome Pathways to Open Source Ecosystems NSF grant, we have hired two researchers, Ali and Chris who have the really cool job of recreating and taking notes on open source science tools! Their first task was to try to recreate a mothbox without help from us! and they are doing great! (and importantly they are finding lots of little ways we can improve the build process in the future.



They are documenting their build processes all in public too! Just go to the GOSH forums and look for the “REPLICATOR” posts.

<https://forum.openhardware.science/t/replicator-team-mothbox-pro/7550/9>

Soon they will be working on recreating other science tools like the Openflexure microscope and robot pipetting devices. And IF YOU HAVE OPEN TOOLS YOU WANT RECREATED let us know!

## We Are Looking for Jobs!

We will probably send a dedicated email about this later, but we are looking for jobs to be able to keep Mothboxing! Oftentimes people see us doing all this different stuff and assume we are doing great. Well let us clear that up for you! We were super lucky to get the $160k in funding we stretched for the past two years to pay for ALL aspects of the Mothbox (hardware prototyping, field techs, travel for deployments), but ourselves have been living off only about $15k a year, which is starting to get trickier. Especially because we are planning on moving to somewhere that isn’t the USA or Panama.



We are applying for more funding all the time, but none are working out :/

Our main requirements we are looking at are finding some group that can fund us to:

- continue developing the Mothbox project
- live somewhere less isolated
- not in the USA

and if you know any leads, let us know!

## Cool Opportunities

Insect Educator Scholarship fund

Applications for the Chrysalis Fund are due June 1st! The Chrysalis Fund supports creative, hands‑on educational projects that spark curiosity about insects and other arthropods among K-12 children. [<https://www.entsoc.org/support/chrysalis-fund/apply>]

Open Source 4 Science - Science Software Fund

<https://os4science.org/funding_opportunity/os4ls/>

There are TWO jobs in Norway!

One for doing machine learning for biodiversity surveys

https://www.jobbnorge.no/en/available-jobs/job/296696/postdoc-deep-learning-for-image-based-biodiversity-surveys

One for making cool maps in Trondheim:

I don’t have a specific link, but the people putting out this job shared this info, so message me if you are interested and I will connect you!

“The university group I am affiliated with (in beautiful Trondheim) is looking for someone with a biology and coding (which includes use of AI) background to help showcase their data and models to decision makers. "Shiny colorful maps" as the director calls it. It's a long term, non-research position, start up asap (as a ~1 year temporary position which will later be advertised as a position for the years after). I think this will be a job with a lot of freedom, and the showcase focus means that it will be little software maintenance and mostly the cool part of making new stuff

:slightly_smiling_face:

 It does require being in Trondheim and is not insect- or other taxon specific. See <https://www.ntnu.edu/gjaerevoll> for general info on the Centre for Biodiversity Foresight Analysis.”

## Upcoming Events!

#### Open Hardware Summit - Berlin May 23-24

We will be exhibiting all things MOTHBOXy at the Open Hardware Summit in Berlin May 23-24

https://2026.oshwa.org/

Our workshop is already **sold out** but if you really want to join us, or get you hands on some extra mothbox supplies in berlin, MESSAGE ME!

## Mothbox World Tour Continues!

Where can you catch us?

**February**

International Conservation Technology Conference - Lima Peru

**March**

Creative Coding Barcelona - Wildhacking

**April**

Ohio - Imageomics

Seattle- Open Automation workshop

**May**

Vancouver - Juli Carillo’s lab at UBC

*Berlin - Open Hardware Summit! <- Up next!*

Aarhus - Mothbox Workshop

**June**

Marburg germany - Mothbox workshop

**July**

Keynote: Mothapalooza - Ohio

NYC- Moth Week (Apply to [join our free mothbox workshop here](https://docs.google.com/forms/d/e/1FAIpQLSfBH5M20AiaaFAuG__cUQ88Q6nG7Dp81lnr-w_Ys-1cC75CUg/viewform?usp=header))

**August**

Keynote: Insects in Education Conference!

## Get your own Mothbox?

We have 70 PCBs and 70 batteries built and shipping to different places like Panama, Seattle, and Berlin!

If you are interested in ordering a Mothbox PCB or assembled kit, fill out our [interest form and we will do our best to try to start figuring out how to get things to you!](https://docs.google.com/forms/d/e/1FAIpQLSfi9uZ_ZCyryR8PCAIEaGi_4bSr2cWwznUFDQ-H5Bb0zSpnWg/viewform?usp=header)

### Moth Art Challenge Continues!

Keep creating moth art from now until moth week in July! We might even have a little exhibition of all the moth art maybe for mothweek!

Need moth inspiration? Here’s a list of weekly challenges! Just share it online with hashtag, "#YearOfTheMoth”



# 2026 - Apr - 19
**\[Mothbox\] New firmware! Updated Post Processing! World Tour Phase 2!** *(from our [email newsletter](https://us20.campaign-archive.com/home/?u=4c29b4f7a39e89dd012b35960&id=6caba8d984))*



## Important Mothbox Unique Name Change with latest firmware!

**Firmware release 5.2.1!** (and version 4.18.1 for DIY with same features).

The latest firmware has been quite solid to use, but we found one weird bug in how we were hashing the Pi’s serial number to generate unique names for the mothboxes. We fixed that bug, and so now you are much less likely to get two mothboxes with the same name (You should now have 1 in couple million chance of getting two mothboxes both named something like “FuerteFrog”).

The only thing to note is that **your mothbox’s unique auto name will change**. So, apologies if you, like many of us, have grown attached to your mothbox’s funky name, but hopefully the new one will be fun too! You can also always just change the name yourself manually in the [Mothbox settings!](https://digital-naturalism-laboratories.github.io/Mothbox/docs/usage/initialsetup/)

You can download the latest firmware now (for free, of course!)!

<https://drive.google.com/drive/folders/1o3aGB1MZUrNxRoGycFVw_ofUQehrjuqF?usp=sharing>

## mothBOT is way easy to use now!

Our post-processing software is so much easier to use now! Instead of setting up a whole programming environment on your computer (“hacker mode”), we now have pre-compiled programs you can just [download and double click to run](https://digital-naturalism-laboratories.github.io/Mothbox/docs/processing/process)! There are currently software downloads for windows, windows with CUDA, and MacOS. (The github actions is having problems with a linux version because it’s comes out about the 2GB limit, but we can bump this in priority if it is necessary for someone)



We also worked with the cool Pybioclip team this past week, and got the bioclip updated properly to the latest version to give much speedier AND accurate performance with Bioclip 2!

## Upcoming mothBOT workshop in Serbia with Hubert!

At the InsectAI meeting in Serbia this week, Hubert will be there to show folks how he blasts through insect data with our open software!

## Peruvian Mothboxes Making strides towards a “Mothbox Station!”

Stemming from our workshop at the ICTC conference in Peru, Matt and Alejandro and the team down at Manu Biostation having been working hard to build out new features for mothboxes that will have constant power and internet access. We anticipated this need and the Mothbox Pro’s even have a dedicated switch to activate this “Hi Power mode”, we just haven’t fully built out this feature yet. But these awesome folks have been doing great work towards this!



Check it out, they are even putting the Mothboxes up in the rainforest canopy!





## Mothbox making with Imageomics!

Last week we got to go to the [Imageomics conference](https://imageomics.osu.edu/conference-main/imageomics-conference-agenda) which was a really special gathering of people doing computer vision and biological fieldwork! We gave some talks and workshops there for people to make mothboxes to sample at a nearby conservation site in Ohio (where they have a bunch of rhinos!), and to bring to the Imageomics field course in Hawaii!

They also made the most stylish mothboxes to date with gorgeous malibu pink PETG!



## Have you used a mothbox? Send us some data and we will train the new model to work better for you!

Reminder, if you have a mothbox, or have collected data, send us some sample files (like under 200Mb)! We are about to start training a new detection model, and the more variety we have the more robust it will be!

Also we are making a map of where mothboxes are being used, **if you are using one somewhere on earth, please fill out this form for us!**

<https://docs.google.com/forms/d/e/1FAIpQLSd0590sVY52aRvZ-kUyF5qfg7hCWSIqP7DZExhSzD2MWOtfEA/viewform?usp=header>

## Full Documentation on Manufacturing your own PCBs!

We are so dang open source, we don’t just provide you with designs, we will even give you an [incredibly detailed guide to](https://digital-naturalism-laboratories.github.io/Mothbox/docs/building/mothbox_pro/manufacture/) how to turn those designs into a real electronics board with big manufacturing companies! Check out the guide and make your own boards if you want!

This level of open source detail is what we strive for because we just want more tools in the hands of people who want to use them! It’s also why the [latest version of the Mothbox has even been recently certified open by the open hardware association!](https://certification.oshwa.org/pa000006.html)

## Mothbox World Tour - Pacific Northwest

We just made it to Seattle and are spreading more Mothbox love as we travel around. We sent batteries and PCBs for 70 mothboxes ahead of us here to friends houses, and will be assembling and sending these out to folks as best we can while we are out here!

This week will be be helping run the Pathways to [“Open-Source Hardware for Laboratory Automation”](https://depts.washington.edu/machines/scienceautomation/)  workshop, and I’ll be meeting with our Open Science Replicators in person who are auditing the Mothbox builds.



Then we will be visiting Eugene, OR, then Vancouver! (We have never been to Vancouver before, so if you are there, please get in touch!)

Then it’s off to Berlin next month! (to kick off the European part of the world tour!)

## Open Hardware Summit - Berlin May 23-24

We will be doing a mothbox workshop and performance at TU Berlin! On top of the Mothbox stuff you can experience there, it’s a nice conference!

Nobody is turned away from the conference for lack of funds, and there’s so much fun talks and activities and people that will be there!

<https://2026.oshwa.org/>

## Mothboxing in Oceania? Contact Bri!

The rad mothboxin PhD student, Bri Johns, is helping coordinate getting a batch of supplies for making mothboxes to Australia and New Zealand area. If you want to get in on this with her, contact her:   briannaljohns attt  gmail        commmm

## Mothboxing in Europe? Contact Patrice!

Poor Patrice and everyone at psl3D unfortunately suffered a setback where they had a massive fire at their makerspace! Luckily everyone is ok, and they seem to be back on track building cool open source parts! But make sure to understand if some things might get delayed.

Also if you are in europe, we will be there probably with some extra PCBs and batteries in case you need devices ASAP!

Patrice at psl3D is helping organize distribute mothboxes and kits to europe

#### contact @    psl3d  .fr

## Mothboxing Elsewhere? Fill this form!

Fill out our interest form and we will start trying to contact folks individually and help get them to you!

<https://forms.gle/BnBhjBC4csW4BwTE7>

# 2026 - Mar - 21
Firmware release 5.2.0!
In between Mothbox workshops, we managed to tackle some long standing features that we have wanted to implement for the Mothbox Firmware (and even [close 2 year old issues](https://github.com/Digital-Naturalism-Laboratories/Mothbox/issues/12) ).

power and memory saving features like
- Wifi only turns on in DEBUG or PARTY modes, otherwise off
- GUI only loads for DEBUG mode
 ---  !!! This means a RPI 5 2GB can work with this! (image was tested on 2GB) !!!

UI features
-Can program the pro with SWITCHES: flip switch "U1" and the device will use "Switch Priority" and physical switches will override internal schedule!
-Photo interval - you can set how often photos get taken (default every 1 min). Min 1 minute, in 1 min intervals. This is in mothbox_settings.csv

Lots of major reliability fixes
- separating user-editable controls and ones set by the system
- doing atomic writes in safer ways when writing controls for the firmware
- Checks against some race conditions
- minor bug and scope fixes

# 2026 - Feb - 07
Prepping mothboxes (both DIY and Pro) to bring to the ICTC in lima peru.
There's a ton of little fixes, and better organization, but we are really solidifying the firmware and hardware for these things.

For instance just today I caught a really secretive bug, where if there were fractional timezones (like if you were in kathmandu, UTC+5.75) the scheduler would be incorrect.
fixing this for 
5.1.1
and 4.17.1

# 2026 - Jan - 13


I have been cranking during the limbo period between years to get you a lot of cool new improvements and refinements for the Mothbox! I am very excited about these updates because they make a LOT of things a lot EASIER now. 
There's two types of Mothboxes now!
We needed a way to distinguish the design of the previous Mothbox and the current one being designed for mass manufacturing. In our notes they have been version 4 and version 5, but now they are both kind of developing on their own, and that numbering system can get confusing. So now we updated the website with two versions of the Mothbox

    Mothbox DIY - This is the version 4 mothboxes many of you have built and we have been using in the field for over  year now! It's made from off-the-shelf parts
    Mothbox Pro - This is the latest (version 5) coming soon (shown in picture at top)! It's made to be SUPER SIMPLE to put together and mass manufacturable. This is the one we are going to have pre-orders available hopefully soon with the Open Science Shop. It consists mainly of an open source, manufactured Printed Circuit Board (PCB), that connects to a raspberry pi and a battery.

3D Printed Enclosure Refinements
I have been meticulously working on the new carbon fiber PETG housings for the Mothbox Pro. I shaved 400 grams and 4 hours of print time off the current designs! I also tweaked them so they can print WITH NO SUPPORTS! Its widest dimension is also 254mm, so it should be printable on most current 3D printers available! We have tested it during the wettest of the wet season here and it stayed fine inside! There's also options to print TPU gaskets we designed to make it extra waterproof (or you can eschew these if you are in dryer regions)

Cheap and Lightweight Closures - No Bolts Needed!
In the previous Mothbox Version, everything was connectable via 1/4 (or M6) bolts. This was because they are pretty ubiquitous and reliable. But they do need two hands to close, are annoying when you drop a nut in the forest, and do add a non-trivial amount of weight and expense.


We did some field testing with Camilo and the Bat team, however, on some alternative ideas though that seem to be quite popular! The designs are still backwards compatible (you can still use bolts), but now you have 3 more options to secure your mothbox in the field!

    Lightweight re-usuable zip-ties (Cheap! Light! Some versions are a bit finicky)
    Silicone Zip Ties! (The most popular! Light, cheap! Becoming more ubiquitous! Appear a bit NSFW!)
    Our own Printable TPU Silicone Zip Ties (While you are printing stuff, you can just print these too!)

If you have deployed mothboxes in the past, I think this is one of the things that you will be excited about!

Firmware Improvements 4.16.5
I did a major overhaul of our software that actually runs on the Mothboxes! I added a bunch of features that I have been wanting to add that should make it a lot more usable! It's available here.

New Modes: your mothbox now works the way everyone seems to assume it does!
The most salient is a big change in how the MOTHBOX different modes work. 
If you used the Mothbox before, we only really had 3 main modes, Debug, Active, and Off.
People would sometimes get confused about how "Active" mode worked. Many people kept assuming it worked a certain way, and instead of fighting that, I just changed things to function that way! To prevent further confusion, instead of explaining more about how it was, I'm just going to explain the main modes available now!
 
Active: it is currently running a session. Automatic routines go. Wifi stops after 5 mins to save energy.

Standby (new!): the Mothbox is ready to go, but it's not time on the schedule yet to start running. Instead, it blinks the attractor lights twice (to let you know it is ready) and then goes into a hibernation state until the schedule says it is time to go!

Debug: When the mothbox has power, it will wake up and not shut down until manually turned off. Automatic Cron routines will not run. Lights are default off. Wifi stays on.

Party (New for MB Pro): Like debug mode, but it runs a routine to just cycle all the lights

HI Power (Coming in the future): like ACTIVE but Assumption is connected not to battery, but unlimited power supply. Wifi stays on, attempts to upload photos to internet servers automatically.

So the cool thing is that, now, while you are deploying your mothbox in the field, you can turn your battery on on your Mothbox, and it will blink a little confirmation that its ready to go when the time comes that night!
 
More Feedback
The epaper display shows not only how much storage space you have left in there, but how many photos have been taken! This can be useful if you are checking on them in the field to see, at a glance, that your device ran when it should have!
 
Better Battery Indicator for Talentcell Batteries
I have been measuring the discharge rate of the Talentcell batteries we typically use. I have tweaked the default values so that 0-100% more accurately represents how these batteries get used up. And it's WAYYY more accurate thank the quite random LEDs talentcell has on the outsides of their batteries.

Easy Customization (This is big!)
Before today, once you built your Mothbox, to get it running correctly (in somewhere that wasn't Panama), you had to follow the steps on this entire guide we made: https://digital-naturalism-laboratories.github.io/Mothbox4.5/docs/usage/configure/ (because of how raspberry pi works).
You would have to get special software, change your wifi to match the mothbox's, log into it virtually, and change some parameters (most importantly the timezone!).
But no more! We found a way to hack around that!
Now it's easy!
You just
1) flash your image onto an SD card 
2) edit some txt files on that same SD card
And that's it!


You can easily customize:

    Timezone
    Mothbox name
    camera settings
    schedule
    battery indicator voltages
    and more!

without having to SSH into your raspberry pi or any fancy stuff like that!
Display Improvements
The Epaper display has been such a handy addition to the mothbox. It really helps people in the field know what their mothbox is up to and helps assure them things are going to plan. That said, the display i made previously for it was a bare working example. I recently got roasted a bit on bluesky for the font choices of it and Kit helped me chunk the data to have a much cleaner, smoother appearance. And the folks on bluesky helped us find "hinted" open source fonts that can still display well on low resolution displays.

The open hinted fonts are "Clear Sans" and Scientifica btw.

Sign up for our Workshop in Peru! ICTC Feb 16-17
At the International Conservation and Technology Conference coming up, we will be doing a hands-on workshop with Mothboxes! You can register for it now!

Staying in Lima?
Also will you be going there? We will be staying a bit south of the venue in the gorgeous Miraflores neighborhood of Lima at a cheap hostel called the Flying Dog! Come hang with our crew there!

Pre-Pre-Order a Mothbox
In January / February we aim to start being able to take pre-orders of the Mothbox with the Openscienceshop.org network helping do distributed manufacturing around the world. To help us gauge interest for how many mothboxes people might want where (and if they want kits or fully assembled parts). There are already about 70 mothboxes on our docket to get made this year, but the interest we get will inform our strategies for getting them out to people as soon as possible!

https://docs.google.com/forms/d/e/1FAIpQLSfi9uZ_ZCyryR8PCAIEaGIi_4bSr2cWwznUFDQ-H5Bb0zSpnWg/viewform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
 
The New PCBs are (Hopefully almost ready!)
We had some awesome protoypes built in december that we have been testing out here, and they appeared to work perfectly except one minor, non-critical chip was manufactured backwards. We tweaked that design, made the board a bit thinner and lighter, and ordered what will hopefully be the last protoype before we go into bulk manufacturing! JLC had some internal delays they apologized to me for, but hopefully we will get these prototypes within a week or two (and they will just work!)!
Questions?! Use the Github!
Report problems or leave questions on the github for the mothbox to make sure we get back to you!
https://github.com/Digital-Naturalism-Laboratories/Mothbox/issues
 
The World is Pretty Rough
It's tough out there folks, and it's not easy doing ultra fast paced development on minimal budget while also trying to mentally cope and plan around horrors and fascism spreading around the world! It's depressing and terrifying! So thanks for your patience and help.  

# 2026 - Jan - 08

Just released a new version of the 4.16 firmware. It has a lot of features I have been waiting to add. Namely:

- Automatically naming the backup folder on the USB after the mothbox's name
- fixing the battery percent indicator to be a bit more accurate
- blocking mothbox cron functions at boot until the main scheduler.py has fully run (so we can do other sensing more accurately)
- moved "mode" to the controls.txt so other things can read the current mode

Big change: STANDBY mode- doesn't just turn on when you turn on the mothbox during the day

The big improvement was probably in the UI though.
We chunked the information on the epaper a lot better and are working on better fonts that are hinted for low resolution displays (thanks to some person on bluesky who was roasting me over my fonts)

# 2025 - Dec - 20
Starting to track development in this development blog

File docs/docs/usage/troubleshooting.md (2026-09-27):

---
layout: default
title: Troubleshooting
parent: Using Mothbox
has_children: true
nav_order: 9
---
Here's a guide to some basic troubleshooting if you encounter a problem using your Mothbox.

# Github Issues
One of the best ways to find answers to problems is to check out the [Github Issues page](https://github.com/Digital-Naturalism-Laboratories/Mothbox/issues). You can see common problems others may have had there, and you can post your own problem and we will help you address it!

# Firmware Troubleshooting (Mothbox's Functions being funny)
*coming soon*

# Software Troubleshooting

## It's taking my computer FOREVER to copy thousands of small files

I ran into this problem on Windows, where i was copying a 20gb dataset to an external drive, but it said it was going to take 9 days. found out a way to fix this!
Windows disables write caching on USB drives by default, which hurts small-file writes a lot. To enable it, open Device Manager → Disk drives → your destination drive → Policies → Better performance. And uncheck "Write Caching." After that, always use "Safely Remove" before unplugging.



# Hardware Troubleshooting

### How to Fix something I broke?

#### Baking Soda and Super Glue Hack
It can be helpful to keep a bit of baking soda and super glue around. The baking soda can be applied to an area, and then when touched with super glue dries almost INSTANTLY to form a hard, rock-like paste. This can be easier for field repairs as you don't need to hold it in place while it dries. 



You can also layer up layers of baking soda and super glue to build structures that connect or replace missing structures.


### Git rid of the red thing on your camera



These red things come on the camera and protect it in shipping, but also stop it from focusing properly! get rid of them!

### How can I tell the difference between a 12V and a 24V battery?

The easiest way to tell the difference is by looking at the back of the battery and see what voltage is listed under the input. The 24V one will say 29.4V and the 12V will say 12.6V.

12vMBbattexample 

*Example of a 12V battery*

24VMBbattexample

*Example of a 24V battery*

Another easy trick is that you'll notice the 12V batteries don't list the voltage on their sides, whereas the 24V one does. The 24V battery also has a little "groove" that sticks out further than the 12V one

Screenshot 2025-02-27 at 1 16 54 pm

Screenshot 2025-02-27 at 1 17 04 pm

A reminder that all 12V batteries are charged by a *black* charger, and all 24V batteries are charged by a *white* charger!
. 

### Can I charge batteries in parallel?
The short answer is: No! It's ok to keep two batteries daisy-chained together in parallel when charging *another* battery (i.e, the one in your Mothbox), but directly charging (i.e, from a wall plug) batteries in parallel can damage them. Make sure that when you are daisy chaining two or more batteries, the batteries all begin at the same charge level.

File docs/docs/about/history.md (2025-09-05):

---
layout: default
title: History
parent: About the Mothbox
has_children: false
nav_order: 2
---

From its inception, the Mothbox was (and always will be) a fully open hardware and software project that anyone is free to use and build or modify themselves. Its core development was made possible through much volunteer work by Digital Naturalism Laboratories. Its continued development has been made possible through a series of small to large grants from different organizations.

# Inspiration
Hubert's initial inspiration came from a paper by [Bjerge et al, "An Automated Light Trap
to Monitor Moths (Lepidoptera)
Using Computer Vision-Based
Tracking and Deep Learning." *Sensors*
2021](https://drive.google.com/file/d/1TweP9fMVRzXd51A6yHtfUynRnI5pbyCh/view?usp=sharing) .  We sought to make a robust DIY version that would be easy to use and function in the harsh tropics.

# V1 
*2023 Q1*

**$3,000 USD**

One of the first sponsorships this project recieved was from [Earthshot Labs](https://www.earthshot.eco/) who had briefly hired Hubert to help design a way to do multi-modal biodiversity assays of the reforestation project in the Azuero Penninsula in Panama.
They gave Dinalab ~$3000 USD to purchase parts and work on designing an automated insect monitoring system.


We made a fully functional prototype that held lots of promise (and also exposed us to the many design difficulties that would be encountered by such a project.)
This first version used a Raspberry pi, some relays, a large ring light, some $6 USB black light bars, and some tupperware.



It functioned and took high resolution photos of nocturnal insects.

# V2
*2023 Q2*

**$3,000 USD**

Despite Earthshot labs going defunct in early 2023, the success of our first prototype drew the attention of Phoebe Zarnetske's group from Michigan State University. They were working on automated devices for insect monitoring for the Xprize competition in Singapore, 2023. They hired dinalab again for about 3K to purchase parts and design a new version that was meant to be deployed by a drone. This meant we had to design the project to be much much more compact and durable.

It featured a clear box design with as many internally shielded parts as possible along with a backlit board.



It allowed us to test out a variety of UV attracting Lights and ways of lighting the subjects.


It also started showing us just some of the power of this device, when, on one of our deployments in Azuero, it attracted a praying mantis that scientists on iNaturalist noted is an undescribed species!




# V3
*2023 Q3-4*

**$16,000 USD**

In late 2023 we recieved an Experiment.com micro-grant for 10K for continued development of the mothbox with Moth researcher Yash Sondhi. This money was put towards the development of a more robust version of the mothbox. Dr. Daisy Dent also contributed 6k of her lab money to sponsor more development and testing of the Mothbox.

Mothbox on BCI, Panama

The v3 featured more refined lazer cut components that could be quickly assembled and dissasembled in the field. It used a Pi4 and Pijuice for scheduling its power.
PXL_20240308_033243240 NIGHT

# V4
*2024 Q1 -2025 Q1*

**$80,000 USD** + Fulbright Student

We began deploying v3 Mothboxes in western panama in conjunction with Hubert's biodiversity reserach with Pro-eco azuero and Ponterra. We also applied to and won the top tier of the Wildlab's 2024 grants. This gave us 60K to develop, test and document the mothbox to take the project to the next level in global use as a ubiquitous tool. Daisy Dent also contributed another 10k from her lab's funds to help further develop the Mothbox's hardware and software. Ponterra, a reforestation company also contributed 4k for further mothbox development.

Bri Johns, Dinalab's visiting Fulbright researcher is also joining the project to help facilitate the V4 development of the Mothbox by also leading community workshops in Panama to train folks on its use and development. Yash Sondhi of the Sponberg Lab at Georgia Tech also paid for workshops with scientists at Georgia Tech to build an armada of mothboxes to deploy in other locations.

The v4 has many features that improved upon previous versiions such as
* works with Pi 5 without a pijuice (or backwards compatible with a Pijuice and Pi4 combination)
* works with Hawkeye 64mp cameras or newer Owlsight cameras
* Automatically generates unique, human readable names for each Mothbox in English, Spanish, or Spanglish combinations
* Parts costs has been reduced by over 30%
* 60% less custom materials to produce in its design
* tougher parts, and fewer breakable parts
* much quicker construction (1-2 hours)
* Easier to carry
* Lighter weight
* clearer documentation
* Improved power management in the software
* Ability to function as its own hotspot for debugging
* Refined options for UV attractants (Mothbeam, external or internal attractors)

PXL_20240806_222621232 MP-EDIT

# V5
*2025 Q2 -2026 Q2*

**$106,000 USD** + 3.5 years PhD Student

The target of the v5 mothbox is to make a mass-manufacturable version of the device. We managed to win the Wildlabs award for the second year in a row! This gave us $50k to do rapid prototyping to design a Mothbox PCB that can be readily made by manufacturers around the world! Jesse Barber from the American Musuem of Natural History also supported the project with 20k to help do workshops and training in US national parks as well as the Museum in NYC. We also receieved a grant for $36K from the Gathering for Open Science Hardware. In addition to this, Bri Johns got funding to start an entire PhD on the Mothbox at Monash University in Melbourne, Australia!

Key v5 features:
* Minimal parts needed to order (just PCB, Pi, Camera, Battery, Box)
* Rapid build time! Can assemble electronics in 20 minutes
* Reduced cost. Integration of many parts into PCB shaves lots of money off the parts cost.


# Mothbeam
The Mothbeam is an open-source ultra-low cost Lepiled alternative. It developed in parallel with the Mothbox after Led Designer, Mortiz Buttlar, heard of the Mothbox and offered to contribute his expertise. He developed an ultra low cost set of modular PCBs that could be waterproofed and cooled when manufactured with low cost methods. It's not a partially standalone project as well as integrated into the Mothbox as a UV attractor.

* [Moritz Buttlar Lablab](https://lablab.eu/)

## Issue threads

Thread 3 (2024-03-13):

battery can pop out when shaken around a lot!

quitmeyer, 2024-03-13:
opened a discussion here
https://github.com/PiSupply/PiJuice/discussions/1070

quitmeyer, 2024-03-17:
This was extra proven on a drive up to totumas, everything popped out. Shoved a hunk of rubber in there

quitmeyer, 2024-06-28:
jammed rubber in pijuices, and made version that doesn't need pijuice

Closed 2024-06-28.

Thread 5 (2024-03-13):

External USB cord is not really Waterproof

quitmeyer, 2024-03-13:
Yeah it's just kinda raw and exposed isn't it. Gonna try to get some waterproof connectors and test em out!

Maybe we should get little waterproof silicone plugs for holes too?

quitmeyer, 2024-06-28:
v4 moves stuff more internal with a better charging outlet

Closed 2024-06-28.

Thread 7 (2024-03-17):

Arms can crack if smashed around a bit in the back of a pickup truck

quitmeyer, 2024-03-17:
arms are a bit fragile. especially at right angles

quitmeyer, 2024-06-28:
v4 had better arm attachements, less fragile stuff outside, redundant arms

Closed 2024-06-28.

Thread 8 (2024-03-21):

Buck converter possibly burnt out?

quitmeyer, 2024-03-21:
seems like with an older mothbox that had flash and UV power going through the buck converter it may have been too much and it blew it out. Mothbox kept running in the dark though!

quitmeyer, 2024-06-28:
it was

Closed 2024-06-28.

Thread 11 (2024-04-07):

HDR exposure range needs to be narrowed down

Hubertszcz, 2024-04-07:
The 3rd photo of every set (underexposed) is way too underexposed - none of the insects are usably exposed.
The 2nd photo of every set appears too overexposed - insects have indistinct edges because they're overpowered by the brightness of the sheet. This one I'm less sure about - maybe a large dark moth would need this level of exposure.

quitmeyer, 2024-04-07:
In the camera settings csv you can adjust the hdr width parameter

https://github.com/Digital-Naturalism-Laboratories/Mothbox/blob/main/Software/camera_settings.csv

Hubertszcz, 2024-04-07:
Are the times in the schedule app true times on-location, or are the UTC times?

If I want 7:30pm Panama, do I schedule 12:30?

quitmeyer, 2024-04-07:
You put in the location and the gmt offset

Its default is -5 for Panama.

All the metadata and name of the photos has always been in Panama time for
me.

If it isn't starting up at the correct times, it maybe lost the power to
the pijuice battery? Which would lose the rtc clock

But if it is running at the correct times, it should be listing the correct
times on the files. Some computers might originally read file date metadata
as a weird offset, but eventually figures itself out

Odd if the files are way off

On Sat, Apr 6, 2024, 10:46 PM Hubert Szczygiel ***@***.***>
wrote:

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

Closed 2024-06-28.

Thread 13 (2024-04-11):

New USB sticks not being backed up to - Phantom USB sticks still mounted

quitmeyer, 2024-04-11:
We found an interesting bug where she switched USB sticks and RPI continued thinking that the old USB stick was still in, and it went happily backing up to a non-existant USB stick (luckily it saves the backup on the rpi disk as well, so all the data was fine)

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

some research:

    Mount Point Persistence: Raspberry Pi by default uses automounting features that  mount the USB drive to a designated location (usually /media/pi/<drive_label>). Even after physically removing the drive, the mount point directory remains. When you connect a new USB drive, it might not get assigned the same label, leading to the old drive appearing mounted (although there would be no data accessible).

    UUID vs Label-Based Mounting: By default, Raspberry Pi might use the drive label for automounting.  If both USB drives have the same label, the system gets confused and continues referencing the old drive information.

Here's how to fix it:

    Verify Mount Status: Use the df command to see if the drive is truly mounted. If it lists the old drive but with 0 bytes used, it's just the mount point remaining.

    Unmount Manually: If the old drive shows mounted with used space, use the umount command with the mount point path (e.g., umount /media/pi/<old_label>) to unmount it properly.

    Identify Drives by UUID: A more reliable method is to configure automounting based on the Unique Disk Identifier (UUID) of each drive. This ensures the system recognizes them distinctly. You can find the UUID using the lsblk command and look for the UUID field under the /dev/disk/by-uuid directory.

quitmeyer, 2024-06-28:
deleted those secret mount points and saved a lot of data on the images!

Closed 2024-06-28.

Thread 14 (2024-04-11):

RTC clock is randomly off

quitmeyer, 2024-04-11:
Hubert's clock was randomly off and starts to run sometime after midnight. very odd. not sure if we will ever solve this mystery

quitmeyer, 2024-08-29:
I think the answer was that it was a poorly charged battery

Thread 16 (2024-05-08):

Mothbox 04 's LEDs output doesn't work

quitmeyer, 2024-05-08:
Maybe something with the USB output?

quitmeyer, 2024-08-29:
yeah the USB melted

Closed 2024-08-29.

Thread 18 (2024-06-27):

If there is a huge amount of photos stored locally it can jam the pi

quitmeyer, 2024-06-27:
Because of the way the backupper script works, if too many files build up internally it can jam up the internal works and crash everything

for instance if you have 20 GB of files and only 18 GB free on the pi, and it tries to make a local backup it stalls

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

quitmeyer, 2024-06-28:
fixed with latest backup files script

Closed 2024-06-28.

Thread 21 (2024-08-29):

Winged hapuku camera and power

quitmeyer, 2024-08-29:
wasn;'t working

camera wasn't plugged in, and USB cable was crappy

quitmeyer, 2024-08-29:
solved it

Closed 2024-08-29.

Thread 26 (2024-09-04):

Liftalce's light is constantly on draining the battery

quitmeyer, 2024-09-04:
It is still taking photos and everything, but the ring lights are always on and it's starting to burn out some LEDs on the ringlight. hopefully this isn't an issue with a direct to regulator setup

quitmeyer, 2024-09-04:
Weird software error! Electronics were fine, but for some reason the controls.txt file was empty! Fixed the controls file and it started working again!

quitmeyer, 2024-09-04:
need to check if this is a Scheduler.py problem?

quitmeyer, 2024-09-04:
Nope seems like the controls file just got deleted on accident

Closed 2024-09-04.

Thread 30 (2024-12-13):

[FEATURE] Power consumption estimates

mihow, 2024-12-13:
Do you have a breakdown of the power consumption for the recommended components?

The [docs suggest ](https://digital-naturalism-laboratories.github.io/Mothbox/docs/building/powersources/) that the 38,400mAh Talentcell battery (PB120B1) should be able to power the Mothbox for 22 hours (4 nights at 5.5hrs each)

Is that with the Mothbeam light? And 2 photo ring lights firing intermittently?

If you have a table of values you use to estimate the battery size that would be fantastic!

Here are my estimates so far just from googling
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

Thanks for all your great research and effort devoted to this project!

quitmeyer, 2024-12-17:
cool, we have some in the background ill put up on the documentation shortly.  We didn't actually calculate the 22 hours, that's from just running many of them over and over again with a previous mothbeam (mothbeam v1) hooked up. We have a newer mothbeam now that's quite a bit brighter on the UV pcb, but also uses about twice as much juice. So the current runtime with mothbeam v2 is about 12-13 hours.

The amp-hour estimate (38400mAh) on the PB120b1 seems off or i don't understand something. but their watt hours seems to agree with my reality ( 142.08Wh ):

here's a quick rundown of the different power states. These come from some measurements hooked up to the 12V battery:

**1.  during off state (when everything is pretty much completely off)**
~1ma = .012 watts

Normal pi5 shutdown mode is like 1.3 watts
But we shift ours for ultra standby which is only like .05 watts (which i guess at 5v would still be 1ma)

**2.  when the attractors are on**
each mothbeam seems to take like 300ma  = 4 watts
so like
8 watts for our standard config with a UV and Visible mothbeam

plus the pi is generally idle except for the like couple seconds it is taking a photo. During idle time it seems to consume about 2.4 watts (wifi and bluetooth and stuff are shut off). When taking a photo this can jump up briefly, but like super short.

but the power consumption around this time seems to be around
10.4 watts total

for the ideal PB120b1 at 142 watt hours, that suggests this would run for 13.65 hours (which seems to agree with our latest testing of the more power hungry v2 mothbeams)

the reality is more like 12-13 hours, so i attribute that extra power loss to the ring flashes and non-ideal battery world.

3-  when it is taking pictures and the flash is on as well.**
The photo taking takes less than half a second usually and doesn't seem to significantly impact the overall battery life as much as the other stuff (like 45 minutes less out of 13 hours predicted, or about 6% energy loss)

ToonVanEyck, 2025-06-05:
I saw you are connecting all your power LED's in parallel.

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
If you instead create 5 parallel branches of 2 series LED's with a resistor, you could lower the amount of power a bit. You are wasting a lot of power in the resistors at the moment.

quitmeyer, 2025-06-05:
wonderful!

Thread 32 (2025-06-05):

Pullup Rs on dip-switches

biomurph, 2025-06-05:
Question about using pullup resistors on the dip switch UI.
Those switches go to multiplexers, and the multiplexers are 'break-before-make', which makes one think that the pullups are not necessary. Also, given the enable pins on the muxers, they can be turned 'off' to break the connection from the Mux pins to the I/O common pin.

However, the dip switches are either open or closed. See the "Schematics" on the dip switch datasheet
https://www.lcsc.com/datasheet/lcsc_datasheet_2409272202_SM-Switch-SMXS-08K-TP_C5439767.pdf
Given the dip switch circuit, you need the pullups, for sure. Otherwise, shorty will get ya!

If you're concerned about routing issues and board space, take a look at a resistor array like this one
https://eu.mouser.com/ProductDetail/Panasonic/EXB-2HV103JV?qs=oE3VwAv%2FYtnxG1PkyhflFQ%3D%3D

biomurph, 2025-06-05:
The dip switch makes connection or disconnection between its pins. Without the pullups, closing the dip switch would short 5v to GND!

quitmeyer, 2025-06-05:
but the dip switch won't connect to 5V! it will connect GND to the GPIO pin. The GPIO pin will be set by software to have an internal pullup. So when the switch is OPEN the GPIO pin will read HI, and when the switch connects to GND the GPIO pin will read LOW (i think)

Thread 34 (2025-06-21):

Power Trace Vias Are Too Small

biomurph, 2025-06-21:
**Describe the bug**
You’re power trace vias on the UV and LED blasters are too small, I think.
Have you calculated currents?

Here’s a link to understanding more
https://www.pcbrunner.com/optimising-your-pcb-design-for-via-current-handling-a-simple-guide/

quitmeyer, 2025-06-21:
Oh wow that's so interesting! I hadn't even thought about the limitations
of the vias!

__

Sincerely,
Dr. Andrew James Quitmeyer
Director of Digital Naturalism Laboratories
Affiliate Professor, University of Washington - Human Centered Design and
Engineering
www.dinalab.net

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

parkview, 2025-07-15:
in PCB v5.0.1 I kept the via's the same diameter, but added multiple via's.

Closed 2025-07-15.

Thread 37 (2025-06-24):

U3.6 Pin Connection

biomurph, 2025-06-24:
The 5V regulator U3 pin 6 (package tab) needs to be connected to SW

That will help dissipate heat to the board and not stress the SW pin 3

parkview, 2025-07-15:
This has been fixed in v5.0.1 PCB

Closed 2025-07-15.

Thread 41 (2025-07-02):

mothbox 5.0 pcb ina doesn't work

quitmeyer, 2025-07-02:
I should have grounded a0 and a1, but i didn't! and floating they don't work

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

however, even when i manually ground, they still give an error "no i2c device found at 0x40" which is where it should be

maybe it's that backward capacitor?

quitmeyer, 2025-07-04:
got a differnt library (ina219) and grounded the two wires and now we can read voltage (current still seems off)

Closed 2025-07-04.

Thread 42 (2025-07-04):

5.0.0 pcb UV2 and UV3 not connected

quitmeyer, 2025-07-04:
Andy forgot to tie the UV2 and UV3 to UV1 to make all turn on, he left them disconnected and UV2 and 3 don't turn on

parkview, 2025-07-15:
Fixed on the v5.0.1 PCB

Closed 2025-07-15.

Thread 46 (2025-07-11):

5.0.0 Increase front LEDS to physically brighter and larger

quitmeyer, 2025-07-11:
**Describe the bug**
A clear and concise description of what the bug is.

**To Reproduce**
Steps to reproduce the behavior:

**Expected behavior**
A clear and concise description of what you expected to happen.

**Additional context**
Add any other context about the problem here.

parkview, 2025-07-15:
The old LEDs have been replaced with ones that (in theory) are twice as bright, but they draw twice the current.  They need testing.

Closed 2025-07-15.

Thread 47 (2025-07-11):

5.0.0 Add vertical external wire connectors go vertical and snap in instead of the current ones

quitmeyer, 2025-07-11:

parkview, 2025-07-15:
Fixed on the v5.0.1 PCB

Closed 2025-07-15.

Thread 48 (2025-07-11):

[FEATURE] Maybe have full 24 hours represented by dip switches? 5.0.0

quitmeyer, 2025-07-11:
**Is your feature request related to a problem? Please describe.**
A clear and concise description of what the problem is. Ex. I'm always frustrated when [...]

**Describe the solution you'd like**
A clear and concise description of what you want to happen.

**Additional context**
Add any other context or screenshots about the feature request here.

parkview, 2025-07-15:
Andy, what labels do you want on the DIP switches?

quitmeyer, 2025-08-05:
@parkview already did this! nice

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

Closed 2025-08-05.

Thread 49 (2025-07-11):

[FEATURE] Maybe have full 24 hours represented by dip switches? 5.0.0

quitmeyer, 2025-07-11:
**Is your feature request related to a problem? Please describe.**
A clear and concise description of what the problem is. Ex. I'm always frustrated when [...]

**Describe the solution you'd like**
A clear and concise description of what you want to happen.

**Additional context**
Add any other context or screenshots about the feature request here.

parkview, 2025-07-15:
Duplicate of #48

Closed 2025-07-15.

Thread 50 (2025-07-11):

[FEATURE] Flip E-Ink display To front of PCB

quitmeyer, 2025-07-11:

quitmeyer, 2025-08-05:
@parkview already did this in the latest PCB

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

Closed 2025-08-05.

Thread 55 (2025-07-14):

Add a requirements.txt file

arky, 2025-07-14:
Create a `requirements.txt` to install all the processing tools instead of install individual python packages.

```

Linux or Mac

On Mac and Linux you just open a “Terminal,” and then you can run adminstrator level commands by just using the word “sudo” in front of each command you give.
Commands

Now you can type in these commands and hit enter after each one!

sudo pip install pybioclip

sudo pip install unidecode

sudo pip install pandas

sudo pip install pillow

sudo pip install numpy

sudo pip install ultralytics

(Ultralytics is a big one that might take a while to install.)

sudo pip install opencv-python

```

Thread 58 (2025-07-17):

Metadata generation in most recent release?

chevalierid, 2025-07-17:
**Describe the bug**
The "create your own metadata" link in the [metadata](https://digital-naturalism-laboratories.github.io/Mothbox/docs/processing/OrganizeData/#metadata) section of the documentation is broken. I would guess it pointed to the metadata generation script (Mothbot_GenMetadata.py) that is now in the "old" folder. Is this script deprecated? If so, is there a new way to generate the JSON files needed for the next steps?

**To Reproduce**
Click the hyperlinked text "create your own metadata" in the [metadata](https://digital-naturalism-laboratories.github.io/Mothbox/docs/processing/OrganizeData/#metadata) section of the documentation.

Alternatively, try to run Mothbot_CreateDataset.py after changing the file paths to match your use case.

**Expected behavior**
404 Not Found appears.

Alternatively, Mothbot_CreateDataset.py will fail to find any samples because it cannot find any sets of three similarly-named grouped files (one JPG, two JSON).

Hope this is OK to post as an issue. Would appreciate any help you can provide!

quitmeyer, 2025-07-29:
Thanks for posting the issue!
The gen metadata script was part of an outdated workflow.

If you can let me know what you are trying to do, i can give tips :)

I'm just getting back from running a bit conference and catching up on
things

__

Sincerely,
Dr. Andrew James Quitmeyer
Director of Digital Naturalism Laboratories
Affiliate Professor, University of Washington - Human Centered Design and
Engineering
www.dinalab.net

On Wed, Jul 16, 2025, 22:06 Daphne Chevalier ***@***.***>
wrote:

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

quitmeyer, 2025-08-05:
Ahhh ok @chevalierid , now that I am back at a proper computer, i think i understand your problem!

The link to the metadata form was just broken.

For your metadata, log your metadata in a spreadsheet like this:
https://docs.google.com/spreadsheets/d/1oN4-wttu4Gz7V0yauhQZgHVQOLTyO0c6XzUNWczOqeI/edit?usp=sharing

and then point your script to this CSV :)

I will update the website with a proper link too!

quitmeyer, 2025-08-06:
This example of a CSV works good too

https://github.com/Digital-Naturalism-Laboratories/Mothbox/blob/main/AI/Auto%20Calculations%20-%20Mothbox%20Main%20Metadata%20field%20sheet%20(Bilingue)%20(Responses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

Closed 2025-08-05.

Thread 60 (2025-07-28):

convert to csv not working

Hubertszcz, 2025-07-28:
Running the Mothbot_ConvertDatasettoCSV script gives the following error:

Found fiftyone dataset's json path
['', '', '', '', '', '', '']No valid deepest rank and value found. Probably ID'ed as an Error category, don't worry
['', '', '', '', '', '', '']No valid deepest rank and value found. Probably ID'ed as an Error category, don't worry
['', '', '', '', '', '', '']No valid deepest rank and value found. Probably ID'ed as an Error category, don't worry
['', '', '', '', '', '', '']No valid deepest rank and value found. Probably ID'ed as an Error category, don't worry
['', '', '', '', '', '', '']No valid deepest rank and value found. Probably ID'ed as an Error category, don't worry
Traceback (most recent call last):
  File "C:\Users\Hubert\AppData\Local\Programs\Python\Python311\Lib\site-packages\pandas\core\indexes\base.py", line 3805, in get_loc
    return self._engine.get_loc(casted_key)
           ^^^^^^^^^^^^^^^^^^^^^^^^^^^^^^^^
  File "index.pyx", line 167, in pandas._libs.index.IndexEngine.get_loc
  File "index.pyx", line 196, in pandas._libs.index.IndexEngine.get_loc
  File "pandas\\_libs\\hashtable_class_helper.pxi", line 7081, in pandas._libs.hashtable.PyObjectHashTable.get_item
  File "pandas\\_libs\\hashtable_class_helper.pxi", line 7089, in pandas._libs.hashtable.PyObjectHashTable.get_item
KeyError: 'taxonRank'

The above exception was the direct cause of the following exception:

Traceback (most recent call last):
  File "c:\Users\Hubert\Desktop\Biodiversity Monitoring\MothBox\Mothbox Github\Mothbox\AI\Mothbot_ConvertDatasettoCSV.py", line 359, in <module>
    json_to_csv(INPUT_PATH, UTC_OFFSET, TAXA_LIST_PATH)
  File "c:\Users\Hubert\Desktop\Biodiversity Monitoring\MothBox\Mothbox Github\Mothbox\AI\Mothbot_ConvertDatasettoCSV.py", line 295, in json_to_csv
    taxon_id, scientificName= find_deepest_taxon_info(TAXA, taxa_values, taxa_lookup)
                              ^^^^^^^^^^^^^^^^^^^^^^^^^^^^^^^^^^^^^^^^^^^^^^^^^^^^^^^
  File "c:\Users\Hubert\Desktop\Biodiversity Monitoring\MothBox\Mothbox Github\Mothbox\AI\Mothbot_ConvertDatasettoCSV.py", line 150, in find_deepest_taxon_info
    filtered_rows = taxa_lookup[taxa_lookup['taxonRank'].str.lower() == deepest_rank.lower()]
                                ~~~~~~~~~~~^^^^^^^^^^^^^
  File "C:\Users\Hubert\AppData\Local\Programs\Python\Python311\Lib\site-packages\pandas\core\frame.py", line 4102, in __getitem__
    indexer = self.columns.get_loc(key)
              ^^^^^^^^^^^^^^^^^^^^^^^^^
  File "C:\Users\Hubert\AppData\Local\Programs\Python\Python311\Lib\site-packages\pandas\core\indexes\base.py", line 3812, in get_loc
    raise KeyError(key) from err
KeyError: 'taxonRank'

I initially thought this was an issue with morphospecies IDs from fiftyone, but it doesn't work on files ID'd to order-level that it worked on before. I recently synced all my scripts with github, so perhaps the script was changed since my last sync.

Hubertszcz, 2025-07-28:
[metadata.json](https://github.com/user-attachments/files/21475837/metadata.json)
[samples.json](https://github.com/user-attachments/files/21475838/samples.json)

Here is the data I am trying to turn into a csv

Hubertszcz, 2025-07-28:
[metadata.json](https://github.com/user-attachments/files/21475863/metadata.json)
[samples.json](https://github.com/user-attachments/files/21475862/samples.json)

Here is the order-level version of the same data, which I successfully turned into a csv in the past, but can no longer.

Hubertszcz, 2025-07-28:
[SpeciesList_CountryPanama_TaxaInsecta_Morphospecies.csv](https://github.com/user-attachments/files/21477141/SpeciesList_CountryPanama_TaxaInsecta_Morphospecies.csv)

Panama insects species list augmented with possible morphospecies.

quitmeyer, 2025-08-06:
@Hubertszcz  working on this a bit now. Added more description to the title.

Problem:
The key challenge here is that if we add cool new taxonomies that lie outside of the species list, we get errors. The reason we usually rely on the species list is because to make the CSV darwinCORE compatible, we need the special taxaCodes they use. You also want to be able to add kinda more rare taxonomy like "TRIBE" which GBIF doesn't have.

We also have non-taxonomic tags like "ERROR"

Possible Solutions:
Perhaps a solution to this would be to add checks to try to go as deep in a taxonomic rank as we have values for in an official species list (thus excluding morphospecies) and use that to assign the darwinCORE taxon code while still allowing the morphospecies tags

quitmeyer, 2025-08-06:
I also tried adding numbers to my morphospecies to see if maybe that caused errors?

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

but nope, still went ok.

you can notice that it does leave the taxonID and such blank, and i can work on having that keep the last legit taxa

quitmeyer, 2025-08-06:
It now also adds "ERROR" as a common name if it is marked as an ERROR

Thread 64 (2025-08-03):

Running create dataset script says object is missing 'ground height'

briannaljohns, 2025-08-03:
When running Mothbot_CreateDataset.py, I get an error message (see below as text) that says that the "Sample has no field "ground_height." I'm unsure if the ground_height metadata is being lost during this process, but it prevents the entire script from running and opening FiftyOne.

 1 image files updated
 100% |████████████████████████████████████████████████████████████████████████████████████████████████████████| 235/235 [536.3ms elapsed, 0s remaining, 438.2 samples/s]
layerMomoto_2025_07_29__21_01_21_HDR0.jpg                                                                                                                 
layerMomoto_2025_07_29__21_02_05_HDR0.jpg
layerMomoto_2025_07_29__21_03_06_HDR0.jpg
layerMomoto_2025_07_29__21_04_06_HDR0.jpg
layerMomoto_2025_07_29__21_05_06_HDR0.jpg
layerMomoto_2025_07_29__21_06_06_HDR0.jpg
   2% |██/-----------------------------------------------------------------------------------------------------|   5/235 [10.3ms elapsed, 474.7ms remaining, 484.5 samples/s]
Traceback (most recent call last):
  File "/Users/brianna/miniconda3/lib/python3.12/site-packages/fiftyone/core/odm/mixins.py", line 123, in get_field
    return super().get_field(field_name)
           ^^^^^^^^^^^^^^^^^^^^^^^^^^^^^
  File "/Users/brianna/miniconda3/lib/python3.12/site-packages/fiftyone/core/odm/document.py", line 328, in get_field
    return getattr(self, field_name)
           ^^^^^^^^^^^^^^^^^^^^^^^^^
AttributeError: 'samples.688e4354e87454eac9ac7abc' object has no attribute 'ground_height'

During handling of the above exception, another exception occurred:

Traceback (most recent call last):
  File "/Users/brianna/miniconda3/lib/python3.12/site-packages/fiftyone/core/document.py", line 161, in get_field
    value = self._doc.get_field(field_name)
            ^^^^^^^^^^^^^^^^^^^^^^^^^^^^^^^
  File "/Users/brianna/miniconda3/lib/python3.12/site-packages/fiftyone/core/odm/mixins.py", line 125, in get_field
    raise AttributeError(
AttributeError: Sample has no field 'ground_height'

During handling of the above exception, another exception occurred:

Traceback (most recent call last):
  File "/Users/brianna/Documents/GitHub/Mothbox/AI/Mothbot_CreateDataset.py", line 1080, in <module>
    thepatch_dataset = generate_patch_dataset(dataset)
                       ^^^^^^^^^^^^^^^^^^^^^^^^^^^^^^^
  File "/Users/brianna/Documents/GitHub/Mothbox/AI/Mothbot_CreateDataset.py", line 826, in generate_patch_dataset
    ground_height=sample.ground_height,
                  ^^^^^^^^^^^^^^^^^^^^
  File "/Users/brianna/miniconda3/lib/python3.12/site-packages/fiftyone/core/sample.py", line 46, in __getattr__
    return super().__getattr__(name)
           ^^^^^^^^^^^^^^^^^^^^^^^^^
  File "/Users/brianna/miniconda3/lib/python3.12/site-packages/fiftyone/core/document.py", line 44, in __getattr__
    return self.get_field(name)
           ^^^^^^^^^^^^^^^^^^^^
  File "/Users/brianna/miniconda3/lib/python3.12/site-packages/fiftyone/core/sample.py", line 99, in get_field
    return super().get_field(field_name)
           ^^^^^^^^^^^^^^^^^^^^^^^^^^^^^
  File "/Users/brianna/miniconda3/lib/python3.12/site-packages/fiftyone/core/document.py", line 163, in get_field
    raise AttributeError(
AttributeError: Sample has no field 'ground_height'
(base) brianna@MacBook-Air-5 ~ %

quitmeyer, 2025-09-04:
That happens when the metadata is not connected correctly. but i have updated the script to not crash anymore if the metadata isnt connected

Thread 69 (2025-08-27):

only copying one file

quitmeyer, 2025-08-27:
From Mariana:

We saw that this is now available:
https://digital-naturalism-laboratories.github.io/Mothbox/docs/usage/configure/
THANK YOU!!!!!
Things we figured out:
 Where to setup self-startup times and durations for Raspberry Pi (schedule_setings.csv)
 To "activate" the schedule by calling Scheduler.py
 To call Scheduler.py on Crontab
 To call Atractor_On.py on Crontab
 To call Take_Picture.py on Crontab
Remaining Questions:
1) We used the normal Backup setup that came with the original files (which was being called from crontab) but it is not copying all pictures to the usb stick. It is only copying one from each day. How do we fix this?
2) The single internal blacklight that was recommended but it is a little weak. We instead ziptied an external blacklight (something like this) to the mothbox but got rolling shutter issues. In our own implementation, with the Arducam Hawkeye (which was not great), we figured out we could set a shutter speed of 8333 ms to cancel out the rolling-shutter effects. We tried looking at the file called "camera_settings.csv) but couldn't figure out where to mess with the shutter speed call to libcamera or picamera.

**

quitmeyer, 2025-08-28:
There might be a problem with the new version of shutil,
https://stackoverflow.com/questions/1868714/how-do-i-copy-an-entire-directory-of-files-into-an-existing-directory-using-pyth

it looks like you need to add a flag now if some of those directories exist. that could be a source of the problem

quitmeyer, 2025-08-29:
I think I found the bug!! I added the flag I mentioned before and it seemed to have solved the one file per night error!

For right now, to solve this error

Copy all the file contents from this
https://github.com/Digital-Naturalism-Laboratories/Mothbox/blob/main/Firmware/Backup_Files.py

And replace the backup script that's on the mothbox Raspberry pi!

I will work on a full new mothbox image that will have this fix built in, and I'll post here when that's ready but for now this is the quickest way to patch this error!

frankpablo, 2025-08-29:
@quitmeyer : Thanks for the feedback! I

  1. About the Backup:  updated the Backup, which I'll test and report (I'm glad you recommended that change because that's exactly where I was hoping the issue would be)

  2. About Rolling shutter: I had a typo in the message we sent you earlier… I meant: 8.333 ms (or 1/120 of a second). This is because I wanted to try the externally powered blacklight, which has the same wavelength as the one you recommend but needs AC to run (which causes the 60Hz flickering). As you say, it might be better NOT to try to do manual adjustments to the exposure time, so I think the most reasonable thing to do first is to try to run more lights off of the 12V DC battery and see if that does it.

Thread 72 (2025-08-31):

log file says camera stops working after date/time are set

peetersmark, 2025-08-31:
**Describe the bug**
No photos are taken, ring lights do not turn on, relay channel 2 does not click. The UV attractor light DOES turn on relay channel 3 clicks.

**To Reproduce**
After initial install and boot up, change location, timezone (reboot) and run SetTimeandDate.py
Trying to take photos both from the cron schedule and by manually clicking the TakePhoto.py result in no photos being taken. The UV light turns on but that is all. The log file TakePhoto_log.txt seems to indicate that before the time was set a few photos were saved, but they are not in the folders so I am not sure if this is true since I don't know what would have deleted the images if they did exist.

**Expected behavior**
Photos should appear in the photos folder, and TakePhoto_log.txt should not have errors.

**Additional context**
I saw this both with 4.16.2 and 4.16.3. This is a new set up and I am a new user. I have not seen any photos. V4.16.2 ran all night , turning the UV attractor light on and off according to the schedule, but the ring lights never turn on and no photos are seen. I will attach the log file from the v4.16.3 install. I notice the file claims that images were saved before I updated the time/date. after that the following errors are logged:
Warning: Unknown setting: HDR. Ignoring.
Warning: Unknown setting: HDR_width. Ignoring.
Warning: Unknown setting: AutoCalibration. Ignoring.
Warning: Unknown setting: AutoCalibrationPeriod. Ignoring.
Warning: Unknown setting: ImageFileType. Ignoring.
Warning: Unknown setting: VerticalFlip. Ignoring.
Warning: Unknown setting: Name. Ignoring.
Traceback (most recent call last):
  File "/home/pi/Desktop/Mothbox/TakePhoto.py", line 761, in <module>
    picam2 = Picamera2()
             ^^^^^^^^^^^
  File "/usr/lib/python3/dist-packages/picamera2/picamera2.py", line 246, in __init__
    camera_num = self.global_camera_info()[camera_num]['Num']
                 ~~~~~~~~~~~~~~~~~~~~~~~~~^^^^^^^^^^^^
IndexError: list index out of range

[TakePhoto_log.txt](https://github.com/user-attachments/files/22067720/TakePhoto_log.txt)

peetersmark, 2025-08-31:
The start of the log file (before I changed the time/date on the Pi) claims the flash was used, but in real life the ring lights have never turned on. I hope that helps.

peetersmark, 2025-08-31:
update - the time change setting was just a coincidence.
I started with a fresh image and let it run and did not change anything. the log file shows the same initial "successes" and then starts failing. See attached NEW log file from a fresh install and just letting the mothbox run without making any changes.

[TakePhoto_log.txt](https://github.com/user-attachments/files/22067858/TakePhoto_log.txt)

quitmeyer, 2025-08-31:
That error indicates your pi isn't detecting your camera.

Perhaps the cable came loose or was installed backwards or something? Also
make sure the camera is plugged into the camera 0 port

I have seen times where the camera was also squished due to weird placement
and so it couldn't move its autofocusing lens and then stops itself and
then also acts like there's no camera detected.

__

Sincerely,
Dr. Andrew James Quitmeyer
Director of Digital Naturalism Laboratories
Affiliate Professor, University of Washington - Human Centered Design and
Engineering
www.dinalab.net

On Sun, Aug 31, 2025, 12:14 Mark G. Peeters ***@***.***>
wrote:

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

quitmeyer, 2025-08-31:
Those first sets of photos in the log I think are actually just from
leftovers of wheni created the image. You might notice they have the
mothbox name as "alerttollo" and were taken 8/29

Then when we get to more recent ones it seems like they all have errors.

Did your setup ever save a photo anywhere?

Can you run the takephoto.py script manually?

__

Sincerely,
Dr. Andrew James Quitmeyer
Director of Digital Naturalism Laboratories
Affiliate Professor, University of Washington - Human Centered Design and
Engineering
www.dinalab.net

On Sun, Aug 31, 2025, 12:46 Mark G. Peeters ***@***.***>
wrote:

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

peetersmark, 2025-08-31:
FIXED
turns out the camera was shipped with the pi5 cable installed backwards!!! that's what I get for trusting it was assembled correctly at the factory. LOL it's now snapping pics!! I am soo excited to see what I get tonight.

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

Closed 2025-08-31.

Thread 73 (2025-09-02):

Mothbot_CreateDataset.py does not create files or launch Fiftyone

peetersmark, 2025-09-02:
**Describe the bug**
when running Mothbot_CreateDataset.py, the script ends and does not create the 3 files (one csv and two jason) or load Fiftyone web interface. The images file do have their Exif tags updated, so that part is working.

**To Reproduce**
running Mothbot_CreateDataset.py on win10, in virtual studio code.

**Expected behavior**
3 files should be created in the photo folder and fiftyone web interface should launch

**Additional context**
Attached is the terminal log file, I do see some errors about:
AttributeError: 'samples.68b742c2d23af69760a23baa' object has no attribute 'ground_height'

[terminal log for Mothbot_CreateDataset-py.txt](https://github.com/user-attachments/files/22102712/terminal.log.for.Mothbot_CreateDataset-py.txt)

quitmeyer, 2025-09-03:
Here's what to do:

Get an exact copy of the CSV from the GitHub

Make a new row for your deployment
And fill out all the columns of that row

Here's the tricky part:

To connect your data to
The appropriate row in the csv, it looks to match the deployment name

If you look on that page about organizing data it shows you to put your
data into a set of folders named after the area and point and mothbox name.

So make sure those are formatted the same as your CSV entries and then it
should be able to connect them. (Again working on making this a bit easier
in the future)

__

Sincerely,
Dr. Andrew James Quitmeyer
Director of Digital Naturalism Laboratories
Affiliate Professor, University of Washington - Human Centered Design and
Engineering
www.dinalab.net

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

peetersmark, 2025-09-03:
thanks for this info. I really appreciate the help. I did try to follow the data organization but it seem i have some things wrong.

**about the folder structure**
Should I NOT use the absolute references in the Mothbot_CreateDataset.py?
My current settings for this file look like this:

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

following the naming convention I named my deployment folder: kzoo_506BkYardMaple_yearlyBrema_2025-08-31
AND
this was the name I added to the CSV file in last field “deployment name”

this was my folder structure:

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

**SO i think you are saying I need to fix these things?**
1. put the current deployment folder inside parent folder called USA
2. rename the Nightly Folders like this?
| a. 2025-08-31 => 2025-08-01
| b. 2025-09-01 => 2025-08-02
| c. 2025-09-02 => 2025-08-03
3. rename and move the Yolo file like this:
| a. rename yolo11m_4500_imgsz1600_b1_2024-01-18.pt => yearlyBrema_2025-08-31-17-00-00.json
| b. AND move a copy of this into EACH nightly folder
4. rename and more the metadata file like this:
| a. rename Mark-Mothbox_Main_Metadata-test2.csv => yearlyBrema_2025-08-31-17-00-00_metadata.json
| b. AND move a copy of this into EACH nightly folder

quitmeyer, 2025-09-03:
Sorry busy with something but super quick:

Absolute paths looks great!

1 and 2 - yes!

3 and 4 - no! You don't need to change those files or organize the metadata
file or the YOLO file in any special way, they just need to get pointed to
in the script.

By the way have you tried the mothbot_ui.py script for a basic user
interface?

__

Sincerely,
Dr. Andrew James Quitmeyer
Director of Digital Naturalism Laboratories
Affiliate Professor, University of Washington - Human Centered Design and
Engineering
www.dinalab.net

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

quitmeyer, 2025-09-04:
@peetersmark good catch on those deadlinked pdfs!
 i fixed them

also i just fixed the create_dataset script so that if you don't have metadata connected, it will just ignore it! Just tested with a couple batches of randomly named datasets and worked fine, get the latest version of the code off github. so that should solve your problem! ill close this issue, but feel free to keep commenting or open if the same problem comes back.

peetersmark, 2025-09-05:
Thanks the new script is able to open fiftyone! Yeah

BUT what I am seeing is that no metadata is being read. it must be that only the field for ground height was giving an error.

I did make the changes to the folder structure (1 and 2), and now I am wondering why is it not able to read my metadata CSV file. I must have something wrong but I can see it. attached is the CSV where I have attempted to add a line at the top for my deployment. my data is in row 2. and the file is called with the absolute path like this
METADATA_PATH = r'D:\mothbox\DATA\gbif-files\Mark-Mothbox_Main_Metadata-test2.csv'

Can you see what I am doing wrong?

[Mark-Mothbox_Main_Metadata-test1.csv](https://github.com/user-attachments/files/22162919/Mark-Mothbox_Main_Metadata-test1.csv)

quitmeyer, 2025-09-05:
>
> it must be that only the field for ground height was giving an error.

Nah, that's just the first line where the code starts looking at the
metadata, so it fails first.

 Ill take a look at your stuff and let you know!

__

Sincerely,
Dr. Andrew James Quitmeyer
Director of Digital Naturalism Laboratories
Affiliate Professor, University of Washington - Human Centered Design and
Engineering
www.dinalab.net

quitmeyer, 2025-09-05:
I also tweaked the code so your original format would have been detected,
and simpified the detecting of matching metadata overall and made more
robust

__

Sincerely,
Dr. Andrew James Quitmeyer
Director of Digital Naturalism Laboratories
Affiliate Professor, University of Washington - Human Centered Design and
Engineering
www.dinalab.net

On Thu, 4 Sept 2025 at 21:27, Andrew Quitmeyer (Dinalab) <
***@***.***> wrote:

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

peetersmark, 2025-09-05:
> i renamed it for ya! try it!

I am not sure where to see the changes you made?

But the new script works with my original format, and i am seeing the data on fiftyone now and in the CSV export.

Thanks, this is working great now! To bad I am so late in the year for Michigan, I am not seeing many cute moths and bugs. So far the shed is the best place to see them.

quitmeyer, 2025-09-05:
Ah weird maybe my file didn't save

I basically just changed the entries underneath each of those columns to
match exactly like "kzoo" instead of Kansaszoo or whatever :)

__

Sincerely,
Dr. Andrew James Quitmeyer
Director of Digital Naturalism Laboratories
Affiliate Professor, University of Washington - Human Centered Design and
Engineering
www.dinalab.net

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

peetersmark, 2025-09-06:
OH! so the **area** and **point** in the CSV file need to match the **project** and **site** of the deployment name? I must have missed that connection.

Closed 2025-09-04.

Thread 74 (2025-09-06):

load_camera_settings root not defined

bkubicek, 2025-09-06:
in Take_Photo.py, routine loadCameraSettings
there is this code:

       for path in external_media_paths:
        if(found==0):
            files=os.listdir(path) #don't look for files recursively, only if new settings in top level
            if "camera_settings.csv" in files:
                file_path = os.path.join(root, "camera_settings.csv")
                print(f"Found settings on external media: {file_path}")
                found=1
                break
            else:
                print("No external settings here...")
                file_path=default_path

The variable root is locally undefined, and probably should be replaced by "path"

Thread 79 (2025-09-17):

Mothbot_UI.py hangs on Pick Deployment Folder

peetersmark, 2025-09-17:
**Describe the bug**
running Mothbot_UI.py opens a browser window, when clicking the button "Pick Deployment Folder" it just begins counting seconds and "processing". The other tabs allow drag and drop for files, but this first tab does not allow for any inputs. It just hangs.

**To Reproduce**
running Mothbot_UI.py on win10, in virtual studio code.

**Expected behavior**
allow user to choose deployment folder.

**Additional context**
current files as of 2025-09-17 noon EST

peetersmark, 2025-09-17:
thanks for all the hard work you are doing!
Since all six of these scripts call same or similar paths is there a way to have them reference a single file that could hold the inputs. Then we would only need to change that one file. I am thinking it should contain:

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

I think those are the only parts of the script we need to change for our local environments.

quitmeyer, 2025-09-18:
Hey @peetersmark , it should not hang now when you choose a folder! We tested on pc and mac!

peetersmark, 2025-09-18:
oh very cool, I was able to select my folder and I was able to follow along until "create dataset"
at which point I got the follow error:

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

I looked up character '\u2705' which is:
Unicode for the White Heavy Check Mark emoji (✅)
But where would it be seeing that?

quitmeyer, 2025-09-18:
Amazing work! thanks for testing that!

Ill chase down that encoding error and try to fix it or add safeguards!

quitmeyer, 2025-09-18:
By the way, that checkmark comes from the output logs when running the different functions:

```   
                   output_log += f"\n❌ Identification for {folder} exited with error code {process.returncode}\n"
            else:
                output_log += f"✅ Identification completed for {folder}\n"
```

but what's odd is that those similar type of comments run on each function, so i would have expected it to have that error during the detection or ID too

do you see green checks in the console in the GUI when you run the other functions?

quitmeyer, 2025-09-19:
Hey good news! Check out the latest commit for a way better UI that hopefully makes more sense, and I just tested the whole processing path and it seems to work!!

Feel free to try out the whole process @Hubertszcz @briannaljohns

im gonna close this issue since it seems like we squashed the indefinite hanging bug of the choose folder thing.

Closed 2025-09-19.

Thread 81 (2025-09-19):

Small issues with Mothbot UI

Hubertszcz, 2025-09-19:
The 'Select Species List' button doesn't work (but I can still copy-paste in my species list file path)

Need a way to run 'Create dataset' on multiple nights, or at least a way to kill 51 so I can easily create a dataset for the next night in the deployment without fulling restarting Mothbot UI and re-inputting the file paths.

Also, how do I open a dataset that has already been created?

quitmeyer, 2025-09-19:
Fixed in latest version

Hubertszcz, 2025-09-20:
Thank you for the updates, I'll add one more issue here because I think it occurred during this update:

The Insert Exif tab in the UI gives the following error (it used to work fine with the same metadata/species list files):

❌  Insert Exif  for D:\MothboxData_Hubert\data\Panama\Hoya_168m_doubleParina_2025-01-26\2025-01-27 exited with error code 1
---🔍 Running Insert Exif for D:\MothboxData_Hubert\data\Panama\Hoya_168m_doubleParina_2025-01-26\2025-01-28 ---
adding exif info to the patches
Starting script to  add metadata to raw iamges
Looking in this folder for MothboxData: D:\MothboxData_Hubert\data\Panama\Hoya_168m_doubleParina_2025-01-26\2025-01-28
Found  1 dated folders potentially full of mothbox data
Found  0 pairs of images and HUMAN detection data insert exif
example human detection and json pair:
Found  250 pairs of images and BOT detection data to insert exif
example human detection and json pair:
('D:\\MothboxData_Hubert\\data\\Panama\\Hoya_168m_doubleParina_2025-01-26\\2025-01-28\\doubleParina_2025_01_28__19_01_24_HDR0.jpg', 'D:\\MothboxData_Hubert\\data\\Panama\\Hoya_168m_doubleParina_2025-01-26\\2025-01-28\\doubleParina_2025_01_28__19_01_24_HDR0_botdetection.json')
processing Human Detections.........
processing BOT Detections.........
Traceback (most recent call last):
  File "C:\Users\Hubert\Desktop\Biodiversity Monitoring\MothBox\Mothbox Github\Mothbox\AI\Mothbot\Mothbot_InsertExif.py", line 751, in <module>
    connect_metadata_matched_img_json_pairs(
  File "C:\Users\Hubert\Desktop\Biodiversity Monitoring\MothBox\Mothbox Github\Mothbox\AI\Mothbot\Mothbot_InsertExif.py", line 684, in connect_metadata_matched_img_json_pairs
    load_anylabeling_data(json_path, image_path, exiftagger)
  File "C:\Users\Hubert\Desktop\Biodiversity Monitoring\MothBox\Mothbox Github\Mothbox\AI\Mothbot\Mothbot_InsertExif.py", line 126, in load_anylabeling_data
    long= data['longitude']
          ~~~~^^^^^^^^^^^^^
KeyError: 'longitude'

quitmeyer, 2025-09-20:
Hmmm weird the error mames it just look like it hadn't gotten the metadata tab run yet

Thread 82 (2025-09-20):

[FEATURE] different automatic file path for deployment folder, species list, metadata file

Hubertszcz, 2025-09-20:
Not a problem, just a suggestion on a slightly more friendly user interface.

When I click 'Pick Deployment Folder' or 'Select Species List' in the Mothbot UI, it automatically starts my search in the most recent file path I used. Because my deployments and my species list live in different places on different hard drives, that means more clicking to get to the right place. If it is an easy fix, I suggest having a separate file path history for each of the three file search buttons on Mothbot UI, so I am automatically prompted to search for my species list where I have previously searched for species lists (or where the sample one lives in the github AI folder), and automatically put in the same file path for deployments where I searched for a deployment to process before.

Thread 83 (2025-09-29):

EXIF in photo default to Bali coordinates

Hubertszcz, 2025-09-29:
I ran insert Exif on Mothbot and my photos come up with Bali GPS coordinates instead of the ones pulled from the metadata sheet.

quitmeyer, 2025-09-30:
Do your json files have the incorrect GPS as well? Like if you view them in the labeller does it show the correct coords or incorrect?

quitmeyer, 2025-09-30:
should be fixed with latest github

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

Closed 2025-09-30.

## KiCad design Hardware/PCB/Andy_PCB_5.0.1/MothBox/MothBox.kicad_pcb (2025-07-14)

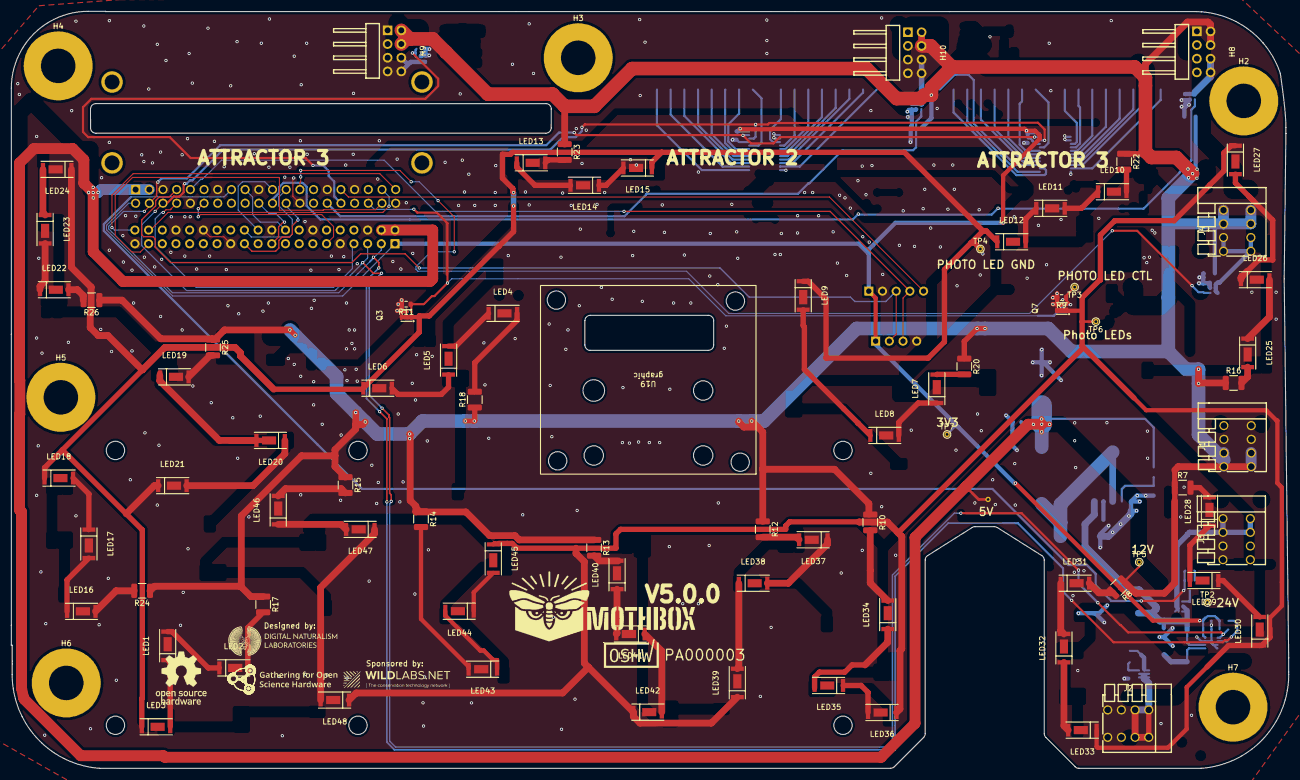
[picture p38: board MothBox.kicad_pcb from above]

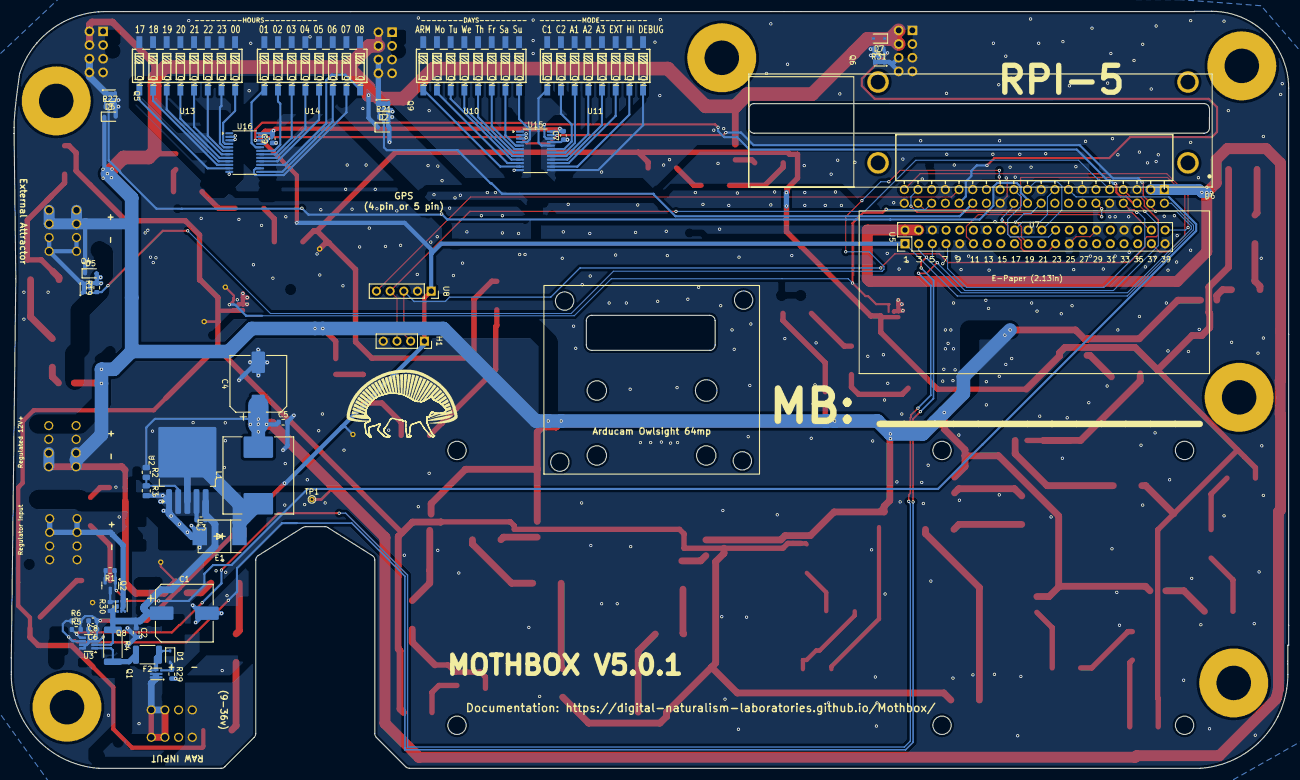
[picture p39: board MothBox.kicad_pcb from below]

Board: 2 copper layers, 237.0 x 140.5 mm, 139 parts (51 on the bottom side), 121 nets.

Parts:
B1: graphic; Talentcell
C1: 470uF 50V; CP_Elec_10x12.5
C2, C3, C5: 0.1uF 50V; R_0603_1608Metric
C4: 330uF 50V; CP_Elec_10x10
C6, C7, C9: 0.1uF; C_0603_1608Metric
C8: 10uF; C_0603_1608Metric
D1: 10V; D_SOD-323
D2, D5, D6, D7: ESD12VD3B-TP; D_SOD-323
E1: SK54C; SMC_L6.9-W5.9-LS8.0-RD
F2: 6A trip; Fuse_1812_4532Metric
H1: GPS 4 pin 2.54-1*4P; PinSocket_1x04_P2.54mm_Vertical
H2, H3, H4, H5, H6, H7: MountingHole_1/4inbolt; MountingHole_6.4mm_M6_Pad
H8, H9, H10: PZ254R-12-8P; HDR-TH_8P-P2.54-H-M-R2-C4-S2.54
J1, J2, J3, J4: DB141V-2.54-4P; CONN-TH_4P-P2.54_DIBO_DB141V-2.54-4P
L1: 5A 47uH; L_Chilisin_BMRG00131360
LED1, LED2, LED3, LED4, LED5, LED6, LED7, LED8, LED9, LED10, LED11, LED12, LED13, LED14, LED15, LED16, LED17, LED18, LED19, LED20, LED21, LED22, LED23, LED24, LED25, LED26, LED27, LED28, LED29, LED30, LED31, LED32, LED33, LED34, LED35, LED36, LED37, LED38, LED39, LED40, LED41, LED42, LED43, LED44, LED45, LED46, LED47, LED48: XL-5730UWC-05; LED-SMD_3P-L5.7-W3.0-RD
Q1, Q8: JMTV210P02A; U-DFN2020-6_L2.0-W2.0-P0.65-BL
Q2: AO3400A; SOT-23
Q3, Q4, Q5, Q6, Q7, Q9: YJQ10N2A; U-DFN2020-6_L2.0-W2.0-P0.65-BL
R1, R9, R11, R19, R21, R27, R29, R30, R31: 10K; R_0603_1608Metric
R2: 10K; R_0805_2012Metric
R3: 3.3K; R_0805_2012Metric
R4: 0.1R/1%; R_2512_6332Metric
R5, R6: 4.7K; R_0603_1608Metric
R7, R8, R10, R12, R13, R14, R15, R16, R17, R18, R20, R22, R23, R24, R25, R26: 18R; R_1210_3225Metric
TP1: 5V_test; TestPoint_THTPad_D1.0mm_Drill0.5mm
TP2: 24V_test; TestPoint_THTPad_D1.0mm_Drill0.5mm
TP3: LEDCTRL; TestPoint_THTPad_D1.0mm_Drill0.5mm
TP4: LED L GND; TestPoint_THTPad_D1.0mm_Drill0.5mm
TP5: 12V_test; TestPoint_THTPad_D1.0mm_Drill0.5mm
TP6: LED R GND; TestPoint_THTPad_D1.0mm_Drill0.5mm
TP7: 3V3_test; TestPoint_THTPad_D1.0mm_Drill0.5mm
U2: XL4015E1; TO-263-5_TabPin3
U3: INA219BIDCNT; SOT-23-8
U5: RASPBERRY_PI_5; EPAPER_PinHeader_2x20_P2.54mm_Vertical
U6: RASPBERRY_PI_4B_4GB; MODULE_RASPBERRY_PI_4B_4GB_Sideways
U7: Female Inv Socket Pi 2.54-2*20; HDR-TH_40P-P2.54-H-F-R2-C20-W8.5
U8: GPs 5 pin PM2.54-1*5; PinSocket_1x05_P2.54mm_Vertical
U10: Days; SW-SMD_SMXS-08K-TP
U11: Modes; SW-SMD_SMXS-08K-TP
U13: Hours1; SW-SMD_SMXS-08K-TP
U14: Hours2; SW-SMD_SMXS-08K-TP
U15, U16: PCA9535PW; TSSOP-24_4.4x7.8mm_P0.65mm
U19: graphic; Arducam Owlsight

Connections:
+3.3V: C6.1, C7.2, C8.1, C9.2, H1.1, R5.2, R6.2, TP7.1, U3.4 (VS), U5.1 (3V3), U5.17 (3V3), U7.2, U8.1, U15.24 (VDD), U16.21 (A0), U16.24 (VDD)
+5V: C4.1, C5.1, L1.2, R2.1, TP1.1, U5.2 (5V), U5.4 (5V), U7.1, U7.3
+12V: D2.1 (K), D5.1 (K), D6.1 (K), D7.1 (K), H8.2, H8.4, H9.2, H9.4, H10.2, H10.4, J1.1, J1.2, J4.3, J4.4, R7.1, R8.1, R10.1, R12.1, R13.1, R14.1, R15.1, R16.1, R17.1, R18.1, R20.1, R22.1, R23.1, R24.1, R25.1, R26.1, TP5.1
+24V: C1.1, C2.1, C3.1, Q8.4 (S), Q8.7 (S), R4.1, R30.1, TP2.1, U2.5 (VIN), U3.2 (IN-)
/GPS and Switches/Armed/Disarmed: U10.16, U15.4 (IO0_0)
/GPS and Switches/Attractor_1: U11.12, U15.17 (IO1_4)
/GPS and Switches/Attractor_2: U11.13, U15.16 (IO1_3)
/GPS and Switches/Attractor_3: U11.14, U15.15 (IO1_2)
/GPS and Switches/C1: U11.15, U15.14 (IO1_1)
/GPS and Switches/C2: U11.16, U15.13 (IO1_0)
/GPS and Switches/Fri: U10.11, U15.9 (IO0_5)
/GPS and Switches/HI/LOW_PWR: U11.10, U15.19 (IO1_6)
/GPS and Switches/Hour_1: U13.16, U16.4 (IO0_0)
/GPS and Switches/Hour_2: U13.15, U16.5 (IO0_1)
/GPS and Switches/Hour_3: U13.14, U16.6 (IO0_2)
/GPS and Switches/Hour_4: U13.13, U16.7 (IO0_3)
/GPS and Switches/Hour_5: U13.12, U16.8 (IO0_4)
/GPS and Switches/Hour_6: U13.11, U16.9 (IO0_5)
/GPS and Switches/Hour_7: U13.10, U16.10 (IO0_6)
/GPS and Switches/Hour_8: U13.9, U16.11 (IO0_7)
/GPS and Switches/Hour_9: U14.16, U16.15 (IO1_2)
/GPS and Switches/Hour_10: U14.15, U16.14 (IO1_1)
/GPS and Switches/Hour_11: U14.14, U16.13 (IO1_0)
/GPS and Switches/Hour_12: U14.13, U16.16 (IO1_3)
/GPS and Switches/Hour_13: U14.12, U16.17 (IO1_4)
/GPS and Switches/Hour_14: U14.11, U16.18 (IO1_5)
/GPS and Switches/Hour_15: U14.10, U16.19 (IO1_6)
/GPS and Switches/Hour_16: U14.9, U16.20 (IO1_7)
/GPS and Switches/INT/EXT_Attractor: U11.11, U15.18 (IO1_5)
/GPS and Switches/Mon: U10.15, U15.5 (IO0_1)
/GPS and Switches/Sat: U10.10, U15.10 (IO0_6)
/GPS and Switches/Sun: U10.9, U15.11 (IO0_7)
/GPS and Switches/Test_Debug: U11.9, U15.20 (IO1_7)
/GPS and Switches/Thur: U10.12, U15.8 (IO0_4)
/GPS and Switches/Tue: U10.14, U15.6 (IO0_2)
/GPS and Switches/Wed: U10.13, U15.7 (IO0_3)
/RPI5/GPIO4/GPIO_GCKL: U5.7 (GPIO4/GPIO_GCKL), U7.8
/RPI5/Save for eink_11: U5.11 (GPIO17/GPIO_GEN0), U7.12
/RPI5/Save for eink_18: U5.18 (GPIO24/GPIO_GEN5), U7.17
/RPI5/Save for eink_19: U5.19 (GPIO10/SPI_MOSI), U7.20
/RPI5/Save for eink_22: U5.22 (GPIO25/GPIO_GEN6), U7.21
/RPI5/Save for eink_23: U5.23 (GPIO11/SPI_SCLK), U7.24
/RPI5/Save for eink_24: U5.24 (GPIO8/~SPI_CE0), U7.23
/RPI5/Save for relay: U5.38 (GPIO20), U7.37
/RPI5/Save for relay 2: U5.40 (GPIO21), U7.39
/RPI5/Save for relay 3: U5.37 (GPIO26), U7.38
EN_12VReg: Q2.1 (G), R1.1, U7.15
GND: C1.2, C2.2, C4.2, C5.2, C6.2, C7.1, C8.2, C9.1, D2.2 (A), D5.2 (A), D6.2 (A), D7.2 (A), E1.2 (A), H1.4, J1.3, J1.4, J2.1, J2.2, J3.1, J3.2, Q2.2 (S), Q3.4 (S), Q3.7 (S), Q4.4 (S), Q4.7 (S), Q5.4 (S), Q5.7 (S), Q6.4 (S), Q6.7 (S), Q7.4 (S), Q7.7 (S), Q9.4 (S), Q9.7 (S), R1.2, R3.2, R9.2, R11.2, R19.2, R21.2, R27.2, R29.2, R31.2, U2.1 (GND), U3.3 (GND), U3.7 (A0), U3.8 (A1), U5.6 (GND), U5.9 (GND), U5.14 (GND), U5.20 (GND), U5.25 (GND), U5.30 (GND), U5.34 (GND), U5.39 (GND), U7.5, U7.10, U7.13, U7.19, U7.26, U7.29, U7.33, U7.40, U8.2, U10.1, U10.2, U10.3, U10.4, U10.5, U10.6, U10.7, U10.8, U11.1, U11.2, U11.3, U11.4, U11.5, U11.6, U11.7, U11.8, U13.1, U13.2, U13.3, U13.4, U13.5, U13.6, U13.7, U13.8, U14.1, U14.2, U14.3, U14.4, U14.5, U14.6, U14.7, U14.8, U15.2 (A1), U15.3 (A2), U15.12 (VSS), U15.21 (A0), U16.2 (A1), U16.3 (A2), U16.12 (VSS)
GPS_PPS: U7.31, U8.5
GPS_RX: H1.2, U7.7, U8.3
GPS_TX: H1.3, U7.9, U8.4
unnamed: D1.2 (A), Q1.3 (G), R29.1
unnamed: D1.1 (K), F2.1, Q1.4 (S), Q1.7 (S)
unnamed: E1.1 (C), L1.1, U2.3 (SW)
unnamed: H8.6, H8.8, Q5.1 (D), Q5.2 (D), Q5.5 (D), Q5.6 (D), Q5.8 (D)
unnamed: H9.6, H9.8, Q6.1 (D), Q6.2 (D), Q6.5 (D), Q6.6 (D), Q6.8 (D)
unnamed: H10.6, H10.8, Q9.1 (D), Q9.2 (D), Q9.5 (D), Q9.6 (D), Q9.8 (D)
unnamed: J2.3, J2.4, Q1.1 (D), Q1.2 (D), Q1.5 (D), Q1.6 (D), Q1.8 (D)
unnamed: J3.3, J3.4, Q8.1 (D), Q8.2 (D), Q8.5 (D), Q8.6 (D), Q8.8 (D)
unnamed: J4.1, J4.2, Q4.1 (D), Q4.2 (D), Q4.5 (D), Q4.6 (D), Q4.8 (D)
unnamed: LED1.2 (A), LED2.1 (K)
unnamed: LED1.1 (K), LED3.2 (A)
unnamed: LED2.2 (A), R17.2
unnamed: LED4.2 (A), R18.2
unnamed: LED4.1 (K), LED5.2 (A)
unnamed: LED5.1 (K), LED6.2 (A)
unnamed: LED7.2 (A), R20.2
unnamed: LED7.1 (K), LED8.2 (A)
unnamed: LED8.1 (K), LED9.2 (A)
unnamed: LED10.2 (A), R22.2
unnamed: LED10.1 (K), LED11.2 (A)
unnamed: LED11.1 (K), LED12.2 (A)
unnamed: LED3.1 (K), LED6.1 (K), LED9.1 (K), LED12.1 (K), LED15.1 (K), LED18.1 (K), LED21.1 (K), LED24.1 (K), Q3.1 (D), Q3.2 (D), Q3.5 (D), Q3.6 (D), Q3.8 (D), TP4.1
unnamed: LED13.2 (A), R23.2
unnamed: LED13.1 (K), LED14.2 (A)
unnamed: LED14.1 (K), LED15.2 (A)
unnamed: LED16.2 (A), R24.2
unnamed: LED16.1 (K), LED17.2 (A)
unnamed: LED17.1 (K), LED18.2 (A)
unnamed: LED19.2 (A), R25.2
unnamed: LED19.1 (K), LED20.2 (A)
unnamed: LED20.1 (K), LED21.2 (A)
unnamed: LED22.2 (A), R26.2
unnamed: LED22.1 (K), LED23.2 (A)
unnamed: LED23.1 (K), LED24.2 (A)
unnamed: LED25.2 (A), R16.2
unnamed: LED25.1 (K), LED26.2 (A)
unnamed: LED26.1 (K), LED27.2 (A)
unnamed: LED27.1 (K), LED30.1 (K), LED33.1 (K), LED36.1 (K), LED39.1 (K), LED42.1 (K), LED45.1 (K), LED48.1 (K), Q7.1 (D), Q7.2 (D), Q7.5 (D), Q7.6 (D), Q7.8 (D), TP6.1
unnamed: LED28.2 (A), R7.2
unnamed: LED28.1 (K), LED29.2 (A)
unnamed: LED29.1 (K), LED30.2 (A)
unnamed: LED31.2 (A), R8.2
unnamed: LED31.1 (K), LED32.2 (A)
unnamed: LED32.1 (K), LED33.2 (A)
unnamed: LED34.2 (A), R10.2
unnamed: LED34.1 (K), LED35.2 (A)
unnamed: LED35.1 (K), LED36.2 (A)
unnamed: LED37.2 (A), R12.2
unnamed: LED37.1 (K), LED38.2 (A)
unnamed: LED38.1 (K), LED39.2 (A)
unnamed: LED40.2 (A), R13.2
unnamed: LED40.1 (K), LED41.2 (A)
unnamed: LED41.1 (K), LED42.2 (A)
unnamed: LED43.2 (A), R14.2
unnamed: LED43.1 (K), LED44.2 (A)
unnamed: LED44.1 (K), LED45.2 (A)
unnamed: LED46.2 (A), R15.2
unnamed: LED46.1 (K), LED47.2 (A)
unnamed: LED47.1 (K), LED48.2 (A)
unnamed: Q2.3 (D), Q8.3 (G), R30.2
unnamed: R2.2, R3.1, U2.2 (FB)
unnamed: C3.2, U2.4 (VC)
unnamed: F2.2, R4.2, U3.1 (IN+)
PHOTO_LED_CTRL: Q3.3 (G), Q7.3 (G), R9.1, R11.1, TP3.1, U7.36
SCL: R5.1, U3.5 (SCL), U5.5 (GPIO3/SCL1), U7.6, U15.22 (SCL), U16.22 (SCL)
SDA: R6.1, U3.6 (SDA), U5.3 (GPIO2/SDA1), U7.4, U15.23 (SDA), U16.23 (SDA)
UV1_CTRL: Q5.3 (G), R27.1, U7.22
UV2_CTRL: Q9.3 (G), R21.1, U7.30
UV3_CTRL: Q6.3 (G), R31.1, U7.32
UV4_EX_CTRL: Q4.3 (G), R19.1, U7.25

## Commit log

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2024-05-28 tested fixed
    [Arms - Arm Direct Attach x4.dxf, Inside Harness - Cam Glare BigHole x3.dxf, Inside Harness - Cam Glare Mount x1.dxf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]
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2024-06-02 mostly renamed the file names
    [Inside Box - Cam Glare BigHole x3.dxf, Inside Box - Cam Glare Mount x1.dxf, Inside Box - Cam Glare Small x2.dxf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]
2024-06-16 Create FiltersPalabrasYWords.xlsx
    Added a custom wordlist of common short spanish and english words. It's in an excel sheet with a filter to choose what length of words and types of combinations you want
    [FiltersPalabrasYWords.xlsx]
2024-06-17 Photos now save with a unique Spanish or English word combo instead of boring serial
    [wordlist.csv]
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2024-06-28 fixed low power wifi
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2024-09-20 added model and onnx for labelling and organized
    [results.csv]
2024-10-01 Update parts.md correct 12v boost
2024-10-13 Cleaned up and Added Multibins and 3000 Model
    [results.csv]
2024-10-28 prints TOL correctly
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2024-11-12 Can detect ground truth data via VERSION field and also allows you to skip previously generated files
2024-11-13 Corrected the labelling of ID so that you can switch rank
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2024-12-20 Fixed metadata generator to work with new field sheet that makes all dates DD/MM/YYYY and converts
    also fixed wordlist
    [wordlist_original_characters.csv]
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2025-01-09 corrected TaxaArachnida
    GBIF.org (09 January 2025) GBIF Occurrence Download https://doi.org/10.15468/dl.327977
    [SpeciesList_CountryPanama_TaxaArachnida.csv]
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2025-01-13 tweaked and updated
    - Makes sure ground height is only a number (float or int) and strips away other non-numerical info
    -does parentID, eventID, occurenceID in the way hubert wants
    -creates more human accessible, but globally unique datasetID formatted like "DEPLOYMENTNAME_oid_OID"
    [Mothbox_Main_Metadata_Field_Sheet_Example.csv]
2025-01-23 Model Training with BIg sets and new big model detector
    [results.csv]
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2025-02-26 Update camera_settings.csv
    properly loads camera settings with exposure value now too
    [camera_settings.csv]
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2025-05-11 Andy made a version of the PCB moving parts to correct spots
    [GPS.kicad_sch, MCU.kicad_sch, MOSFET Control+LED's.kicad_sch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]
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2025-05-13 Added Fixed up Seeed version of the PCB
    [GPS.kicad_sch, MCU.kicad_sch, MOSFET Control+LED's.kicad_sch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]
2025-05-13 before i replace stuff with JLCPCB
    [MothBo-B_Cu.gbr, MothBo-B_Mask.gbr, MothBo-B_Paste.gbr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]
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2025-05-23 added female inverted header
    [GPS.kicad_sch, HAT+.kicad_pcb, HAT+.kicad_sch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]
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2025-05-28 made regulator switch on and off and SMD switches
    [GPS.kicad_sch, MothBox.kicad_pcb]
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2025-06-02 edited the RasPi RA part for DFM
    Changed the interior route corners from sharp angles to 1mm radius for better DFM
    [MothBox.kicad_pcb]
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2025-06-04 started adding test points, fixed current sensor should be 3.3v
    [MothBox.kicad_pcb, Power.kicad_sch]
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2025-06-05 Moved Epaper and routed epaper and relay wires
    [MothBox.kicad_pcb, RPI5.kicad_sch]
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2025-06-05 before i make the extra GPIO pinout not like the original - only relay and eink
    [MothBox.kicad_pcb]
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2025-06-05 All wired and logos except phantom ratsnest zones
    [MothBox.kicad_pcb]
2025-06-06 via pinned some errors away!
    [MothBox.kicad_pcb]
2025-06-06 cleaned most schematic and got rid of half errors in ERC
    [MothBox.kicad_pcb, Photo LEDS's.kicad_sch, Power.kicad_sch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]
2025-06-06 Only 2 DRC errors left and just about connecting some grounds that are internally connected anyway!
    [MothBox.kicad_pcb]
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2025-06-06 Fixed parts with conflicting LCSC footprints
    [BOM-MothBo.csv, BOM-MothBox.csv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]
2025-06-06 fix parts 2
    [MothBox.kicad_pcb]
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2025-06-06 fixed footprints
    [MothBox-CuBottom.gbr, MothBox-CuTop.gbr, MothBox-EdgeCuts.gbr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]
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2025-06-07 Final changes footprints before JLC
    c1 - rotate left 180
    e3 - rotate left 180
    q1 rotate l 180
    U1,U2,U6,U7 rotate 180
    u5 Epaper header - 90 right
    u16 - NOT RIGHT ANGLE should be C2897440 or C22373943
    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
    [BOM-MothBox.csv, GPS.kicad_sch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]
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2025-06-11 Renamed Software-firmware - Added Epaper display, fixed GPIO.cleanup()
    [FiltersPalabrasYWords.xlsx, camera_settings.csv, camera_settings_All_Values.csv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]
2025-06-16 fixed r2 and r3 assignments that didn't get built
    [MothBox.kicad_pcb]
2025-06-21 image 4.16.1 updates
    FIXES
    -SYNC HW CLOCK: The biggest fix was the discovery that the Hardware clock sometimes wouldn't sync directly with the system clock. Thus you could encounter a challenge when switching timezones where, if you set the time manually, and the pi seemed to have the correct time zone and time, it wouldn't go off. This is because the secret hardware clock hadn't been told these updates. I included a new, clickable script, where you can not only manually set the time, but also sync the HW clock. The pi now makes sure to sync the hw clock every time it wakes up just in case too!
    - DISARMED light up no more- There used to be a funky thing where, if the mothbox was in disarmed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
    [camera_settings.csv]
2025-07-03 Packaged libraries to be within the github folder for Mothbox PCB
    [MothBox.kicad_pcb, Mothbeam.kicad_pcb, Mothbeam.kicad_sch]
2025-07-03 Maybe these files needed saving too for paul?
    [GPS.kicad_sch, Photo LEDS's.kicad_sch, Power.kicad_sch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]
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2025-07-07 no DRC errors on Mothbeam!
    [Mothbeam.kicad_pcb, Mothbeam.kicad_sch]
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2025-07-07 adding in Andy's MothBeam 5.0.1, and interum MothBox 5.0.1
    [Adafruit INA219 STEMMA QT.brd, Adafruit INA219 STEMMA QT.sch, Adafruit_INA219_CurPowerMonitor.brd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]
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2025-07-13 Updated and fixed up some of bris scripts for exif
    [Mothbox_Main_Metadata_Field_Sheet_Example.csv]
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2025-07-14 rough outline of PCB. Lots of tidying up needed
    [MothBox.kicad_pcb, Photo_LEDs.kicad_sch, Power.kicad_sch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]
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2025-07-15 added in extra hour switch for 24hr coverage
    [GPS.kicad_sch, Mothbeam-v5.0.1.step, Photo_LEDs.kicad_sch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]
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2025-07-18 MothBox PCB updated and sent off for production. MothBeam edge edits and sent off for second production for Parkview
    [Mothbeam.kicad_pcb, Power.kicad_sch]
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2025-08-08 Made text better for mothbeam. Started new Mothbeam for UV only and WHITE GREEN BLUE
    [Mothbeam-CuBottom.gbr, Mothbeam-CuTop.gbr, Mothbeam-EdgeCuts.gbr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]
2025-08-09 Updated edge cut to make slightly wider and fix discontinuities
    [Mothbeam.kicad_pcb]
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2025-09-03 fixed that overlap
    [MothBox-CuBottom.gbr, MothBox-CuTop.gbr, MothBox-EdgeCuts.gbr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]
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2025-09-10 fixed metadata sheet to new standards
    [Mothbox_Main_Metadata_Field_Sheet_Example - Form responses 1.csv]
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2025-09-10 updated field sheet and create dataset to new version of names
    [Mothbox_Main_Metadata_Field_Sheet_Example - Form responses 1.csv]
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2025-09-15 Added UTC as a column to metadata field sheet
    [Mothbox_Main_Metadata_Field_Sheet_Example - Form responses 1.csv]
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2025-09-18 patched create dataset to get rid of encoding errors from print statements
2025-09-19 FIxed species button
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2025-09-20 made new separate firmware for v4 and v5 mothboxes
    [FiltersPalabrasYWords.xlsx, camera_settings.csv, camera_settings_All_Values.csv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]
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2025-10-02 final updates to v5.0.2 after error checking
    [GPS.kicad_sch, MothBox5.0.2.kicad_sch, Photo_LEDs.kicad_sch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]
2025-10-03 small cosmetic changes to PCB and updated Text files with current measurements from v5.0.1b testing
    [Photo_LEDs.kicad_sch]
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2025-10-06 Fixed up BOM in JLC tool
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2025-10-29 added mb 5 parts and mothbeam housing bits
    [BackGasket.stl, FrontGasket.stl, FrontLid.stl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]
2025-10-29 getting rid of really old PCB stuff we don't use
    [416131160804 (rev1).stp, 418121270804 (rev1).stp, 9774030151R (rev1).stp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]
2025-10-29 got rid of old funky version of low heat white led mothbeam
    [Mothbeam-CuBottom.gbr, Mothbeam-CuTop.gbr, Mothbeam-EdgeCuts.gbr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]
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2025-11-03 Fixing up 5.0 firmware including light sensor fix
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2025-11-14 swapped out Q1, Q8, Q10 for better specc'ed MOSFETs. Moved a few tracks around and updated CHANGELOG.txt
    [GPS.kicad_sch, MothBox_5.0.3.kicad_sch, Photo_LEDs.kicad_sch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]
2025-11-20 Passes DRC - updated cuttable jumper, updated 3v3 mosfet, updated holes for battery
    [GPS.kicad_sch, Power.kicad_sch]
2025-11-20 Fixed big capacitor library footprint
    [Power.kicad_sch]
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2025-11-27 Had to swap SW2 for a SMD version
    [Power.kicad_sch]
2025-12-04 Add BeetlePalooza-related links
    include Imageomics URL and Bucket of Bugs project repo
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2025-12-23 v5.0.4 schematic and PCB done. Ready for review
    [Adafruit INA219 STEMMA QT.brd, Adafruit INA219 STEMMA QT.sch, Adafruit_INA219_CurPowerMonitor.brd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]
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2025-12-26 renamed 24v areas to be actually 9-36v areas
    [Power.kicad_sch]
2025-12-26 Change holes from m2.5 to m3 and fully changed 24 net to 9-36v net
    [Power.kicad_sch, UV_LED_PCB.kicad_sch]
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2025-12-29 updated footprints of d1 d2 d4 to SOD 123
    [Mothbox_5.0.4-CuBottom.gbr, Mothbox_5.0.4-CuTop.gbr, Mothbox_5.0.4-EdgeCuts.gbr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]
2025-12-29 updated schematic 18V Zener from SOD-323 to SOD-123
    [Power.kicad_sch]
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2026-01-12 Mothbox Case with No Support Option! Organized lots with Pro and DIY label
    [57895-CH0015da8d-TH-TOP.tsv, 57895-CH0015da8d.tsv, Adafruit INA219 STEMMA QT.brd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]
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2026-01-18 added lip to front lid to hold it on better!
    [AllParts5x.3mf, FrontLid.stl, outershell.stl]
2026-01-18 did away with the silly offset of sides, found issue is layer time
    [FrontLid.stl, outershell.stl]
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2026-01-20 Add battery hookup guide for Mothbox Pro
    This document provides a detailed guide on how to connect and secure a 12V battery to the Mothbox Pro, including instructions for preparing the regulator and using zip ties for stability.
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2026-01-20 Fix typos and improve formatting in battery.md
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2026-02-05 Fix two broken links in insertmetadata.md
2026-02-05 Fix broken link in insertExif.md
2026-02-06 Clarify weekday and hour configuration in CSV
    Updated weekday and hour settings for clarity.
    [mothbox_settings.csv]
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2026-02-08 fixed flip on DIY
    [camera_settings.csv]
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2026-02-12 Fixed Regex to include nightly folders as "YYYY-MM-DD" or "Devicename_YYYY-MM-DD"
    [AllParts5x.3mf]
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2026-02-17 Fix f-strings in ID help
    The f was missing, so the variable name was printed
    rather than its value
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2026-03-24 Fix GitHub links in case_print.md
    Updated links to point to the correct GitHub repository for the Mothbox 3D printable case.
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2026-03-31 Enhance BOM processing instructions in manufacture.md
    Added detailed instructions for processing the Bill of Materials (BOM) and handling common errors during PCB manufacturing.
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2026-04-02 Fix link for Talentcell PB120B1 battery
    Updated the link for the Talentcell PB120B1 battery to point to Walmart.
2026-04-16 Fix GitHub link for acrylic cutting files
    Updated GitHub link for laser cutting layouts in cutparts.md.
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2026-04-30 Fix PCB link in parts.md
    Updated PCB link to point to the correct repository.
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2026-05-12 Document bootloader flashing process for Raspberry Pi
    Added instructions for flashing a special bootloader on Raspberry Pi to resolve boot issues.
2026-05-13 Update battery.md with input plug instructions
    Added note about using a female-male barrel jack cable as a replacement for the Socket-Levernut-Plug.
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2026-06-21 Include zip tie hack for screw hole issues
    Added a zip tie hack section for securing components in the mothbox.
2026-08-15 Fix typo in manufacture.md
    Corrected a typo in the instructions regarding the GENERATE button.
2026-08-23 Enhance troubleshooting documentation for hardware issues
    Added troubleshooting tips for hardware issues, including a baking soda and super glue hack for repairs.
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2026-09-15 Update ASA filament section with shrinkage note
    Added note about ASA filament shrinkage and design tolerances.
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2026-10-13 Enhance troubleshooting section with device indicators
    Added troubleshooting tips for device blinking indicators and SD card issues.
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2026-11-02 Revise Mothbox connection instructions for clarity
    Updated instructions for connecting Mothbox components, including camera and Mothbeams. Improved clarity and fixed minor grammatical issues.
